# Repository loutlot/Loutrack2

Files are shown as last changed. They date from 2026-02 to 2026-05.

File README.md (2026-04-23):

# Loutrack2

Loutrack2 is an open-source optical motion tracking stack built around Raspberry Pi camera nodes, host-side calibration tools, and a GUI workflow that is already practical for multi-camera bring-up and tracking experiments.

日本語はこちら: [README_ja.md](README_ja.md)

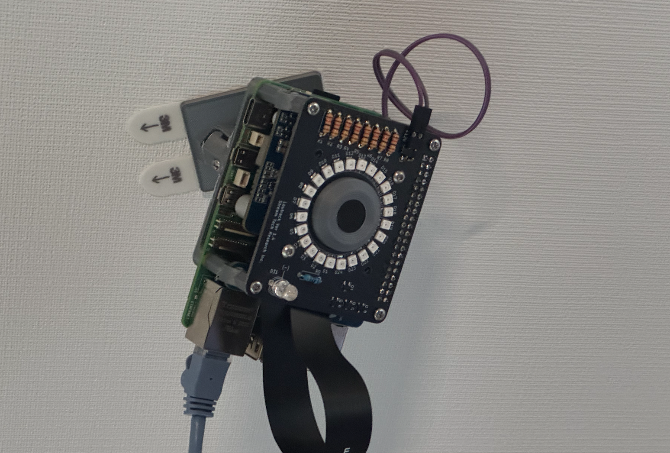
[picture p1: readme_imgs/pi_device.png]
Loutrack Pi device


## What It Is

Loutrack2 combines:

- Raspberry Pi camera capture nodes for reflective marker observation
- host-side control, calibration, and inspection tools
- multi-camera 3D reconstruction and tracking
- a GUI-first workflow for setup, tuning, capture, and review

This repository is aimed at people who want to build, understand, and extend a DIY camera-based tracking system in the open. The current project is strongest in camera bring-up, calibration, and live tracking inspection.

## What Works Today

- Pi capture nodes detect reflective blobs and stream observations to the host
- the host GUI covers blob tuning, mask building, pose capture, floor or metric capture, and extrinsics generation
- intrinsics and extrinsics outputs are generated as JSON artifacts
- synchronized camera observations are reconstructed into 3D marker positions
- the 3D Tracking page shows scene state, camera health, stream diagnostics, and live rigid-body status
- custom rigid bodies can be registered or removed directly from triangulated blobs in the tracking viewer

## System Overview

```mermaid
flowchart LR
  subgraph PiCameras["Raspberry Pi Camera Nodes"]
    A["pi-cam-01<br/>capture_runtime.py"]
    B["pi-cam-02+<br/>capture_runtime.py"]
    C["Blob detection<br/>Mask / Preview / UDP streaming"]
  end

  subgraph Host["Host Workstation"]
    D["loutrack_gui.py<br/>Web GUI"]
    E["UDPReceiver"]
    F["Calibration session"]
    G["Intrinsics / Extrinsics tools"]
    H["Tracking runtime"]
    I["3D reconstruction"]
  end

  subgraph Outputs["Outputs"]
    J["Intrinsics JSON"]
    K["Extrinsics JSON"]
    L["3D marker positions"]
    M["Tracking scene snapshot"]
  end

  A -->|UDP frames| E
  B -->|UDP frames| E
  D -->|TCP control| A
  D -->|TCP control| B
  E --> F
  F --> G
  G --> J
  G --> K
  E --> H
  H --> I
  I --> L
  H --> M
```

## Workflow

The current Loutrack2 experience is centered on a single GUI flow from camera startup to live tracking review.

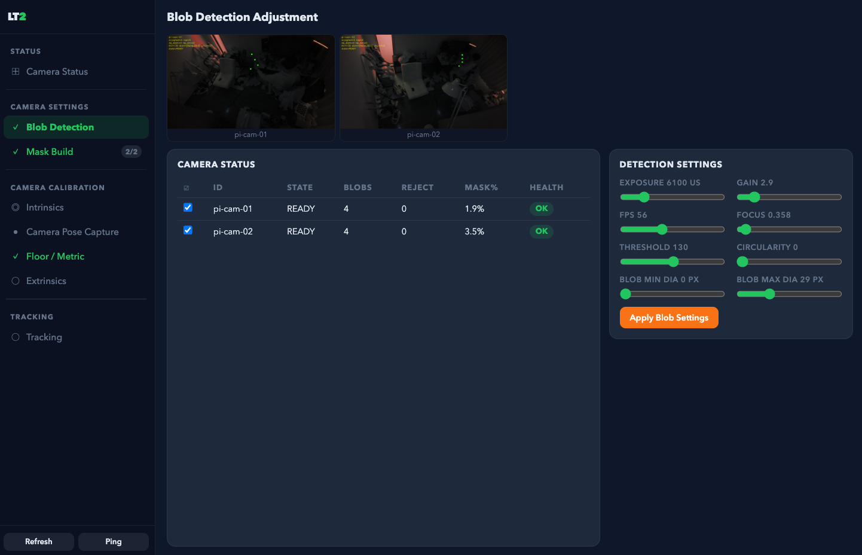
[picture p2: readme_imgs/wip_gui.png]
Loutrack GUI


Typical flow:

1. Start the Pi capture nodes
2. Open the host GUI
3. Tune blob detection
4. Build masks
5. Capture pose data
6. Capture floor or metric data
7. Generate extrinsics
8. Start tracking and inspect the reconstructed scene

The startup and shutdown procedure for Pi nodes and the GUI lives at [`docs/30_procedure/pi_gui_start_stop.md`](docs/30_procedure/pi_gui_start_stop.md).

## Tracking View

The 3D Tracking page is one of the clearest expressions of the project's current direction: operational feedback is visible, rigid bodies can be inspected live, and the scene is meant to be understandable while the system is running.

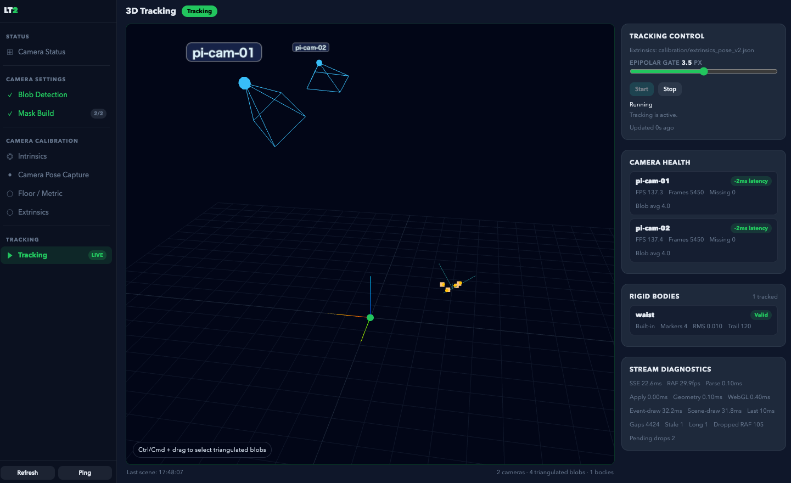
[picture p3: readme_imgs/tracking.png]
Loutrack Tracking


Current highlights:

- live tracking start and stop feedback is surfaced in the GUI
- camera health, latency, and stream diagnostics stay visible beside the scene
- the epipolar gate is adjustable from Tracking Control
- host tracking pairs frames with a fixed `4237us` half-frame window at `118fps`
- the old host-side sync-quality dashboard is gone, keeping tracking focused on scene and camera health
- custom rigid-body registration works directly from triangulated blobs

## Hardware Direction

Loutrack2 also includes an open hardware direction centered around reproducible DIY tracking camera nodes and tracked targets.

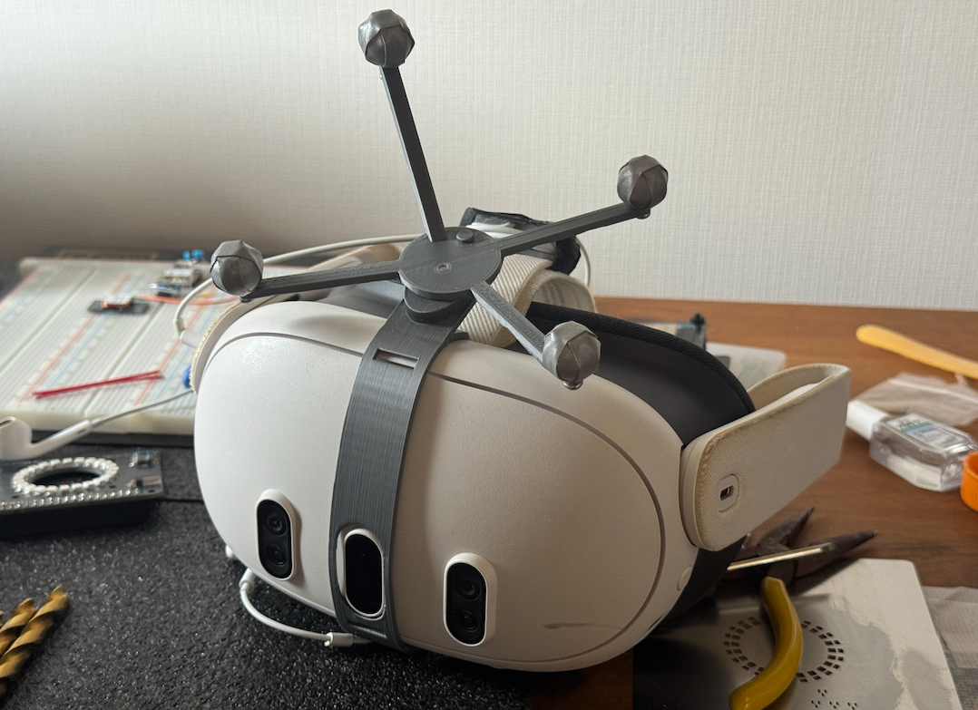
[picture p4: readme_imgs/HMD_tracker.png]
Tracked HMD prototype


Current hardware direction:

- Raspberry Pi-based camera nodes built from commonly available parts
- Raspberry Pi Camera Module 3 Wide NoIR as the current camera baseline
- PoE HAT-based power and networking over a single LAN cable
- a custom board mounted above the Pi that combines camera holding and IR LED illumination
- open hardware files in the repository, including PCB design data and 3D-printable parts
- reflective tracked markers built from 3D-printed spheres and retroreflective tape

Relevant repository areas:

- [`hardware`](hardware) for printable parts and board-related assets
- [`hardware/LED board`](hardware/LED%20board) for the custom LED board design files
- [`hardware/pi mount`](hardware/pi%20mount) for Pi mount printable parts

## Project Direction

Loutrack2 is already useful as a multi-camera optical tracking foundation, but it is still a builder-oriented platform rather than a finished end-user full-body tracker.

The next direction includes:

- more stable rigid-body clustering and identity tracking
- body-part level tracking for head, chest, waist, and feet
- more reliable rigid-body association through the full pipeline
- IK-friendly pose output
- SteamVR tracker output
- continued improvements to deployment, setup, and hardware documentation

## Open Source

Loutrack2 is being developed in the open.

- pull requests are welcome
- forks and experiments are welcome
- documentation, setup improvements, hardware refinements, and calibration workflow improvements are especially useful

## License

This project is intended to be released under `GPL-3.0-or-later`.

## Repository Map

- [`src/pi`](src/pi) for Raspberry Pi capture services
- [`src/deploy`](src/deploy) for Raspberry Pi code deployment, service installation, and rollback helpers
- [`src/host`](src/host) for the host GUI, receiver, runtime, and tracking pipeline
- [`src/camera-calibration`](src/camera-calibration) for intrinsics and extrinsics tooling
- [`src/calibration`](src/calibration) for calibration domain types and targets
- [`calibration`](calibration) for generated calibration artifacts
- [`docs/30_procedure`](docs/30_procedure) for Pi / GUI startup, verification, and shutdown procedures
- [`schema`](schema) for message and control contracts
- [`tests`](tests) for regression coverage

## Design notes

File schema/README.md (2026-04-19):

# schema - JSON Schema定義

Pi↔Host 間メッセージと較正成果物の参照用 JSON Schema。
現状はランタイムでこのディレクトリを直接読みませんが、現行 wire format / 出力形式に合わせて保守します。

## ファイル一覧

### messages.json - Pi→Host フレームメッセージ

PiからHostへ送信されるフレームデータのフォーマット。

```json
{
  "camera_id": "pi-cam-01",
  "timestamp": 1708594800000000,
  "timestamp_source": "sensor_metadata",
  "sensor_timestamp_ns": 123456789,
  "capture_to_process_ms": 3.2,
  "capture_to_send_ms": 4.1,
  "capture_mode": "pose_capture",
  "blob_count": 2,
  "quality": 0.91,
  "blobs": [
    {"x": 100.5, "y": 200.3, "area": 50.0},
    {"x": 300.0, "y": 400.0, "area": 45.0}
  ]
}
```

| フィールド | 型 | 必須 | 説明 |
|---|-----|---|---|
| `camera_id` | string | ✅ | カメラ/Pi識別子 |
| `timestamp` | integer | ✅ | Unix時間 (マイクロ秒, int64) |
| `timestamp_source` | string | | `sensor_metadata` または `capture_dequeue` |
| `sensor_timestamp_ns` | integer | | カメラメタデータのセンサーtimestamp（取得できた場合のみ） |
| `host_received_at_us` | integer | | Host受信時刻。Host receiverがログ用に付与 |
| `capture_to_process_ms` | number | | Pi側 capture handoff からblob処理完了まで |
| `capture_to_send_ms` | number | | Pi側 capture handoff からUDP送信まで |
| `frame_index` | integer | | 互換用フレーム連番。`pose_capture` では送信しない |
| `capture_mode` | string | | `capture` / `pose_capture` / `wand_metric_capture` |
| `blob_count` | integer | | `pose_capture` 時のみ付与される accepted blob 数 |
| `quality` | number | | `pose_capture` 時のみ付与される単点観測 quality |
| `blobs` | array | ✅ | 検出されたマーカーblob配列 |
| `blobs[].x` | number | ✅ | X座標 (ピクセル) |
| `blobs[].y` | number | ✅ | Y座標 (ピクセル) |
| `blobs[].area` | number | ✅ | blob面積 (ピクセル²) |

**ペアリングキー**:
- 主キー: `timestamp` (PTP同期時)
- 互換フォールバック: `frame_index` (`pose_capture` / tracking runtime では使わない)

---

### control.json - Host→Pi 制御メッセージ

HostからPiへ送信する制御コマンド。TCP/JSON (JSON-RPC風)。

**リクエスト形式**:
```json
{
  "request_id": "req-001",
  "camera_id": "pi-cam-01",
  "cmd": "set_exposure",
  "params": {"value": 10000}
}
```

**レスポンス形式**:
```json
{
  "request_id": "req-001",
  "camera_id": "pi-cam-01",
  "ack": true
}
```

| フィールド | 型 | 必須 | 説明 |
|---|-----|---|---|
| `request_id` | string | ✅ | リクエストID (要求/応答マッチング用) |
| `camera_id` | string | ✅ | 対象カメラID (または "broadcast") |
| `cmd` | string | ✅ | コマンド名 |
| `params` | object | | コマンド固有パラメータ |
| `ack` | boolean | ✅ | 受理フラグ (レスポンス時) |
| `error_code` | integer | | エラーコード (ack=false時) |
| `error_message` | string | | エラーメッセージ |

**schema 上のコマンド集合**:
| コマンド | パラメータ | 説明 |
|---|---|---|
| `start` | `mode` | キャプチャ開始 |
| `stop` | - | キャプチャ停止 |
| `set_exposure` | `value` (μs) | 露出時間設定 |
| `set_gain` | `value` | アナログゲイン設定 |
| `set_fps` | `value` | FPS設定 |
| `set_focus` | `value` | フォーカス設定（LensPosition） |
| `set_threshold` | `value` | blob 二値化しきい値（0-255） |
| `set_blob_diameter` | `min_px`, `max_px` | blob 直径pxフィルタ |
| `set_circularity_min` | `value` | blob circularity 下限（0-1） |
| `mask_start` | `threshold`, `seconds`, `hit_ratio?`, `min_area?`, `dilate?` | static mask 構築開始 |
| `mask_stop` | - | static mask 構築停止 |
| `set_preview` | `render_enabled`, `overlays`, `charuco` | MJPEG preview / overlay 制御 |
| `ping` | - | 生存確認 |

補足:
- `control.json` の enum は schema 上の集合で、実際に受理するコマンドは [capture_runtime.py](/src/pi/service/capture_runtime.py) の `SCHEMA_COMMANDS` / `MVP_SUPPORTED_COMMANDS` に従います。
- `led_on` / `led_off` / `set_resolution` は schema enum に残っていますが、現行 MVP では未サポートです。

---

### calibration_intrinsics_v1.json - カメラ内部較正

Charucoボードを使用した内部較正の成果物。

```json
{
  "schema_version": "1.0",
  "camera_id": "pi-cam-01",
  "camera_model": "pinhole",
  "resolution": {"width": 1280, "height": 960},
  "camera_matrix": {
    "fx": 500.0,
    "fy": 500.0,
    "cx": 640.0,
    "cy": 480.0,
    "matrix": [[500, 0, 640], [0, 500, 480], [0, 0, 1]]
  },
  "distortion_coefficients": {
    "k1": -0.01,
    "k2": 0.02,
    "p1": 0.0,
    "p2": 0.0,
    "k3": 0.0,
    "array": [-0.01, 0.02, 0.0, 0.0, 0.0]
  },
  "rms_error": 0.35,
  "captured_at": "2026-02-22T12:00:00",
  "quality": {
    "num_valid_frames": 30,
    "total_points": 1200,
    "pixel_aspect_ratio": 1.0
  }
}
```

| フィールド | 型 | 必須 | 説明 |
|---|-----|---|---|
| `schema_version` | string | ✅ | スキーマバージョン ("1.0") |
| `camera_id` | string | | カメラ識別子 |
| `camera_model` | string | ✅ | 投影モデル ("pinhole" / "fisheye") |
| `resolution` | object | ✅ | 画像解像度 |
| `camera_matrix` | object | ✅ | 内部パラメータ行列 |
| `distortion_coefficients` | object | ✅ | 歪み係数 |
| `rms_error` | number | ✅ | 再投影誤差RMS (目標: <1.0px) |
| `captured_at` | string | ✅ | 較正実施日時 (ISO 8601) |
| `quality` | object | | 品質メトリクス |
| `board` | object | | Charucoボード設定 |

**品質基準**:
| 指標 | 良好 | 許容 |
|---|---|---|
| RMS再投影誤差 | < 0.5 px | < 1.0 px |
| 有効フレーム数 | 40-50 | 25+ |
| Pixel Aspect比 | 0.99-1.01 | 0.95-1.05 |

---

### calibration_extrinsics_v2.json - カメラ外部較正

現行の本流出力は `reference_pose_capture` ベースの `v2` です。
`pose` / `metric` / `world` を top-level で分離して持ちます。

```json
{
  "schema_version": "2.0",
  "method": "reference_pose_capture",
  "created_at": "2026-03-14T20:25:10.710719+00:00",
  "pose_capture_log_path": "logs/extrinsics_pose_capture.jsonl",
  "camera_order": ["pi-cam-01", "pi-cam-02"],
  "pose": {
    "frame": "similarity_camera",
    "camera_poses": [
      {
        "camera_id": "pi-cam-01",
        "R": [[1, 0, 0], [0, 1, 0], [0, 0, 1]],
        "t": [0, 0, 0],
        "focal_scale": 0.88,
        "median_reproj_error_px": 2.57
      }
    ],
    "solve_summary": {
      "usable_rows": 1277,
      "median_reproj_error_px": 2.52
    }
  },
  "metric": {
    "status": "resolved",
    "frame": "metric_camera",
    "scale_m_per_unit": 6.58,
    "source": "wand_floor_metric"
  },
  "world": {
    "status": "resolved",
    "frame": "world",
    "to_world_matrix": [[1, 0, 0, 0], [0, 1, 0, 0], [0, 0, 1, 0], [0, 0, 0, 1]],
    "floor_plane": {"normal": [0, 0, 1], "offset": 0, "axis": "Z"},
    "source": "wand_floor_metric"
  }
}
```

| フィールド | 型 | 必須 | 説明 |
|---|-----|---|---|
| `schema_version` | string | ✅ | スキーマバージョン (`"2.0"`) |
| `method` | string | ✅ | 現在は `reference_pose_capture` |
| `created_at` | string | ✅ | 推定実施日時 (ISO 8601) |
| `pose_capture_log_path` | string | ✅ | 単点 pose capture ログ |
| `camera_order` | array | ✅ | 出力 camera 順序 |
| `pose` | object | ✅ | similarity camera frame の解 |
| `metric` | object | ✅ | scale 解決後の metric frame 情報 |
| `world` | object | ✅ | floor / world 軸アライン後の情報 |
| `wand_metric_log_path` | string | | floor / metric で使った wand log |

### calibration_extrinsics_v1.json - 旧 schema

`v1` は旧 wand 直解き系の参照用として残していますが、現行の `Generate Extrinsics` 出力は `v2` を使います。

---

## バリデーション

```python
import json
from jsonschema import validate

# スキーマ読み込み
with open("schema/messages.json") as f:
    schema = json.load(f)

# メッセージ検証
message = {"camera_id": "pi-01", "timestamp": 123, "blobs": []}
validate(instance=message, schema=schema)
```

## バージョニング

- スキーマ変更時は `$id` と `schema_version` を更新
- 後方互換性を維持 (フィールド追加のみ、削除は不可)
- 破壊的変更時は新規ファイル作成 (e.g., `messages_v2.json`)

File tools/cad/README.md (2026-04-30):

# CAD Tools

Generate first-pass printable marker fixtures from rigid-body marker coordinates.

The main entry point is `tools/cad/rigid_body_fixture.py`. It uses CadQuery to
turn marker-center coordinates into STL files for FDM print trials.

The bundled presets are exploratory coordinates from
`docs/10_in_progress/rigid_body_design.md`; they are useful for validating the
CAD pipeline but are not final manufacturing geometry.

## Setup

```sh
.venv/bin/python -m pip install -r tools/cad/requirements.txt
```

## Default Geometry

The default geometry is:

- 30 mm diameter, 4 mm high central cylinder at the origin.
- 1 mm chamfer on the top edge of the central cylinder.
- A paired hexagonal through-hole 4 mm from center and 5.2 mm round through-hole 10 mm in the opposite direction.
- The hole pair is automatically rotated toward the clearest direction away from stems.
- 14 mm diameter marker spheres at each coordinate.
- Marker centers are lifted 7 mm in Z during generation so marker spheres do not pass below the base bottom.
- 5 mm diameter stems from the closest point on a 25 mm diameter hub circle to each marker center, extended 1 mm into the hub side.
- 5 mm diameter balls on the extended hub-side stem endpoints.
- 1 mm blob-side stem fillets for smoother marker joints.

## Coordinate Handling

Input marker coordinates are interpreted as millimeters.

`--marker-z-lift` is applied only during CAD generation. It does not change the
tracking coordinates stored in docs or calibration data.

The current default `--marker-z-lift 7.0` exists because the marker spheres are
14 mm diameter. Lifting their centers by 7 mm prevents the lower half of a
sphere from going below the base-bottom plane when the source coordinate has a
low Z value.

## Hole Placement

The base has two through-holes:

- Hex hole: center offset 4 mm from origin, circumscribed around a 2.7 mm circle.
- Round hole: center offset 10 mm from origin in the opposite direction, diameter 5.2 mm.

The script chooses the shared hole axis automatically. It samples 0-360 degrees
and scores each candidate by clearance from:

- the base outer radius,
- every stem's XY-projected centerline,
- each stem radius,
- the round-hole radius,
- the hex-hole outer radius.

This is intended to keep the larger round hole from overlapping stems in bodies
such as `left_foot`.

## Generate a Sample STL

```sh
.venv/bin/python -m tools.cad.rigid_body_fixture --preset waist --out output/cad/waist_fixture.stl
```

To also export a CAD-editable STEP file:

```sh
.venv/bin/python -m tools.cad.rigid_body_fixture --preset waist --out output/cad/waist_fixture.stl --step output/cad/waist_fixture.step
```

## Generate All Seed Rigid Bodies

```sh
.venv/bin/python -m tools.cad.rigid_body_fixture --all-presets --out output/cad
```

This writes:

- `output/cad/head_fixture.stl`
- `output/cad/waist_fixture.stl`
- `output/cad/chest_fixture.stl`
- `output/cad/left_foot_fixture.stl`
- `output/cad/right_foot_fixture.stl`

## Custom Input JSON

You can generate from a JSON array:

```json
[
  [18.0, -50.0, 37.5],
  [0.6, 61.8, 20.2],
  [-6.6, -13.0, 63.3]
]
```

Run:

```sh
.venv/bin/python -m tools.cad.rigid_body_fixture --input path/to/body.json --out output/cad/custom_fixture.stl
```

For JSON with multiple bodies, pass `--body`:

```json
{
  "waist": {
    "marker_positions": [
      [18.0, -50.0, 37.5],
      [0.6, 61.8, 20.2],
      [-6.6, -13.0, 63.3]
    ]
  }
}
```

```sh
.venv/bin/python -m tools.cad.rigid_body_fixture --input path/to/bodies.json --body waist --out output/cad/waist_fixture.stl
```

## Useful Options

- `--marker-diameter`: marker sphere diameter in mm. Default: `14.0`.
- `--marker-z-lift`: temporary CAD-only Z lift for marker centers. Default: `7.0`.
- `--stem-diameter`: support stem diameter in mm. Default: `5.0`.
- `--hub-diameter`: circle diameter used for stem start points. Default: `25.0`.
- `--stem-base-extension`: how far each stem extends past the hub-side start point. Default: `1.0`.
- `--base-diameter`: central disk diameter in mm. Default: `30.0`.
- `--base-thickness`: central disk height in mm. Default: `4.0`.
- `--base-top-chamfer`: top-edge C chamfer on the disk. Default: `1.0`.
- `--hex-hole-inscribed-diameter`: circle diameter used to size the hex hole. Default: `2.7`.
- `--round-hole-diameter`: round through-hole diameter. Default: `5.2`.
- `--fillet-radius`: blob-side stem fillet radius. Default: `1.0`.

## Notes

- STL is the normal output for print trials.
- STEP output is optional via `--step`; it is useful for CAD inspection but is
  not generated by the all-presets command unless added later.
- The script is a prototype fixture generator. Confirm clearances, print
  orientation, strength, and marker mounting method before using a generated
  model as final hardware.

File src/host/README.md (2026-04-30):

# src/host - Host側モジュール

loutrack2のHost側Pythonモジュール。UDP受信から剛体推定までの全処理を担当。

## モジュール一覧

### logger.py - フレームログ記録

UDPで受信したフレームをJSONL形式で記録。

```python
from host import FrameLogger

logger = FrameLogger(log_dir="./logs")
logger.start_recording(session_name="test")
logger.log_frame({"camera_id": "pi-01", "timestamp": 12345, ...})
logger.stop_recording()
```

**主要クラス**:
| クラス | 説明 |
|---|---|
| `FrameLogger` | スレッドセーフなフレームロガー |

**主要関数**:
| 関数 | 説明 |
|---|---|
| `list_log_files()` | ログファイル一覧取得 |

---

### replay.py - ログリプレイ

記録したログを再生。

```python
from host import FrameReplay

replay = FrameReplay("logs/test.jsonl")
for frame in replay.replay(realtime=True, speed=2.0):
    process(frame)
```

**主要クラス**:
| クラス | 説明 |
|---|---|
| `FrameReplay` | ログファイルリプレイヤー |
| `FrameEntry` | フレームデータ |
| `EventEntry` | イベントデータ |

**主要関数**:
| 関数 | 説明 |
|---|---|
| `validate_log_integrity()` | ログ整合性検証 |

---

### metrics.py - パフォーマンス監視

FPS、遅延、再投影誤差を収集・エクスポート。

```python
from host import MetricsCollector

metrics = MetricsCollector()
metrics.record_frame("pi-01", timestamp, blob_count=4, received_at=host_received_at)
metrics.record_triangulation(12, [0.5, 0.3, 0.8])
print(metrics.get_summary())
print(metrics.export_prometheus())
```

**主要クラス**:
| クラス | 説明 |
|---|---|
| `MetricsCollector` | メトリクス収集器 |
| `MetricsExporter` | ファイルエクスポート |

---

### receiver.py - UDP受信 + ペアリング

複数PiからのUDPメッセージを受信し、timestampでペアリング。`frame_index` は古いcapture flow向けの互換fallbackで、trackingでは使いません。

```python
from host import FrameProcessor

processor = FrameProcessor(udp_port=5000)
processor.set_paired_callback(on_paired_frames)
processor.start()
```

**主要クラス**:
| クラス | 説明 |
|---|---|
| `Frame` | 受信フレームデータ |
| `PairedFrames` | ペアリング済みフレームセット |
| `FrameBuffer` | カメラごとのフレームバッファ |
| `FramePairer` | timestampベースのペアリング |
| `UDPReceiver` | UDPサーバー |
| `FrameProcessor` | 統合プロセッサ |

**ペアリングロジック**:
- 主キー: `timestamp` (±5ms許容)
- 互換fallback: `frame_index` (tracking runtimeでは無効)
- 診断: raw host receive timeは `host_received_at_us` としてログに残し、Pi timestampとの遅延評価に使います

---

### geo.py - 幾何復元

DLT三角測量と再投影誤差計算。

Tracking runtime の epipolar gate は既定値 `3.5px` で、GUI の Tracking Control から `1.0` から `6.0px` まで `0.5px` 刻みで開始時に指定できます。

```python
from host import Triangulator, create_dummy_calibration

params = create_dummy_calibration(["pi-01", "pi-02"])
triangulator = Triangulator(params)

points_3d = triangulator.triangulate_point(
    image_points=[(100, 200), (150, 180)],
    camera_ids=["pi-01", "pi-02"]
)
error = triangulator.compute_reprojection_error(image_points, points_3d, camera_ids)
```

**主要クラス**:
| クラス | 説明 |
|---|---|
| `CameraParams` | カメラパラメータ (内外因) |
| `CalibrationLoader` | 較正ファイル読み込み |
| `Triangulator` | DLT三角測量 |
| `GeometryPipeline` | 幾何処理パイプライン |

**主要関数**:
| 関数 | 説明 |
|---|---|
| `create_dummy_calibration()` | テスト用ダミー較正生成 |
| `undistort_points()` | 歪み補正 |

---

### rigid.py - 剛体推定

DBSCANクラスタリング + Kabschアルゴリズムによる剛体姿勢推定。
`max_rms_error_m=0.055` を超える rigid-fit は tracking の valid pose として採用しません。

```python
from host import RigidBodyEstimator, WAIST_PATTERN

estimator = RigidBodyEstimator(patterns=[WAIST_PATTERN])
poses = estimator.process_points(points_3d, timestamp)
print(poses["waist"].position)
print(poses["waist"].quaternion)
```

**主要クラス**:
| クラス | 説明 |
|---|---|
| `MarkerPattern` | 剛体マーカー配置定義 |
| `RigidBodyPose` | 推定された剛体姿勢 |
| `PointClusterer` | DBSCANクラスタリング |
| `KabschEstimator` | SVDベース剛体姿勢推定 |
| `RigidBodyTracker` | 時間追跡・予測 |
| `RigidBodyEstimator` | 統合パイプライン |

**定義済みパターン**:
| パターン | マーカー数 | 説明 |
|---|---|---|
| `WAIST_PATTERN` | 4 | ウエスト（既存デザイン） |
| `HEAD_PATTERN` | 4 | ヘッド |
| `CHEST_PATTERN` | 4 | 胸 |
| `LEFT_FOOT_PATTERN` | 4 | 左足先 |
| `RIGHT_FOOT_PATTERN` | 4 | 右足先 |

---

### pipeline.py - 統合パイプライン

全モジュールを統合したエンドツーエンドパイプライン。

```python
from host import TrackingPipeline

pipeline = TrackingPipeline(
    udp_port=5000,
    calibration_path="./calibration/",
    enable_logging=True
)

def on_pose(poses):
    for name, pose in poses.items():
        if pose.valid:
            print(f"{name}: {pose.position}")

pipeline.set_pose_callback(on_pose)
pipeline.start()
# ... 実行中 ...
pipeline.stop()
```

**主要クラス**:
| クラス | 説明 |
|---|---|
| `TrackingPipeline` | UDP→三角測量→剛体推定パイプライン |
| `TrackingSession` | セッション管理・ポーズ履歴 |

---

### tracking_runtime.py - GUI向け tracking runtime

`TrackingPipeline` を GUI 利用向けにラップし、start/stop/status/scene snapshot を提供。
camera frustum近接面のコーナー計算、rigid markerのworld変換、簡易trail保持を担当。

**主要クラス/関数**:
| 名前 | 説明 |
|---|---|
| `TrackingRuntime` | GUI向けランタイムラッパー |
| `compute_frustum_near_corners_world()` | frustum近接面4点をworldで計算 |
| `compute_markers_world()` | rigid markerをlocal->world変換 |

### wand_session.py - calibration収録オーケストレーション

Host主導で `ping -> set_exposure/set_gain -> mask_start -> start(mode=pose_capture|wand_metric_capture, start_at_us=<PTP epoch us>) -> stop` を実行。
`start_at_us` 付きの `start` は約 1 秒先にスケジュールされ、対象 Pi へ並列送信されるため、PTP lock 済みの複数 Pi が同じ目標時刻で UDP stream を開始できる。
`hosts.ini` と `UDPReceiver.get_camera_addresses()` をマージして対象カメラを確定。

```python
from src.host.wand_session import CalibrationSession, CalibrationSessionConfig

session = CalibrationSession()
result = session.run_session(
    CalibrationSessionConfig(exposure_us=8000, gain=8.0, duration_s=60.0)
)
print(result["session_id"])
```

**主要クラス/定数**:
| 名前 | 説明 |
|---|---|
| `CalibrationSession` | 収録制御の実行クラス（新正規名） |
| `CalibrationSessionConfig` | 収録パラメータ（新正規名） |
| `WAND_POINTS_MM` | wand 4点の固定3D座標（mm） |

---

### loutrack_gui.py - 映像なし Web GUI（新正規入口）

同期スライダー（exposure/gain）と `ping` / `mask_start` / `pose_capture` / `wand_metric_capture` / `Generate Extrinsics` をブラウザから操作する最小 GUI。fps は 118 固定で、pair window は half-frame bound の `4237us` に固定されます。tracking 側の host sync-quality dashboard は廃止され、tracking と extrinsics capture の stream start は PTP/epoch `start_at_us` による countdown start を使います。
`UDPReceiver` を起動して受動発見し、`CalibrationSession` の inventory merge をそのまま利用する。

```bash
python3 src/host/loutrack_gui.py --host <HOST_IP> --port 8765
```

ブラウザで `http://<HOST_IP>:8765/` を開く。

床置き wand の短時間収録だけを CLI で行う場合:

```bash
.venv/bin/python src/host/auxiliary/capture_wand_floor.py \
  --output logs/extrinsics_wand_metric.jsonl \
  --duration-s 3.0
```

---

### visualize.py - 可視化

コンソール出力とファイルエクスポート。

```python
from host import TrackingVisualizer, SimpleGraph

visualizer = TrackingVisualizer(output_dir="./output")
visualizer.start_session("test")
visualizer.visualize_poses(poses, timestamp, metrics)
visualizer.end_session()

# グラフ
graph = SimpleGraph(width=60, height=10)
for error in errors:
    graph.add_value(error)
print(graph.render("RMS Error"))
```

**主要クラス**:
| クラス | 説明 |
|---|---|
| `TrackingVisualizer` | ポーズ可視化 |
| `SimpleGraph` | ASCII時系列グラフ |

---

## データフロー

```
UDP受信 (receiver.py)
    ↓ Frame
ペアリング (receiver.py: FramePairer)
    ↓ PairedFrames
三角測量 (geo.py: Triangulator)
    ↓ points_3d
クラスタリング (rigid.py: PointClusterer)
    ↓ clusters
剛体推定 (rigid.py: KabschEstimator)
    ↓ RigidBodyPose
出力 (visualize.py, logger.py)
```

## スレッド安全性

以下のクラスはスレッドセーフ:
- `FrameLogger`
- `FrameBuffer`
- `MetricsCollector`
- `RigidBodyTracker`
- `TrackingSession`

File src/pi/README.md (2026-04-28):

# Pi キャプチャサービス

`src/pi/service/capture_runtime.py` が Raspberry Pi 側キャプチャサービスの正規入口です。

- TCP 制御 (NDJSON): `0.0.0.0:8554`
- UDP フレーム (1 データグラムにつき 1 つの JSON): デフォルト `255.255.255.255:5000`
- デフォルトバックエンド: Raspberry Pi では `picamera2`、それ以外では `dummy`
- 前提カメラ: `Raspberry Pi Camera Module 3 Wide NoIR`
- 固定キャプチャモード: `1536x864 @ 118fps`
- 起動時のログはリスンアドレス、バックエンド、プレビュー状態、キャプチャ開始/停止ステータスを出力します
- UDP ペイロードは `timestamp_source` と capture-to-process/send 診断値を含みます。`pose_capture` では同期キーとして信用しない `frame_index` を送信しません
- runtime diagnostics の `camera_controls` には、要求した `FrameDurationLimits`、最後に Picamera2 が受理した `FrameDurationLimits`、control 適用の成功/失敗回数が含まれます

正規モジュール:

- `pi.service.capture_runtime`

## 初回インストール

Fresh Raspberry Pi OS から Loutrack camera node を作る手順は [`INSTALL.md`](INSTALL.md) にあります。

最初は Raspberry Pi Imager で username を `pi`、hostname / camera id を `pi-cam-01`, `pi-cam-02` のように揃えるのがおすすめです。

## ローカルで実行（ダミーバックエンド）

macOS / Linux での開発用です。合成されたドットフレームを生成します。

```bash
.venv/bin/python src/pi/service/capture_runtime.py \
  --backend dummy \
  --camera-id pi-cam-01 \
  --udp-dest localhost:5000
```

## Raspberry Pi 上で実行（デフォルトで picamera2 バックエンド）

Raspberry Pi OS では `picamera2` がデフォルトのバックエンドです。`--backend picamera2` は省略可能です。

```bash
.venv/bin/python src/pi/service/capture_runtime.py \
  --camera-id pi-cam-01 \
  --udp-dest 255.255.255.255:5000
```

`--mjpeg-port` は既定で `8555` です。`http://<PI_IP>:8555/mjpeg` で headless のまま確認できます。
無効化したい場合だけ `--mjpeg-port 0` を指定します。

Pi 本体でローカルに OpenCV デバッグプレビューを表示したい場合は、マスク設定中やワンドキャプチャ中、アイドル時に `--debug-preview` を付けます。

```bash
.venv/bin/python src/pi/service/capture_runtime.py \
  --camera-id pi-cam-01 \
  --udp-dest 255.255.255.255:5000 \
  --debug-preview
```

SSH 経由でキャプチャを開始する場合は、事前にデスクトップ X ディスプレイをエクスポートしてください。

```bash
export DISPLAY=:0
export XAUTHORITY=/home/pi/.Xauthority
```

プレビューはデバッグ用のみです。サービスは single camera pipeline で動き、idle / mask build / capture のすべてが同じ backend から処理されます。OpenCV HighGUI は専用 preview thread だけが触り、preview は同じウィンドウを継続利用します。高負荷時は preview frame を drop して capture を優先します。`DISPLAY` が設定されていない場合、サービスはウィンドウを表示しないようにプレビューを無効化し、OpenCV HighGUI に触れずに実行を続行します。

MJPEG サーバー起動と描画負荷は分離されています。起動直後は MJPEG render が OFF で、`set_preview` API で ON/OFF を切り替えます。

```bash
PYTHONPATH=src .venv/bin/python -m host.control \
  --ip <PI_IP> \
  --camera-id pi-cam-01 \
  set_preview \
  --render-enabled true
```

描画 ON 時は OpenCV preview と同じ blob/mask/text overlay を MJPEG へ反映し、必要なら Charuco overlay も重畳できます。

`start` は `capture` / `pose_capture` / `wand_metric_capture` の全 mode で static mask を必須にします。つまり `Build Mask` 実行後に `READY` へ入っていることが開始条件です。mask は `mask_start` 中の生成処理を除き常時適用されます。任意の `start_at_us` パラメータを渡すと、Pi は PTP 同期済みの epoch microsecond clock でその時刻まで待ってから stream を開始します。

`pose_capture` は full detection を維持し、UDP payload でも full blobs をそのまま送ります。`blob_count` と `quality` は additive metadata として付与し、single-blob row の採否は host 側が `blob_count` と `len(blobs)` を見て判断します。

`picamera2` が利用できない環境でも、サービスは動作し続けます（例: `ping` は引き続き機能）。`start` は `ack:false` と `error_code=6` を返します。

## 1 コマンドでできる PTP 設定

Loutrack の固定トポロジー向けに、`src/pi/setup_ptp.sh` は `linuxptp` をインストールし、`systemd-timesyncd` を無効化し、ロール別の systemd ユニットを作成して即座に起動します。master では boot 時に一度だけ NTP で wall clock を寄せてから PTP を開始する bootstrap service も入ります。supported path は `software` timestamping です。

### Master (pi-cam-01) 設定

```bash
sudo ./src/pi/setup_ptp.sh master
```

### Slave（他の Pi カメラ）設定

```bash
sudo ./src/pi/setup_ptp.sh slave
```

第二引数を指定するとインターフェース名を上書きできます。第三引数で `software|hardware` を選べます。

```bash
sudo ./src/pi/setup_ptp.sh slave eth0 software
sudo ./src/pi/setup_ptp.sh slave eth0 hardware
```

`software` モードでは `loutrack-ptp4l.service` だけを起動します。`loutrack-phc2sys.service` は作成しません。
`hardware` は実験用オプションとして残していますが、現行の標準運用には含めません。

スクリプトが作成するファイル:

- `/etc/linuxptp/loutrack-ptp.conf`
- `/etc/systemd/system/loutrack-ptp4l.service`
- `/etc/systemd/system/loutrack-phc2sys.service`

標準の software 運用でのステータス確認例:

```bash
systemctl status loutrack-ptp4l.service
/usr/sbin/pmc -u -b 0 -s /var/run/ptp4lro -i /tmp/pmc.readme "GET TIME_STATUS_NP"
```

## PTP 設定の巻き戻し

Loutrack が作成した PTP 設定を全部戻すには、`src/pi/revert_ptp.sh` を実行します。

```bash
sudo ./src/pi/revert_ptp.sh
```

このスクリプトは:

- `loutrack-ptp4l.service` / `loutrack-phc2sys.service` を停止して disable
- `/etc/systemd/system/` の Loutrack unit を削除
- `/etc/linuxptp/loutrack-*` を削除
- `systemd-timesyncd` を再度 enable/start
- `timedatectl set-ntp true` で NTP を戻す

`linuxptp` パッケージ自体は削除しません。再セットアップや手動検証で再利用できるように残します。

## Master 用の手動 NTP 復旧

`setup_ptp.sh master` は boot 時に一度だけ NTP bootstrap を挟むため、通常の起動では手動介入なしで `pi-cam-01` の wall clock を寄せてから PTP が始まります。それでも絶対時刻が怪しい場合は、capture 前に `src/pi/manual_ntp_sync.sh` を手動で実行します。

```bash
sudo ./src/pi/manual_ntp_sync.sh
```

このスクリプトは:

- `loutrack-ptp4l.service` と `loutrack-phc2sys.service` を停止
- `systemd-timesyncd` を一時的に有効化して NTP 同期
- `NTPSynchronized=yes` を待機
- `systemd-timesyncd` を再度停止
- Loutrack の PTP service を存在するものだけ再起動

常用ではなく、長期停止後や wall clock が怪しいときの手動復旧専用です。

## タイムスタンプと PTP

`timestamp` は露光に合わせた最良の Unix エポック（マイクロ秒）として出力されます。

- `timestamp_source="sensor_metadata"`: `picamera2` のメタデータがセンサータイムスタンプを提供し、`capture_runtime.py` がエポック時間に変換します
- `timestamp_source="capture_dequeue"`: メタデータが無いまたは無効な場合、フレームキューからデキューした直後のクロック読み取りをフォールバックとして使用します
- `capture_to_process_ms` / `capture_to_send_ms`: Pi 内部で古いフレームが詰まっていないかをHost側で診断するための経過時間です

PTP は Raspberry Pi 実行時の OS レベルの前提条件です。

- `pi-cam-01` が固定 Grandmaster です
- それ以外の Pi カメラは PTP クライアントです
- `capture_runtime.py` は PTP サービスの起動/再起動を行いません
- `ping` は `pmc` を read-only UDS socket 経由で用いてベストエフォートで PTP 健全性を取得し、結果を 60 秒間キャッシュします

### 必要な Pi パッケージ（ハイレベル）

- `picamera2`（Python）
- `libcamera` スタック（システム）
- `linuxptp`（システム、`ptp4l` / `phc2sys` / `pmc` を提供）
- `numpy`, `opencv-python`（Python、リポジトリの requirements に合わせ）

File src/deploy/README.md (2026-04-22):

# deploy - Raspberry Pi デプロイスクリプト

SSH/rsyncベースのRaspberry Pi配布・管理ツール。

## 概要

このディレクトリには、複数台のRaspberry Piへのアプリケーション配布、更新、ロールバックを行うスクリプトが含まれています。

## ファイル構成

```
src/deploy/
├── hosts.ini       # Piインベントリ (IP/camera_id)
├── deploy.sh       # デプロイスクリプト
├── rollback.sh     # ロールバックスクリプト
└── README.md       # このファイル
```

## 前提条件

### 1. SSH鍵の準備

```bash
# デプロイ用SSH鍵を生成
ssh-keygen -t ed25519 -f ~/.ssh/loutrack_deploy_key -N ""

# 各Piに公開鍵を登録
ssh-copy-id -i ~/.ssh/loutrack_deploy_key.pub pi@<PI_IP_01>
ssh-copy-id -i ~/.ssh/loutrack_deploy_key.pub pi@<PI_IP_02>
```

### 2. Pi側の準備

各Raspberry Piで以下を設定:

```bash
# runtime / PTP prerequisites
sudo apt-get update
sudo apt-get install -y linuxptp python3-opencv python3-numpy

# ディレクトリ作成
sudo mkdir -p /opt/loutrack/releases
sudo chown pi:pi /opt/loutrack
```

`deploy.sh` は `/opt/loutrack/releases/<version>/src/pi/` と `/opt/loutrack/releases/<version>/src/camera-calibration/` へローカルと同じ `src` 構造で配布し、`hosts.ini` の `camera_id` を使って `/etc/systemd/system/loutrack.service` を作成/更新してから起動します。

PTP はアプリとは別に OS/service レイヤで常時追従させます。

- `pi-cam-01` を fixed Grandmaster とする
- 他 Pi は PTP client として同期する
- `capture.py` は `pmc` で状態参照するだけで、`ptp4l` / `phc2sys` の起動・再起動は行わない

### 3. sudo権限の設定

```bash
# piユーザーがパスワードなしでサービスを再起動できるように
sudo echo "pi ALL=(ALL) NOPASSWD: /usr/bin/systemctl restart loutrack.service" >> /etc/sudoers.d/loutrack
```

## hosts.ini の書き方

```ini
# hostname    ip_address         camera_id
pi-cam-01     <PI_IP_01>       pi-cam-01
pi-cam-02     <PI_IP_02>       pi-cam-02
pi-cam-03     <PI_IP_03>       pi-cam-03
```

- `#` で始まる行はコメントとして無視
- 各フィールドはスペース/タブ区切り
- `hostname`: 識別用名前 (任意)
- `ip_address`: PiのIPアドレス
- `camera_id`: カメラ識別子の文字列。メッセージ/制御で使用します。

## デプロイ手順

### 基本的なデプロイ

```bash
# リポジトリルートから実行
./src/deploy/deploy.sh
```

`src/deploy` からも実行できます。

### オプション

```bash
# ドライラン (実際には変更しない)
./src/deploy/deploy.sh --dry-run

# 順次実行 (デバッグ用)
./src/deploy/deploy.sh --no-parallel

# バージョンタグ指定
./src/deploy/deploy.sh --version v1.2.3
```

### デプロイの動作

1. `hosts.ini` を読み込み
2. 各Piに `/opt/loutrack/releases/<timestamp>/` を作成
3. `rsync --delete` で `src/pi/` と `src/camera-calibration/` を release 内の `src/` 配下へミラーリング（`__pycache__` と `.pyc` は除外し、service でも bytecode 生成を止めます）
4. `current` シンボリックリンクを新リリースに切り替え (atomic)
5. `loutrack.service` を再起動
6. 古いリリースを削除 (直近3世代のみ保持)

## ロールバック手順

```bash
# 前のバージョンに戻す
./src/deploy/rollback.sh
```

### ロールバックの動作

1. 各Piで現在の `current` リンク先を確認
2. 2番目に新しいリリースを特定
3. `current` リンクを切り替え
4. `loutrack.service` を再起動

## ディレクトリ構造 (Pi側)

```
/opt/loutrack/
├── current -> releases/20260222_120000/  # シンボリックリンク
└── releases/
    ├── 20260222_120000/  # 最新
    │   └── src/
    │       ├── pi/
    │       └── camera-calibration/
    ├── 20260222_100000/  # 1つ前
    └── 20260221_180000/  # 2つ前
```

## トラブルシューティング

### SSH接続エラー

```bash
# 接続テスト
ssh -i ~/.ssh/loutrack_deploy_key pi@<PI_IP_01>

# known_hostsに追加
ssh-keyscan <PI_IP_01> >> ~/.ssh/known_hosts
```

### 権限エラー

```bash
# Pi側で所有権を確認
ls -la /opt/loutrack/

# 必要に応じて修正
sudo chown -R pi:pi /opt/loutrack/
```

### サービスが起動しない

```bash
# ログを確認
sudo journalctl -u loutrack.service -f

# ステータス確認
sudo systemctl status loutrack.service
```

### ロールバックできない

```bash
# リリース一覧を確認
ls -la /opt/loutrack/releases/

# 手動で切り替え
ln -sfn /opt/loutrack/releases/20260221_180000 /opt/loutrack/current
sudo systemctl restart loutrack.service
```

## Ansible移行の判断基準

現在のSCP/SSHベースで問題が発生した場合、Ansible移行を検討:

| 条件 | 推奨 |
|---|---|
| Pi台数 > 4台 | Ansible推奨 |
| 更新頻度 > 週2回 | Ansible推奨 |
| 設定変更が多い | Ansible推奨 |
| 台数 2-4台、更新は週1以下 | SCP/SSH継続 |

### Ansible移行時

```yaml
# playbook.yml (例)
- hosts: pi_cameras
  tasks:
    - name: Sync loutrack code
      synchronize:
        src: ../pi/
        dest: /opt/loutrack/current/
        delete: yes
    - name: Restart service
      systemd:
        name: loutrack.service
        state: restarted
```

## ログ

- `src/deploy/deploy.log` - デプロイログ
- `src/deploy/rollback.log` - ロールバックログ

```bash
# ログをリアルタイムで確認
tail -f src/deploy/deploy.log
```

## Piサービス統合の整合
このセクションは、新しいPiサービス環境にデプロイ構成と制御プロトコルを統合するためのポイントをまとめたものです。

- エントリポイント: Pi 側のキャプチャ処理は `/opt/loutrack/current/src/pi/service/capture_runtime.py` を使用します。
- TCP 制御 NDJSON ポート: 8554 をデフォルトとして、制御コマンドは PYTHONPATH=src .venv/bin/python -m host.control ... 形式で実行します。
- UDP フレーム: Pi から Host へ送信される各データグラムは JSON 形式。デフォルトのブロードキャスト先は 255.255.255.255:5000 です。
- UDP フレーム: `timestamp_source` と capture-to-process/send 診断値を含みます。`timestamp` は露光寄りの epoch(us) を優先し、`pose_capture` では `frame_index` を送信しません。
- systemd の例: capture_runtime.py を引数付きで実行するか、EnvironmentFile を用いて環境変数を読み込む形で起動します。
- src/deploy/hosts.ini の camera_id: 文字列で pi-cam-01 等を使用します。
- 未実装/検討中: mask/LED の制御欄は現時点では未実装、または今後の計画として記載します。
- 参照: docs/00_pre_implementation/pi_control_transport.md に制御プロトコルの詳細を記載しています。

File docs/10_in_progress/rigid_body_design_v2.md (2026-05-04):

# Rigid Body Design V2 Plan

## Purpose

This plan defines an end-to-end route for finding manufacturable 5-marker rigid-body designs that improve identity stability and live performance in the current multi-rigid tracking pipeline.

The current direction from `docs/10_in_progress/rigid_body_design.md` remains valid:

- Use 5 markers per rigid body.
- Do not accept arbitrary `3-of-5` or `4-of-5` subsets.
- Store `strong_4_subsets` and `strong_3_subsets` as part of the rigid definition.
- Treat `3-of-5` as prediction confirmation, not as an independent BOOT or REACQUIRE pose source.

V2 does not replace that policy. It extends the design process so that candidate coordinates are scored against the real 4-camera projection, current object-gating behavior, body-mounted occlusion failures, and 118fps performance budget.

## Current Evidence

The design and sim logs point to the same failure mode:

- Full 5-marker observations are much stronger than the built-in 4-marker patterns.
- Arbitrary partial subsets are still unsafe.
- The hard body-mounted scenario still exposes marker identity ambiguity under high noise.
- Recent object-gating improvements reduce but do not eliminate the need for better marker geometry.
- Performance is now close to budget, so design changes should reduce ambiguity-triggered work rather than add more guard logic.

Relevant references:

- Design policy and first 5-marker subset search: `docs/10_in_progress/rigid_body_design.md`
- Body-mounted sim and object-gating PDCA: `docs/10_in_progress/sim_performance_upgrade_log_v2.md`
- Simulator usage: `docs/40_tools/multi_rigid_simulator.md`

## 2026-05-03 PDCA Status

Baseline measurement:

- `tests/test_pattern_evaluator.py` passed before edits.
- Current `design_5marker_seed` failed Gate 2: worst full cross `16.30mm`, no body reached a strong `4-of-5` subset under the V2 target set, and several bodies missed the `35mm` spacing floor.

Cycle log:

| cycle | hypothesis | change | result | decision | next action |
|---:|---|---|---|---|---|
| 1 | Subset-aware geometry JSON will make Gate 2 measurable before sim. | Extended `src/host/pattern_evaluator.py` with Gate 2 metrics, strong subset metadata, nearest-neighbor details, and weak-subset reasons. | Unit tests passed; current seed reported no Gate 2 pass. | Keep evaluator changes. | Add repeatable candidate search. |
| 2 | A simple mutation search can produce stored candidate JSON for later sim references. | Added `tools/rigid_body_design_search.py`. | Initial smoke found candidates but script import path failed when run directly. | Fix command portability. | Make script executable from repo root. |
| 3 | Direct script path setup will unblock search runs. | Added repo-root and `src` path setup inside the tool. | 100-iteration search wrote JSON, but scoring kept low-spacing baseline too high. | Search tool works; scoring needs physical-constraint weighting. | Penalize spacing failures and add random restarts. |
| 4 | Gate-target scoring plus random restarts will surface manufacturable layouts. | Reweighted score around full cross, subset floor, and marker spacing; rejected mutations below `35mm`. | 2000-iteration run improved spacing and full cross, but still failed Gate 2. | Continue; evaluator was over-rejecting high-margin edge-similar subsets. | Treat repeated-edge symmetry as a hard weak reason only when margin is thin. |
| 5 | Edge-similarity should not reject a subset whose ambiguity margin is already strong. | Relaxed repeated-edge / near-isosceles rejection to low-margin cases and lowered the 4-point volume floor. | 500-iteration run produced strong subsets for `waist` and `right_foot`; best candidate still failed due `head`, `chest`, `left_foot`, and full-cross margins. | Gate 2 is not achieved yet; implementation progress is usable, final design is not frozen. | Run a longer body-specific search that mutates the current worst body first, then add Gate 3 projection scoring. |

Current artifacts:

- Candidate search summaries: `logs/design/rigid_body_v2/candidates_pdca_cycle2/`, `logs/design/rigid_body_v2/candidates_pdca_cycle3/`, `logs/design/rigid_body_v2/candidates_pdca_cycle4/`, `logs/design/rigid_body_v2/candidates_pdca_cycle5/`
- Best Cycle 5 result: Gate 2 failed, worst full cross `15.36mm`, worst best-subset score `7.81mm`, min marker spacing `35.97mm`.

## 2026-05-04 PDCA Status

Strategy shift:

- Stop full-population random mutation once a partial win appears.
- Continue from the best stored JSON candidate.
- Mutate the weakest / failing bodies first, while preserving bodies that already pass.
- Treat projection screening as a separate gate before spending full sim runs.

Cycle log:

| cycle | hypothesis | change | result | decision | next action |
|---:|---|---|---|---|---|
| 6 | Body-specific mutation will preserve good bodies and lift the weak body floor. | Added `--seed-candidate` and `--focus-worst-rate` to `tools/rigid_body_design_search.py`. | Best candidate improved worst full cross to `19.41mm` and worst best-subset score to `10.44mm`, but still failed Gate 2. | Keep focused search; remaining failures are narrow. | Relax repeated-edge hard rejection when margin itself is above target. |
| 7 | Edge repetition should be diagnostic, not a hard fail, when subset margin already passes. | Adjusted evaluator rejection reasons and reran focused search. | `candidate_00389` passed Gate 2: worst full cross `20.06mm`, worst best-subset score `10.36mm`, min spacing `35.99mm`. | Gate 2 is achieved. | Add projection screen before sim. |
| 8 | A lightweight projection screen can catch 2D regressions before sim. | Added `tools/rigid_body_projection_screen.py`; compared Gate 2 best against current seed for 120 frames. | p05 separation improved by `3.64px`, subset area improved, but one worst pair was `0.003px` below baseline. | Need close-pair diagnostics and longer frame window. | Add worst-pair reporting and run 240-frame projection. |
| 9 | The strict projection fail may be a single close-pair artifact. | Added worst-pair metadata and reran 240 frames. | Worst pair improved, but `waist` strong-3 projected area collapsed below baseline in late frames. | Do not promote rank 0. | Sweep the Gate 2 top candidates through projection. |
| 10 | Another Gate 2 pass candidate may project better without more search. | Swept top 10 Cycle 7 candidates through 120 and 240-frame projection screens. | `candidate_00252` passed Gate 2 and 240-frame projection: p05 `+2.26px`, worst pair `+0.08px`, worst strong subset area `+0.25px²`. | Promote `candidate_00252` to Gate 4 entry candidate. | Export it as sim-readable custom rigids and run green smoke. |
| 11 | Sim can validate `candidate_00252` once custom body rigids override the built-in design seed. | Let `tools/sim` override body rigids from `custom_rigids` and exported `logs/design/rigid_body_v2/candidate_00252_tracking_rigids.json`. | Relaxed seed45/noise0.05 smoke had wrong/confusion `0/0`, but `left_foot` valid was `0.0`; default baseline on the same current tree also had poor `left_foot` validity. | Gate 4 is blocked by current sim/runtime baseline instability, not yet by candidate rejection. | First restore/diagnose baseline relaxed green validity, then rerun candidate sim matrix. |

Current promoted candidate:

- Candidate JSON: `logs/design/rigid_body_v2/candidates_pdca_cycle7/rank_02_candidate_00252.json`
- Sim custom rigids: `logs/design/rigid_body_v2/candidate_00252_tracking_rigids.json`
- Projection report: `logs/design/rigid_body_v2/projection_pdca_cycle10_sweep_240/rank_02/summary.json`

Gate 2 metrics for `candidate_00252`:

| metric | value |
|---|---:|
| worst full cross | `20.26mm` |
| worst best-subset score | `9.70mm` |
| min marker spacing | `35.99mm` |

Gate 3 lightweight metrics for `candidate_00252` over 240 frames:

| metric vs current seed | delta |
|---|---:|
| marker pair p05 | `+2.26px` |
| worst marker pair | `+0.08px` |
| worst strong subset area | `+0.25px²` |

## 2026-05-04 Continued PDCA Status

Strategy shift:

- Treat Gate 2/3 as necessary but not sufficient.
- Add a sim BOOT smoke before promoting a candidate to the full matrix.
- Fix runtime hold behavior when ownership safety rejects a candidate after a short valid run.
- Prefer candidate-specific runtime overrides over global guard changes when current seed shows side effects.

Cycle log:

| cycle | hypothesis | change | result | decision | next action |
|---:|---|---|---|---|---|
| 12 | The relaxed baseline failure is either missing observations or a runtime ownership/acquire issue. | Checked generated ownership and tracking summaries. | True `left_foot` blobs existed in all frames; failures were `frame_local_blob_ownership_conflict` or no valid BOOT candidate. | Runtime/acquire path is the blocker, not blob generation. | Handle ownership conflicts without committing wrong blobs. |
| 13 | If a tracked body loses a frame-local ownership contest, holding prediction is safer than invalidating it. | Added prediction hold for `frame_local_blob_ownership_conflict` when the tracker already has a valid prediction. | `left_foot` improved from near-zero valid to `0.22`, wrong/confusion stayed `0/0`. | Direction is useful but incomplete. | Let explicit prediction-hold candidates bypass reacquire measurement rejection. |
| 14 | `tracked_rigid_*_hold_prediction` should not be treated as a failed reacquire measurement. | Updated prediction-hold candidate application to commit as hold, not strict reacquire. | At correct `118fps`, relaxed baseline seed45/noise0.05 reached all-body valid `1.0`, wrong/confusion `0/0`, trimmed p95 `4.88/1.43ms`. | Baseline green restored; earlier `60fps` CLI readings were not comparable. | Re-test promoted candidates at `118fps`. |
| 15 | `candidate_00252` should now pass relaxed sim if Gate 2/3 were sufficient. | Ran relaxed seed45/noise0.05 with custom rigids. | `left_foot` valid stayed `0.0`; BOOT explained only 3 markers and failed guard. | Gate 2/3 pass is not enough. | Sweep Gate 2 candidates through sim BOOT smoke. |
| 16 | Another Gate 2 candidate may be more BOOT-compatible. | Swept Cycle 7 top 10 candidates through relaxed seed45/noise0.05 at `118fps`. | `candidate_00534` reached all-body valid `1.0`, wrong/confusion `0/0`, trimmed p95 `4.89/1.45ms`. | Promote `candidate_00534`. | Run relaxed green seeds. |
| 17 | `candidate_00534` should hold relaxed green across seeds. | Ran relaxed seeds `45/46/47`, 240 frames, noise `0.05px`. | All seeds all-body valid `1.0`, wrong/confusion `0/0`, trimmed p95 about `4.9/1.43ms`. | Relaxed green passes. | Run hard green. |
| 18 | Hard green will expose whether whitelist coverage is enough. | Ran hard seeds `45/46/47`, noise `0.05px`. | wrong/confusion `0/0`, but `waist` valid dropped to `0.90-0.92`. | Candidate geometry is viable but waist whitelist is too narrow for hard occlusion. | Inspect hard missing subsets. |
| 19 | Adding waist `[0,2,3,4]` may cover hard occlusion. | Added waist strong4 `[0,2,3,4]`. | No meaningful change. | Wrong missing subset. | Inspect frame-level invalid reasons. |
| 20 | Adding waist `[0,1,2,3]` covers the actual hard visible subset. | Added waist strong4 `[0,1,2,3]` despite geometry-only score being below Gate 2 target. | Hard noise `0.05px`, seeds `45/46/47`: all-body valid `1.0`, wrong/confusion `0/0`. | Runtime whitelist must include sim-observed safe subsets, not only top geometry subset. | Measure hard high-noise boundary. |
| 21 | Candidate high-noise hard boundary should improve or preserve current seed. | Ran hard noise `0.10/0.15px`, seeds `45/46/47`. | Noise `0.10px`: all clean. Noise `0.15px`: valid `>=0.996`, wrong `0`, marker confusion `0/1/2`. Current seed had no confusion but seed47 valid fell to `0.875` with much worse timing. | Candidate improves robustness but not stretch confusion target. | Try marker-assignment margin override. |
| 22 | Raising marker assignment margin to `0.35px` will remove high-noise swaps. | Ran candidate with `object_gating_ambiguous_marker_assignment_min_margin_px=0.35`. | Confusion remained at noise `0.15px`. | Not enough. | Try `0.50px`. |
| 23 | A stronger `0.50px` assignment margin will reject the remaining swaps. | Ran candidate hard noise `0.15px`, seeds `45/46/47`, margin `0.50px`. | wrong/confusion `0/0`, min valid `>=0.996`, trimmed p95 about `4.9/1.5ms`. | Candidate + margin override reaches hard boundary target. | Check green side effects. |
| 24 | Candidate + margin `0.50px` should preserve relaxed and hard green. | Ran relaxed noise `0.05px` and hard noise `0.05/0.10px`, seeds `45/46/47`. | All runs valid `1.0`, wrong/confusion `0/0`; trimmed p95 stayed near budget. | Candidate runtime package is practical. | Check whether margin can be global default. |
| 25 | Margin `0.50px` may be safe as a global default. | Ran current seed with margin `0.50px` across relaxed/hard matrix. | Current seed still had seed46 confusion at hard noise `0.15px` and seed47 valid/perf collapse. | Do not change global default from this evidence. Use margin `0.50px` as candidate-specific runtime override. | Next: CAD fixture check and longer sustained run for `candidate_00534`. |
| 26 | `candidate_00534` + waist expansion + margin `0.50px` can sustain high-noise 480-frame operation. | Ran hard seed45/noise `0.15px`, 480 frames. | wrong/confusion `0/0`, valid `>=0.966`, but chest had rotation delta max `57.5deg` and position delta max `28.8mm`; scenario failed. | Sustained high-noise failure is not identity ownership, but chest pose continuity during occlusion. | Add frame-level delta event logging. |
| 27 | The sustained failure may be current-seed behavior, not candidate-specific. | Ran current seed with the same 480-frame hard/noise `0.15px` and margin `0.50px`. | Current seed had marker confusion `1`, worse timing, and head/waist rotation jumps; candidate still wins on identity and timing. | Keep `candidate_00534` as the practical package, but keep sustained gate open. | Diagnose candidate chest jump. |
| 28 | Max-only summary is too coarse to drive the next PDCA step. | Added `position_delta_top_events` and `rotation_delta_top_events` to sim summaries. | Candidate chest jumps clustered at frames `395/429/458`; wrong/confusion stayed `0/0`. | Failure is a pose-continuity problem after full/near-full occlusion. | Try narrowing chest policy. |
| 29 | Requiring chest 4 markers in continue should remove risky 3-marker recovery. | Tried a chest policy with `continue_min_markers=4` and no strong 3-subsets. | chest valid fell to `0.958`, jumps remained. | 3-marker continue is not the root cause. | Check whether chest whitelist is too narrow. |
| 30 | Adding chest strong4 `[1,2,3,4]` should reduce prediction holds. | Added only that next-best 4-point subset. | Sustained result was effectively unchanged. | Whitelist coverage is not the active cause for this seed. | Inspect unseen prediction behavior. |
| 31 | Fully unseen holds should freeze instead of integrating stale angular velocity. | Tested a local freeze variant for fully unseen prediction holds. | chest position max improved to `12.6mm`, rotation max improved to `11.4deg`, but still missed the strict `5deg` sustained gate and timing p95 worsened. | Freeze reduces catastrophic jumps but is not production-ready. | Try bounded coast, then reject if identity side effects appear. |
| 32 | Bounded one-frame coast can reduce freeze snap without over-rotation. | Tested a local bounded coast variant. | noise `0.15px` still failed rotation max (`13.7deg`), though trimmed rigid p95 returned to `1.49ms`. | Bounded coast is not enough. | Check side effects at noise `0.10px`. |
| 33 | Bounded coast should preserve the previously green noise `0.10px` sustained/short behavior. | Ran noise `0.10px` with the bounded coast variant. | chest marker confusion appeared (`11` events). | Reject bounded coast and revert it. | Keep original prediction behavior; retain delta-event logging for the next root fix. |
| 34 | Reverting coast should preserve the established 240-frame green boundary. | Ran 240-frame hard seed45/noise `0.10px`, margin `0.50px`. | all-body valid `1.0`, wrong/confusion `0/0`, trimmed p95 `4.94/1.49ms`. | Practical short-run package remains good; sustained high-noise chest continuity is the next blocker. | Next: design a pose-continuity fix that smooths re-entry without moving marker assignment projections. |
| 35 | The next 10-cycle run should start by re-reading the current sustained failure on the latest tree. | Re-read Cycle 28/34 summaries and inspected current rigid/pipeline insertion points. | Latest tree includes passive-stabilization counters and a `prediction_hold_2d_constrained` path; Cycle 28's old baseline is no longer the active current-tree baseline. | Measure the current tree before adding new logic. | Try output-only smoothing, then compare to no-smoothing current baseline. |
| 36 | Output-only re-entry smoothing can reduce chest jump without changing assignment. | Added a local return-pose limiter after prediction hold (`12mm`, `4.5deg`) and ran 480-frame seed45/noise `0.15px`. | Same identity failure as the current tree: wrong/confusion `1/4`; chest valid `0.954`; chest rotation max `50.6deg`; p95 pair/rigid `6.72/2.12ms`. | Reject the smoothing experiment; it does not address the active current-tree failure. | Disable smoothing and establish current-tree baseline. |
| 37 | The current tree without output smoothing may already have the same identity failure. | Disabled the local smoothing and reran the same 480-frame condition. | wrong/confusion `1/4`, chest valid `0.954`, chest rotation max `50.6deg`, p95 pair/rigid `6.44/1.78ms`. | The active blocker is now identity/body-conflict rank resolution, not output smoothing. | Test whether stronger marker margin helps. |
| 38 | Raising candidate marker assignment margin to `0.75px` will reject the remaining close marker swaps. | Reran 480-frame seed45/noise `0.15px` with margin `0.75px`. | No material change: wrong/confusion `1/4`, same failure frames. | Marker-vs-marker margin is not the controlling guard. | Test close-blob diameter overlap guard. |
| 39 | Raising close-blob overlap guard to `0.50` will reject pi-cam-04 near-blob ownership mistakes. | Reran with `object_gating_ambiguous_blob_diameter_overlap_ratio=0.50`. | No material change: wrong/confusion `1/4`. | The failure is not controlled by the existing close-blob ambiguity gate. | Try active-anchor physical-ID assist. |
| 40 | Active anchor markers can anchor body identity and reduce rank conflicts. | Reran with `active_anchor_markers=true`. | wrong/confusion stayed `1/4`, but chest valid improved to `0.969` and chest rotation max improved to `37.1deg`. | Active anchors help pose continuity, not the ownership-ledger identity event. | Test physical noise assumptions. |
| 41 | Diameter-scaled centroid noise is a more realistic high-noise boundary and may reduce small-blob swaps. | Reran with `centroid_noise_model=diameter_scaled`. | Worse: wrong/confusion `1/15`, chest rotation max `81.0deg`, p95 pair/rigid `7.46/2.50ms`. | Reject diameter-scaled noise for this sustained acceptance run. | Check whether lower constant noise restores 480-frame identity. |
| 42 | Lowering constant noise to `0.10px` should restore 480-frame identity if noise amplitude is the main cause. | Reran current baseline at noise `0.10px`. | Worse than noise `0.15px`: wrong/confusion `1/14`, chest rotation max `60.6deg`. | The failure is geometry/projection conflict, not simply centroid noise amplitude. | Test smaller marker diameter as a physical design lever. |
| 43 | Smaller markers reduce projected overlap and should reduce pi-cam-04 conflicts. | Reran with `marker_diameter_scale=0.70`. | Improved but not green: wrong/confusion `1/8`, chest valid `0.969`; persistent pi-cam-04 waist/left_foot wrong owner remains. | Marker diameter helps marker swaps but not the body-pair projection conflict. | Try an even smaller marker diameter to see if the effect saturates. |
| 44 | `0.50` marker diameter scale should further reduce projected overlap if diameter is the remaining lever. | Reran with `marker_diameter_scale=0.50`. | No further gain over `0.70`: wrong/confusion `1/8`; p95 timing worsened. | Diameter effect saturates; do not solve this by shrinking markers alone. | Next: modify design geometry or body-conflict rank logic for waist/left_foot pi-cam-04 separation. |

Current practical candidate package:

- Candidate source: `logs/design/rigid_body_v2/candidates_pdca_cycle7/rank_04_candidate_00534.json`
- Sim rigids with expanded waist whitelist: `logs/design/rigid_body_v2/sim_pdca_cycle20_candidate00534_policy_expand2/candidate_00534_waist_expand2_tracking_rigids.json`
- Required runtime override for this candidate: `object_gating_ambiguous_marker_assignment_min_margin_px = 0.50`

Current validation status:

| gate | status |
|---|---|
| Gate 2 geometry | pass with `candidate_00534`; waist whitelist expanded from sim evidence |
| Gate 3 lightweight projection | not the top projection candidate, but sim BOOT smoke passes |
| Relaxed sim green | pass, seeds `45/46/47`, noise `0.05px` |
| Hard sim green | pass, seeds `45/46/47`, noise `0.05px` |
| Hard boundary | pass in the earlier 240-frame matrix with margin override `0.50px`; must be revalidated on the current passive-stabilization tree |
| Sustained 480-frame run | blocked on the current tree: seed45/noise `0.15px` has persistent pi-cam-04 waist/left_foot wrong owner plus chest re-entry jumps |
| CAD manufacturability | pending |

## Design Objective

Find five rigid-body marker coordinate sets for:

- `head`
- `waist`
- `chest`
- `left_foot`
- `right_foot`

Each body should fit within the physical fixture constraints while maximizing:

- 3D identity separation between bodies.
- Safe whitelisted `4-of-5` BOOT / REACQUIRE subsets.
- Safe whitelisted `3-of-5` CONTINUE confirmation subsets.
- 2D marker separation after projection into the current 4-camera rig.
- Assignment margin between competing markers and blobs.
- Low object-gating ambiguity count in body-mounted sim.
- Stable 118fps live-route timing.

## Non-Goals

- Do not optimize for arbitrary `3-of-5` or `4-of-5` acceptance.
- Do not freeze a coordinate set from geometry-only metrics.
- Do not make a design that requires weaker runtime ownership or reprojection guards.
- Do not chase one clean seed if nearby seeds or noise levels still fail.
- Do not treat performance wins as valid if they increase wrong ownership or marker confusion.

## Constraints

Physical constraints:

| item | requirement |
|---|---:|
| marker count | `5` per rigid body |
| body count | `5` |
| coordinate region | hemisphere |
| max radius | `65mm` |
| z floor | `z >= 0` |
| target marker spacing | minimum `35mm`, stretch `40mm+` |
| manufacturable status | final candidate must be checked by CAD fixture generation |

Runtime constraints:

| mode | accepted evidence |
|---|---|
| BOOT | whitelisted `4-of-5` only |
| REACQUIRE | whitelisted `4-of-5` only, plus prediction agreement for recent loss |
| CONTINUE | whitelisted `4-of-5`, or whitelisted `3-of-5` only as prediction confirmation |
| weak subset | hold prediction, decay confidence, do not commit independent pose |

Performance constraints:

| metric | minimum target | stretch target |
|---|---:|---:|
| pipeline pair p95 | `<= 6.0ms` | `<= 5.2ms` |
| rigid p95 | `<= 1.5ms` | `<= 1.3ms` |
| sustained pair budget overrun | `0` sustained runs | `0` total |
| wrong ownership | `0` | `0` |
| marker source confusion | `0` on green matrix | `0` on hard matrix |
| min valid frame ratio | `>= 0.95` | `>= 0.995` |

## End-To-End Pipeline

The V2 pipeline has four gates. A candidate must pass each gate before moving to the next one.

```text
candidate generation
  -> geometry screening
  -> projection screening
  -> sim validation
  -> CAD / runtime freeze
```

### Gate 1 - Candidate Generation

Generate candidates with a constrained evolutionary search:

1. Start from the current 5-marker exploratory seed.
2. Generate mutations by moving one or more markers within the hemisphere.
3. Reject candidates that violate physical constraints.
4. Keep a diverse population rather than only the current best score.
5. Preserve body-to-body diversity so two bodies do not converge to similar shapes.

Generation strategies to include:

- Local mutation around the current seed.
- Wider-spacing biased mutation.
- Asymmetry biased mutation.
- Projection-margin biased mutation after Gate 2 exists.
- Body-specific mutation when one body is repeatedly the worst case.

Candidate records should be stored as JSON so every later sim result can point back to exact coordinates and whitelist metadata.

Suggested output location:

```text
logs/design/rigid_body_v2/candidates/
```

### Gate 2 - Geometry Screening

Run fast coordinate-only evaluation before touching the simulator.

Required geometry metrics:

| metric | minimum target | stretch target |
|---|---:|---:|
| full `5-vs-5` cross margin | `20mm` | `25mm+` |
| whitelisted `4-of-5` cross margin | `14mm` | `18mm+` |
| whitelisted `3-of-5` profile margin | `8mm` | `10mm+` |
| minimum marker spacing | `35mm` | `40mm+` |
| weak subset accepted in BOOT / REACQUIRE | `0` | `0` |

Required explanations for rejected or weak subsets:

- nearest cross-body neighbor.
- low 4-point volume.
- low 3-point triangle area.
- repeated edge lengths.
- near-isosceles or near-symmetric profile.
- low margin against another body or subset.

Implementation target:

- Extend `src/host/pattern_evaluator.py`.
- Add JSON output with per-body `strong_4_subsets`, `strong_3_subsets`, and rejection reasons.
- Add a design-search command or script under `tools/` that can run this evaluator repeatedly.

Gate 2 pass condition:

- At least one strong `4-of-5` subset per body reaches target.
- At least one strong `3-of-5` subset per body reaches target.
- No non-whitelisted weak subset is required for BOOT or REACQUIRE coverage.
- Candidate beats the current exploratory seed on the worst whitelisted `4-of-5` or `3-of-5` score.

### Gate 3 - Projection Screening

Geometry metrics are necessary but not sufficient. Gate 3 projects each candidate into the current 4-camera rig and measures whether markers become ambiguous in image space.

Required projection metrics:

| metric | target |
|---|---:|
| per-camera marker-pair 2D separation p05 | higher than current seed |
| worst projected marker-pair separation | no new close-pair below current seed unless sim proves safe |
| whitelisted subset projected area | higher than current seed on worst camera |
| marker-vs-marker assignment margin | above current `0.29px` guard boundary where possible |
| close-blob diameter overlap risk | lower than current seed on hard frames |
| cross-body projected profile similarity | lower than current seed |

Projection screening should use:

- `cube_top_2_4m_aim_center` camera rig.
- Same coordinate space assumptions as `tools/sim`.
- Occlusion masks for all one-marker and two-marker missing cases.
- Body poses sampled from `five_rigid_body_occlusion_v1`.

Important current sim-derived failure references:

- `head` marker `3/4` can become a close-marker swap under seed `45` / noise `0.10px`.
- `chest` marker `0/4` can become low marker-assignment margin under seed `46` / noise `0.15px`.
- Close-blob ambiguity is now guarded by fixed `0.60px` plus diameter overlap ratio `0.30`.
- Marker assignment ambiguity is now guarded by margin `0.29px`.

Gate 3 pass condition:

- Candidate reduces the worst known projected ambiguity compared with the current seed.
- Candidate does not create a new body whose projected subset is weaker than the current worst body.
- Candidate has at least one strong `4-of-5` and one strong `3-of-5` subset that remain strong under projection.

### Gate 4 - Sim Validation

Only a small number of candidates should reach full sim validation.

Validation matrix:

| scenario | frames | seeds | noise |
|---|---:|---|---|
| `five_rigid_body_occlusion_relaxed_v1` | `240` | `45,46,47` | `0.05px` |
| `five_rigid_body_occlusion_v1` green | `240` | `45,46,47` | `0.05px` |
| `five_rigid_body_occlusion_v1` hard | `240` | `45,46,47` | `0.10px, 0.15px` |
| best final candidate sustained | `480` | best and worst seed | selected boundary noise |

Core sim metrics:

- `wrong_ownership_count`
- `marker_source_confusion_count`
- `valid_frame_ratio`
- `ownership_confusion_summary`
- `ambiguous_assignment_count`
- `marker_margin_assignment_count`
- object-gating `assigned_marker_views`
- pose jump count
- max position innovation
- max rotation innovation
- pipeline pair p95
- rigid p95
- geometry p95
- sustained over-budget count

Gate 4 pass condition:

- Green matrix has `wrong_ownership_count = 0`.
- Green matrix has `marker_source_confusion_count = 0`.
- Hard matrix improves or preserves current best failure count.
- No seed has min valid frame ratio below `0.95`.
- Pair p95 stays within `6.0ms`.
- Rigid p95 does not regress meaningfully from the current object-gating optimized path.

## PDCA Rules

The design search may generate many candidates internally, but adoption must still follow sequential PDCA.

For each adoption cycle:

1. Measure the current baseline candidate first.
2. State the hypothesis for the next candidate or scoring change.
3. Make exactly one design-search, scoring, or runtime-evaluation change.
4. Measure the result.
5. Read the failure or improvement.
6. Decide whether to keep, adjust, or reject.
7. Choose the next action from that result.

Do not predeclare a large AB batch as PDCA. A batch can be used inside candidate generation, but the logged PDCA decision must be sequential.

Suggested PDCA log location:

```text
logs/design/rigid_body_v2/pdca_YYYYMMDD_*/
```

Suggested design log section:

```text
docs/10_in_progress/rigid_body_design_v2.md
```

## Scoring Model

Use a ranked score for search, but use hard gates for adoption.

Suggested search score:

```text
score =
  + full_5_cross_margin
  + whitelisted_4_cross_margin * 1.4
  + whitelisted_3_profile_margin * 1.2
  + projected_marker_margin * 1.5
  + projected_subset_area * 0.5
  + min_marker_spacing * 0.4
  - close_blob_risk * 2.0
  - marker_assignment_ambiguity_risk * 2.0
  - weak_subset_required_penalty
  - manufacturability_penalty
```

This score is only for ranking candidates. Final adoption uses Gate 4 pass conditions.

## Candidate Metadata Contract

Each candidate should carry enough metadata to be replayed and frozen later.

```json
{
  "candidate_id": "rigid_v2_YYYYMMDD_NNN",
  "source": "mutation_of_design_5marker_seed",
  "constraints": {
    "max_radius_mm": 65,
    "z_min_mm": 0,
    "marker_count": 5
  },
  "rigids": [
    {
      "name": "head",
      "marker_positions_mm": [[0, 0, 0]],
      "marker_diameter_m": 0.014,
      "tracking_policy": {
        "boot_min_markers": 4,
        "reacquire_min_markers": 4,
        "continue_min_markers": 3,
        "strong_4_subsets": [[0, 1, 2, 4]],
        "strong_3_subsets": [[1, 2, 4]]
      }
    }
  ],
  "geometry_report": {},
  "projection_report": {},
  "sim_report": {}
}
```

## Implementation Plan

### Phase 1 - Evaluator Report

Deliverables:

- Extend `src/host/pattern_evaluator.py`.
- Emit geometry JSON reports.
- Include subset whitelist recommendations and weak-subset explanations.
- Add tests for subset metrics and whitelist stability.

Done when:

- Current exploratory seed reproduces the known weak all-subset and improved whitelist numbers.
- Reports identify nearest weak subset pairs.

### Phase 2 - Candidate Search

Deliverables:

- Add constrained candidate generation under `tools/`.
- Store candidates and reports under `logs/design/rigid_body_v2/`.
- Generate an initial population from the current seed.

Done when:

- At least `1000` candidates can be screened by geometry without running full sim.
- Top candidates are reproducible by seed.
- Candidate reports include exact coordinate sets and policy metadata.

### Phase 3 - Projection Report

Deliverables:

- Add projection scoring using the current sim camera rig.
- Report per-camera marker-pair separation and assignment-margin risk.
- Report worst body, camera, frame, and marker pair.

Done when:

- Current known `head 3/4` and `chest 0/4` risk can be explained by projection metrics.
- Projection score can reject candidates that geometry-only metrics would falsely accept.

### Phase 4 - Sim Candidate Injection

Deliverables:

- Add a way for `tools/sim` to run a candidate JSON rigid definition.
- Preserve `tracking_policy` metadata through sim setup.
- Save summaries by `candidate_id`.

Done when:

- Current exploratory seed and one generated candidate can run the same 240-frame matrix.
- Sim summary includes candidate ID and design metrics references.

### Phase 5 - Sequential Design PDCA

Deliverables:

- Run 10 sequential PDCA cycles.
- Each cycle changes one scoring or generation decision.
- Log hypothesis, result, decision, and next action.

Initial 10-cycle focus:

| cycle target | purpose |
|---|---|
| baseline current seed | establish current design result under the new report |
| geometry-weight change | see whether stronger whitelist score predicts sim improvement |
| projection-weight change | see whether 2D margin predicts marker confusion reduction |
| body-specific mutation | fix the worst body from the previous result |
| spacing-biased mutation | test if wider spacing lowers close-blob risk |
| asymmetry-biased mutation | test if less symmetric profiles improve cross-body margin |
| whitelist coverage change | test one vs two strong subsets per body |
| hard-noise check | verify high-noise boundary |
| sustained run | check 480-frame behavior |
| freeze candidate candidate | decide whether a manufacturable candidate exists |

### Phase 6 - CAD Freeze Check

Deliverables:

- Generate fixture CAD for the top candidate.
- Check stem clearance, base holes, marker accessibility, and print feasibility.
- Feed any CAD-driven coordinate constraints back into Gate 1.

Done when:

- CAD constraints do not reduce design metrics below Gate 2 / Gate 3 targets.
- Candidate can be exported with final marker coordinates and whitelist metadata.

## Final Adoption Criteria

A rigid-body design can be frozen only when all of the following are true:

- Geometry report passes Gate 2.
- Projection report passes Gate 3.
- Sim green matrix is clean.
- Hard matrix is better than or equal to current design on marker confusion and wrong ownership.
- 480-frame sustained run does not show new identity drift.
- Pair p95 remains `<= 6.0ms`.
- Rigid p95 remains near or below current optimized path.
- CAD fixture is manufacturable without moving markers outside accepted margins.
- Runtime metadata includes `strong_4_subsets` and `strong_3_subsets`.
- The candidate can be replayed from stored JSON and logs.

## First Next Step

Start with Phase 1, not with a long coordinate search.

The highest-leverage first task is to make the evaluator report the exact subset and projection weaknesses that the sim already exposed. Once the current seed's known `head 3/4` and `chest 0/4` risks are visible in the report, candidate search becomes much less random and full sim runs can be reserved for serious finalists.

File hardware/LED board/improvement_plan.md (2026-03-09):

# LED基板改良計画

## 概要
本ドキュメントは、GPIO駆動PWM制御を主軸としたLED基板の改良計画を示します。電流管理と安全性に重点を置いています。

---

## 1. 基本構成

### 推奨回路構成

```
Raspberry Pi GPIO (PWM)
          │
        100Ω
          │
        Gate
        MOSFET (IRLML6344)
          │
          ├─ 10kΩ → GND (pull-down)
          │
        Source → GND
          │
        Drain
          │
        LED列
          │
        電流制限抵抗
          │
        12V
```

### 主要部品と役割

| 部品 | 役割 |
|---|---|
| 100Ω | GPIO保護 / スイッチング安定 |
| 10kΩ | 起動時OFF保証 |
| 抵抗 | LED電流制限（必須） |

---

## 2. PWM設定

### Raspberry Pi 5設定

| パラメータ | 値 |
|---|----|
| 周波数 | 500 Hz |
| デューティ | 10% |

### タイミング例

- **ON時間**: 2 ms
- **OFF時間**: 18 ms

---

## 3. LED電流設計

### LED仕様 (OSI5LAS1C1A)

| パラメータ | 値 |
|---|----|
| IF (DC) | 100 mA |
| IF (パルス) | 1 A |
| 最大デューティ | ≤ 10% |

### 安全設計パラメータ

- パルス電流: 300–500 mA
- デューティ: 10%

---

## 4. 抵抗値推奨値

### LED構成: 6個直列

- **順電圧 (Vf)**: 1.6V × 6 = 9.6V
- **電源電圧**: 12V
- **余剰電圧**: 12V − 9.6V = 2.4V

### 電流計算

| 抵抗値 | 電流 |
|---|---|
| 24Ω | 100 mA (現状) |
| 6Ω | ≈400 mA |
| 4Ω | ≈600 mA |

### 推奨値

- **5–6Ω**: パルス電流と安全性の最適バランス

---

## 5. 電力消費解析

### 現状構成

- パルス: 400 mA (デューティ 10%)
- 平均電流: 40 mA
- 4列: 160 mA (平均)
- **電力**: 12V × 0.16A ≈ 2W

### 比較

- **現状**: ≈4W
- **改良後**: ≈2W
- **削減**: 50%

---

## 6. 重要な安全注意事項

### 抵抗の必須性

LEDは指数特性を示す。抵抗なしでは:
- 少し電圧上昇 → 電流暴走 → LED破壊

**結論**: 電流制限抵抗は、パルス駆動でも絶対に必要。

---

## 7. Python PWM例

```python
import RPi.GPIO as GPIO

PIN = 18

GPIO.setmode(GPIO.BCM)
GPIO.setup(PIN, GPIO.OUT)

pwm = GPIO.PWM(PIN, 500)
pwm.start(10)
```

---

## 8. 高度な構成（推奨）

### カメラ同期

- **LED ON**: カメラ露光
- **LED OFF**: 露光間

### 利点

- IR背景カット
- ノイズ低減
- 電力削減

---

## 9. 既存基板の改良案

### ハードウェア変更

- 変更: 12Ω + 12Ω → 3Ω + 3Ω
- 追加: 100Ω → Gate
- 追加: 10kΩ pull-down → Gate

### ソフト設定

- PWM周波数: 500 Hz
- デューティ: 10%

### 期待される改善

- 光量: 3–4倍増加
- 電力: 50%削減

---

## 結論

本改良計画は、GPIO駆動LED PWM制御の安全かつ効率的な構成を提供します。主な特長:
- 必須の電流制限抵抗
- ゲート保護とプルダウン抵抗
- 最適PWM設定で50%電力削減、光量3–4倍増加

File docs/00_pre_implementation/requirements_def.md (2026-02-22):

# requirements_def

## 1. 目的

Raspberry Pi 5 + Raspberry Pi Camera 3 Noir Wide 複数台で、
頭・胸・腰・右足先・左足先の5剛体を 60fps 目標で追跡し、SteamVR にトラッカーとして入力する。

## 2. スコープ

### In Scope

- RasPi 側: Blob 検出と UDP JSON 送信
- Host 側: 受信、ペアリング、3D復元、剛体推定、SteamVR出力
- Host→RasPi: start/stop、カメラ設定、マスク、LED制御
- 較正(内部/外部)、同期、運用更新基盤

### Out of Scope (初期)

- 外部ハードトリガ前提の同期
- 大規模クラスタ(9台以上)の本番運用

## 3. 機能要件

### FR-1 RasPi観測

- 各 RasPi はフレーム毎に `camera_id`, `timestamp`, `frame_index`, `blobs[]` を送信する
- `timestamp` は `int64` の Unix epoch(us) を採用する
- `frame_index` は `uint32` の単調増加(カメラごと)を採用する
- `blobs` 要素は `{x, y, area}` を持つ

### FR-2 Host受信/ペアリング

- Host は UDP 受信し、camera_id 毎に時系列を管理
- `timestamp` を主、`frame_index` を副として multi-camera フレームをペアリング

### FR-3 幾何復元

- Host は較正値を用いて対応付け・三角測量を行い 3D 点群を生成
- 再投影誤差を計算し品質指標を出す

### FR-4 剛体推定

- 点群をクラスタリングして剛体候補を分離
- 各剛体について姿勢(quaternion)を推定

### FR-5 SteamVR出力

- 5トラッカー(head/chest/waist/left_foot/right_foot)を更新出力

### FR-6 Host→RasPi制御

- start/stop
- カメラ設定(露光、ゲイン、fps 等)
- マスク作成指示
- GPIO LED 制御

## 4. 非機能要件

### NFR-1 性能

- 目標更新レート: 60fps
- 同期目標: 2-5ms

### NFR-2 頑健性

- 一部カメラ欠損時でも推定継続(グレースフルデグレード)
- UDP パケット欠落時でも復帰可能

### NFR-3 保守性

- 2-8台の RasPi を更新/運用できること
- 較正データと設定をバージョン管理できること

## 5. インタフェース要件

### IR-1 RasPi→Host (UDP/JSON)

- 受信口: `0.0.0.0:5000` (想定)
- 文字コード: UTF-8

### IR-2 Host→RasPi (TCP/JSON)

- 制御系は到達保証を重視
- message schema は `request_id`, `camera_id`, `cmd`, `params`, `ack`, `error_code` を必須とする

### IR-3 Host→SteamVR

- OpenVR Driver を第一候補
- tracker role は `head`, `chest`, `waist`, `left_foot`, `right_foot` を固定する
- serial 命名規則は `loutrack-{role}-{index}` を採用する

## 6. 受け入れ基準(初版)

1. 2台以上のカメラ観測から 3D 点群が再現される
2. 5トラッカーの pose が連続出力される
3. 同期誤差評価で目標帯域(2-5ms)に近づくことを確認できる
4. start/stop と露光制御が Host から反映される

## 7. 推奨決定(暫定採用)

- `frame_index` は送る(障害時フォールバック用)
- `timestamp` は `int64` Unix epoch(us)、フレーム確定時刻を採用
- Host→Pi は TCP JSON-RPC 風 schema を採用
- SteamVR は OpenVR Driver、role/serial を固定
- 同期失敗時は「補間継続 → 連続失敗で予測のみ → 自動再同期」の2段階 degrade
- Charuco 較正成果物は `calibration_intrinsics_v1.json` を採用
- 外部較正は wand 運用手順(>=20ポーズ、誤差基準あり)を標準化
- DBSCAN 初期値は `eps=marker_diameter*0.8`, `min_samples=3`
- 姿勢推定は Kabsch 主体、PnP/3点PnP/Kalman を段階フォールバック
- 配布は SCP/SSH で開始し、台数>4 または更新頻度>週2で Ansible へ移行

## 8. なお未確定の要件

- 再投影誤差やフォールバック発火の閾値(実測で確定)
- 環境別(DBSCAN/同期窓)のチューニングテーブル
- OpenVR driver 実装時の予測/補間責務の最終配分

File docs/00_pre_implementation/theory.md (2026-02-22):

# theory

## 1. システム理論の全体像

本プロジェクトは outside-in 型の光学モーションキャプチャです。

- 各 RasPi が画像から反射マーカの 2D 観測値を抽出
- Host が multi-view 幾何で 3D 点群を推定
- 時系列フィルタと剛体推定で pose(位置+姿勢)を算出
- SteamVR 向けに tracker pose を出力

要点は「同期」「対応付け」「較正」「剛体同定」の4本柱です。

## 2. 観測モデル

各カメラで観測される点は画像座標系で表され、以下を送信します。

- `camera_id`
- `timestamp`
- `frame_index`
- `blobs`: `{x, y, area}` の配列

推奨仕様:
- `timestamp`: `int64` Unix epoch(us)
- `frame_index`: `uint32` 単調増加(カメラごと)

画像そのものは送らず、Host 側で幾何計算します。

## 3. 幾何パイプライン

### 3.1 対応付け

候補点の対応付けはエピポーラ幾何と再投影誤差を併用します。

1. 仮の対応を作る
2. 三角測量で 3D 仮説を得る
3. 各視点へ再投影して誤差を評価
4. 誤差最小の組み合わせを採用

### 3.2 三角測量

- DLT を基礎とし、必要に応じて非線形最適化で補正
- 較正済み内部/外部パラメータを使用

### 3.3 Rectification

Rectification は Host 側で実施し、RasPi は生画像座標を送ります。

## 4. 時間同期理論

同期は以下の3層で吸収します。

1. クロック同期(PTP等)
2. Host 側の timestamp ペアリング
3. フィルタによるジッタ/欠損吸収

目標は実運用で 2-5 ms の撮影タイミング差です。

推奨 degrade 戦略:
- 許容窓外フレームは短時間補間で継続
- 連続失敗時は予測のみへ遷移
- 同期復帰後は自動再同期

## 5. 状態推定と剛体推定

### 5.1 点トラック

- 観測点に対してトラック管理を行い、欠損時は予測で補完
- Kalman フィルタは姿勢推定前の安定化に使用

### 5.2 クラスタリング

- 第一候補は DBSCAN
- 反射ノイズや外れ値に強く、点数変動に比較的頑健

### 5.3 姿勢推定

- 主方式: Kabsch (3D-3D)
- フォールバック: PnP / 3点PnP / 予測継続

## 6. SteamVR 連携理論

Host 内部座標を SteamVR 座標に変換し、5トラッカーへ割り当てます。

- head
- chest
- waist
- left_foot
- right_foot

出力方式は OpenVR Driver を第一候補とします。

## 7. 未解決の理論課題

- ペアリング許容窓(環境別)の定量化
- 姿勢推定フォールバック閾値の同定
- 5剛体の同定評価関数(重み設計)の最適化
- DBSCAN パラメータの環境適応則

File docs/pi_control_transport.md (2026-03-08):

# Pi Control Transport Spec (MVP)

このドキュメントは、Host(PC) -> Raspberry Pi の制御(TCP) と、Pi -> Host のフレーム送信(UDP) の通信規約を単一の仕様ソースとして固定する。

実装は後続タスクで行う。ここでは「wire format / ports / error codes / MVP cmd の扱い」を明文化する。

## 1. 用語

- Host: 受信・三角測量・可視化を行うPC側
- Pi: Raspberry Pi + Camera 側
- Control: Host -> Pi の制御コマンド
- Frame: Pi -> Host のフレーム(検出blob)メッセージ

## 2. TCP Control (NDJSON)

### 2.1 接続

- Pi は TCP server として待ち受ける
- bind: `0.0.0.0`
- port: `8554`

### 2.2 フレーミング

- フォーマット: `NDJSON`
- 1行 = 1 JSON object
- 行終端: `\n`
- max line: 65536 bytes
- read timeout: 2s/line timeout

注: 既存の JSON Lines パターンは `src/host/logger.py` / `src/host/replay.py` の「1行=1JSON」(jsonl) と同じ思想。

### 2.3 メッセージスキーマ

- `schema/control.json` 準拠
- request と response は同じ TCP stream 上で NDJSON として流れる

Request (Host -> Pi):

```json
{"request_id":"req-001","camera_id":"pi-cam-01","cmd":"set_exposure","params":{"value":10000}}
```

Response (Pi -> Host):

```json
{"request_id":"req-001","camera_id":"pi-cam-01","ack":true}
```

`ack:false` の場合は `error_code` と `error_message` を返す:

```json
{"request_id":"req-002","camera_id":"pi-cam-01","ack":false,"error_code":3,"error_message":"unknown_cmd: mask_start"}
```

## 3. UDP Frame Transport

### 3.1 送信単位

- 1 datagram = 1 JSON object
- `schema/messages.json` 準拠

### 3.2 送信先

- default dest: `255.255.255.255:5000`

備考:
- Host 側の既定受信は `src/host/receiver.py` の UDP port `5000`。

## 4. Error Codes

Control response の `error_code` は以下を固定する (1..7):

- 1: `invalid_json`
- 2: `invalid_request`
- 3: `unknown_cmd`
- 4: `not_running`
- 5: `already_running`
- 6: `backend_unavailable`
- 7: `internal_error`

`ack:true` のときは `error_code` は省略または 0 を許容する。

## 5. Command Support Policy (MVP)

### 5.1 MVP supported commands

この MVP フェーズで「機能としてサポートする」コマンドを以下に固定する:

- `ping`
- `start`
- `stop`
- `set_exposure`
- `set_gain`
- `set_fps`
- `set_focus`
- `set_threshold`
- `set_blob_diameter`
- `set_circularity_min`

### 5.2 Schema-valid but not supported (MVP)

`schema/control.json` 的に valid でも、MVP で未サポートのコマンドは以下の挙動を必須とする:

- response: `ack:false`
- `error_code=3` (unknown_cmd)

例: `mask_start` は schema 上 enum に含まれるが、MVP では未サポートのため以下を返す。

```json
{"request_id":"req-003","camera_id":"pi-cam-01","ack":false,"error_code":3,"error_message":"unknown_cmd: mask_start"}
```

注記: Phase 2 の wand 外部較正実装では `mask_start` / `mask_stop` を実装対象とする。
`mask_start` は `frames` に加えて `seconds` 指定も許容し、その時点の FPS 設定から初期化フレーム数を計算する。
詳細は `docs/wand_extrinsics_plan.md` を参照。

## 6. 実装メモ (非規範)

- Host は各 Pi に TCP 接続し、Control request を NDJSON で送る。応答も同一接続で受け取る。
- Frame (UDP) はブロードキャストが基本だが、運用によりユニキャストに切り替えても schema/messages.json 互換である限り wire format は同じ。

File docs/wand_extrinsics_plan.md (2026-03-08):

# wand_extrinsics_plan

## 1. 目的

外部較正を Charuco ペア方式ではなく、B5 サイズ L 字 wand（3端点、14mm blob）を使った運用に統一する。
Host 主導で Pi 群を同期制御し、時刻整合された観測ログから extrinsics を推定する。

## 1.1 進捗状況（2026-03-08）

- 完了:
  - Pi 側 `mask_start` / `mask_stop` 実装
  - Pi 側 `start(mode=wand_capture)` 実装
  - Host 側 `mask_start` / `mask_stop` API・CLI 実装
  - Host 側 `src/host/wand_session.py` 最小オーケストレーション実装
  - `wand_session` の session metadata 永続化（`logs/wand_sessions/<session_id>.json`）
  - 映像なし Web GUI（`src/host/wand_gui.py`）
  - `src/camera-calibration/calibrate_extrinsics.py` の wand 対応最小実装
  - `schema/calibration_extrinsics_v1.json` 追加
  - `src/host/geo.py` への extrinsics ロード統合
  - `WAND_POINTS_MM` 固定: `[(0,0,0), (168,0,0), (0,243,0)]`
  - E2E/ユニットテスト追加（`tests/test_pi_control_e2e.py`, `tests/test_wand_session.py`, `tests/test_wand_extrinsics.py`, `tests/test_wand_gui.py`）
- 未完了:
  - GUI の本格運用機能（再送ボタン、履歴フィルタ、セッション一覧）
  - 3台以上同時最適化（現状は参照カメラ基準のペア推定を順次実行）
  - quality gate の運用閾値確定（docs 反映）
- 進捗率（目安）: Phase 2 wand/extrinsics 作業の約 85-90%

## 2. 方針（結論）

- **Host を絡める**: 複数 Pi の開始時刻・設定配布・収録管理を一元化できるため。
- **Pi は lightweight**: 受信した制御に従い、観測送信と最小前処理のみ担当。
- **外部較正の正本は wand**: `docs/requirements_def.md` の推奨決定と整合。
- **収録モードを分離**: 通常トラッキングと wand 較正収録を mode で分ける。
- **Pi 発見は passive-first**: `UDPReceiver` の受動発見 + `hosts.ini` 補完を標準とし、active scan は任意機能とする。

## 3. 前提パラメータ（固定値）

- wand 名称: `wand_l_b5_v1`
- マーカー数: 3
- マーカー直径: 14mm
- 3D 座標定義（mm）: `WAND_POINTS_MM = [(0,0,0), (168,0,0), (0,243,0)]`
- 収録最小ポーズ数: 20
- 推奨収録時間: 60 秒
- mask 初期化フレーム数: 30
- ペアリング許容窓（初期）: 5000us

注: `WAND_POINTS_MM` は center-to-center 実測基準（0.1mm 以下精度）で固定済み。

## 4. 想定ワークフロー

1. Host が全 Pi に `set_exposure` / `set_gain` / `set_fps` を配布
2. Host が `mask_start` を送信し、Pi が 30 フレームで背景明点マスクを自動生成
3. Host が `start`（`mode=wand_capture`）を送信し wand 収録を開始
4. wand を空間全体で 20+ ポーズ（推奨 60 秒）動かして観測取得
5. Host が `stop` を送信して収録終了
6. Host で extrinsics solver を実行し `calibration_extrinsics_v1.json` を出力
7. Host 幾何パイプラインに intrinsics + extrinsics を読み込み検証

## 5. 実装タスク

### 5.1 Pi 側（`src/pi/capture.py`）

- `mask_start` 実装
  - 開始直後 30 フレームを取得
  - 各画素で閾値超過回数を集計し、静的マスクを生成
  - 本撮影ではマスク領域を除外して blob 検出
- `mask_stop` 実装（マスク解除/再初期化）
- `start` 時の mode 拡張（`capture`, `wand_capture`）
- 応答 `result` に mode / mask 状態を返せるようにする

### 5.2 Host 側制御

- 既存 `src/host/control.py` を使い、複数 Pi へ一括制御するオーケストレータを追加
- 映像なし GUI（スライダー中心）を追加し、複数 Pi の設定を同期操作できるようにする
- 収録セッション ID、開始/終了時刻、適用パラメータを記録
- コマンド順序を固定
  - `ping` -> `set_exposure`/`set_gain`/`set_fps` -> `mask_start` -> `start(mode=wand_capture)` -> `stop`

GUI の最小要件:

- スライダー: `exposure_us`, `gain`, `fps`, `focus`（全 Pi 同期適用、focus 既定 `5.215`）
- ボタン: `ping`, `mask_start`, `start`, `stop`
- 一覧: `camera_id`, `ip`, `last_ack`, `last_error`, `is_running`
- 同期モード: 1 本のスライダー操作を対象 Pi 全台へ配信
- 実装方式: Host ローカルの映像なし Web UI（単一ページ）

実装状況（2026-03-08）:

- ✅ `src/host/wand_session.py`: control 順序固定、mask retry、start失敗時 stop、session metadata 永続化
- ✅ `src/host/wand_gui.py`: 同期スライダー + `ping/mask_start/start/stop` + カメラ状態表示
- ✅ 受動発見 (`UDPReceiver`) と `hosts.ini` マージ

### 5.3 収録データ形式

- Pi 送信データは既存 `schema/messages.json` のまま利用
- Host 側で session 単位の保存を追加（JSONL 推奨）
  - 最低限: `session_id`, `camera_id`, `timestamp`, `frame_index`, `blobs`
  - 推奨追加: `mask_ratio`, `exposure`, `gain`, `fps`, `host_received_at`

### 5.4 外部較正ソルバ

- `src/camera-calibration/calibrate_extrinsics.py` を新規実装
- 入力
  - `calibration_intrinsics_v1_*.json`
  - wand 収録ログ（複数カメラ観測）
  - wand 3点の既知 3D 配置（mm）
- 出力
  - `calibration/calibration_extrinsics_v1.json`

実装状況（2026-03-08）:

- ✅ 実装済み（2台以上対応、参照カメラ固定、Essential + recoverPose + wand 辺長スケール復元）
- ✅ JSONL ログ（`FrameLogger` 形式）と素の frame NDJSON の両入力を受理

### 5.5 Host 幾何統合

- `src/host/geo.py` に extrinsics ロード機能を追加
- `load_calibration` で intrinsics + extrinsics を同時適用可能にする

実装状況（2026-03-08）:

- ✅ calibration ディレクトリ内の `calibration_extrinsics_v1*.json` 自動検出・適用

### 5.6 既存コード接続点（現状）

- 制御送信クライアント: `src/host/control.py`
  - 既存: `ping`, `start`, `stop`, `set_exposure`, `set_gain`, `set_fps`
- 受動発見: `src/host/receiver.py`
  - `UDPReceiver.get_camera_addresses()` で `camera_id -> (ip, port)` を保持
- Pi 制御サーバ/送信本体: `src/pi/capture.py`
  - 既存: `set_exposure`/`set_gain`/`set_fps` の適用
  - 未実装: `mask_start`/`mask_stop`/`wand_capture` mode

## 6. コードロジック詳細（実装仕様）

### 6.1 Pi 側状態遷移

- 状態
  - `IDLE`: 待機
  - `MASK_INIT`: `mask_start` 実行中
  - `READY`: mask 準備完了、未収録
  - `RUNNING`: 収録中
- 遷移
  - `IDLE --mask_start--> MASK_INIT --done--> READY`
  - `IDLE/READY --start--> RUNNING --stop--> READY`
  - `READY --mask_stop--> IDLE`

### 6.2 `mask_start` アルゴリズム

1. 30 フレーム取得
2. 各フレームを grayscale 化
3. `gray > threshold` を二値化
4. `hit_count[y, x] += 1` を累積
5. `hit_count >= ceil(hit_ratio * N)` を mask 候補化（例: `hit_ratio=0.7`）
6. 小領域除去（`min_area_px`）
7. 膨張（`dilate_px`）して安全マージン確保
8. `self._static_mask` として保持

実装メモ:

- データ型は `uint16` 累積で十分（30 フレーム想定）
- mask 生成結果は `result` に `mask_pixels` / `mask_ratio` を返す
- mask 比率が異常（例: 40%以上）なら warning を返す

### 6.3 blob 検出への mask 適用

- `detect_blobs` 前に `gray[mask==1] = 0` を適用
- 既存しきい値処理は維持
- 既存 area フィルタを維持

### 6.4 Host オーケストレータ（新規）

推奨ファイル: `src/host/wand_session.py`

主処理:

1. inventory から対象カメラ一覧読み込み
2. 全カメラ `ping` 成功を確認
3. 設定配布（露光/ゲイン/FPS）
4. 全カメラ `mask_start` 実行
5. 収録セッション作成（`session_id` 発行）
6. 全カメラ `start(mode=wand_capture)` を短時間に送信
7. 指定時間収録
8. 全カメラ `stop`
9. session メタデータ保存

探索ロジック:

1. `hosts.ini` の静的 inventory を読み込み
2. `UDPReceiver.get_camera_addresses()` の受動発見結果をマージ
3. camera_id 優先で重複解決（受動発見IPを優先）
4. 各候補へ `ping` して最終対象を確定

失敗時ポリシー:

- 1台でも `start` 失敗なら全台 `stop` を送ってセッション中止
- `mask_start` 失敗台は再試行1回、失敗継続なら除外して中止判断

### 6.5 Host GUI 同期スライダー（新規）

推奨ファイル: `src/host/wand_gui.py`

内部ロジック:

1. GUI state に `selected_cameras` と `sync_enabled` を保持
2. スライダー操作時にデバウンス（例: 200ms）
3. デバウンス後に対象全台へ並列送信
4. `ack` 集約結果を UI に反映

同期適用擬似コード:

```python
def apply_slider_sync(param: str, value: float | int) -> None:
    targets = get_selected_cameras()
    fn = {
        "exposure_us": control.set_exposure,
        "gain": control.set_gain,
        "fps": control.set_fps,
    }[param]
    results = parallel_map(lambda cam: fn(cam.ip, cam.port, cam.camera_id, value), targets)
    update_ack_table(results)
```

注意点:

- 連続送信を避けるため、デバウンス + 最終値優先で送信
- 失敗台を UI で明示し、再送ボタンを提供

### 6.6 時刻整合とペアリング

- 既存方針どおり `timestamp` 主、`frame_index` 副
- wand solver では `pair_window_us` 内の観測だけ採用
- 2台のみなら 1:1 近傍、3台以上なら中心 timestamp でクラスタ化

### 6.7 wand 対応付け（初版）

- 前提: 各フレームで wand 由来の 3 blob が主要成分
- 各カメラフレームで最大 3 blob を候補化（area 上位 + 位置安定）
- フレーム間で nearest-neighbor 追跡し ID 継続
- ID 不確定フレームは破棄（初版は recall より precision 優先）

### 6.8 extrinsics 推定（初版）

1. 参照カメラを 1 台固定（`R=I, t=0`）
2. 参照カメラとの 2D 対応点集合を構築
3. `findEssentialMat` + `recoverPose` で `R, t_unit` を推定
4. 三角測量で wand 3点を復元し、既知辺長との誤差最小でスケール `s` を推定
5. `t = s * t_unit` を確定
6. 全フレームで再投影誤差を算出
7. 必要なら非線形最適化（BA）で `R,t` を微調整

### 6.9 品質ゲート

- `inlier_ratio`（Essential 推定）
- `median_reproj_error_px`
- `baseline_m`（現実的範囲）
- フレーム採用率（有効フレーム数 / 総フレーム数）

### 6.10 発見ロジックの運用ルール

- 標準: passive 発見（UDP受信） + `hosts.ini` の併用
- active scan は初期リリースでは実装しない
- active scan を追加する条件（任意）:
  - Pi が UDP を送る前に GUI で即制御したい
  - DHCP 変動が激しく inventory 保守負荷が高い
  - 受動発見率が運用上不足

## 7. スキーマ計画

- 新規: `schema/calibration_extrinsics_v1.json`
- 主要フィールド案
  - `schema_version`
  - `reference_camera`
  - `camera_pairs[]`
  - `rotation_matrix`, `translation_vector`, `essential_matrix`, `fundamental_matrix`
  - `rms_error`, `baseline_m`, `captured_at`
  - `session_meta`（session_id、収録条件、wand 定義ID）

実装状況（2026-03-08）:

- ✅ `schema/calibration_extrinsics_v1.json` を追加済み
- ✅ `schema/README.md` に出力例と各フィールド説明を追記済み

## 8. 受け入れ条件（Phase 2 完了判定に追加）

- `mask_start` が 30 フレーム初期化を実行し、マスク状態が収録に反映される
- 2 台以上で wand 収録を実行し、extrinsics JSON を生成できる
- Host で intrinsics + extrinsics を読み込み、三角測量が継続動作する
- 再投影誤差・基線長が運用上不自然でない

## 9. リスクと対策

- **同期ズレ**: Host 主導 start/stop と timestamp 監視で補正
- **wand 対応付け誤り**: 3点幾何制約（辺長/角度）で外れ値除去
- **背景ノイズ残り**: `mask_start` のしきい値と 30 フレーム窓を調整可能にする
- **過剰マスク**: mask 適用率メトリクスを出し、異常時に `mask_stop` で解除
- **スケール不定**: 既知 wand 辺長を拘束に使い `t` スケールを決定
- **発見漏れ**: `hosts.ini` 併用と `ping` ヘルスチェックで補完

## 10. 段階導入

1. `mask_start` / `mask_stop` 実装
2. Host から複数 Pi へ制御一括実行（passive discovery + inventory）
3. 映像なし GUI（同期スライダー）実装
4. wand 収録ログ保存
5. extrinsics solver 最小実装（2 台）
6. `geo.py` で extrinsics ロード統合
7. 3 台以上へ拡張

## 11. 未確定事項（実装前に決める）

- `WAND_POINTS_MM` の現場再測（定期点検時のみ）
- `mask_start` パラメータ既定値
  - `threshold`, `hit_ratio`, `min_area_px`, `dilate_px`
- wand 収録時の最小 blob area / 最大 blob area
- quality gate の閾値

## 12. Host Wand Control GUI & Orchestration

### 12.1 `wand_session.py`: orchestration with control client + passive discovery

- `wand_session.py` becomes the Host-side coordinator that owns a `ControlClient`, an `UDPReceiver`, and the optional static inventory (`hosts.ini`).
- Discovery flow:
  1. `UDPReceiver.get_camera_addresses()` streams passive notices from Pis; merge these with `hosts.ini` entries by `camera_id` so that the most recent IP/port wins.
  2. `wand_session.WandSession.prepare_targets()` filters to healthy cameras by pinging each candidate once before the session starts.
- Control flow:
  1. Apply `set_exposure`, `set_gain`, `set_fps` with a shared payload before any capture commands.
  2. Issue `mask_start` and wait for each Pi to ack mask readiness; re-run once on failures, then abort if any camera still fails.
  3. Start the streaming window in `mode="wand_capture"`, track `session_id`, and keep a cancel token to stop the session if an error appears mid-run.
  4. After the desired duration or manual stop, send `stop` to all cameras and record the returned metadata.
- Pseudo code (simplified):

```python
class WandSession:
    def __init__(self, control_client, receiver, inventory):
        self.control = control_client
        self.receiver = receiver
        self.inventory = inventory

    async def run_session(self, config):
        targets = await self.prepare_targets(config.selection)
        await self.control.broadcast('set_exposure', targets, value=config.exposure_us)
        await self.control.broadcast('set_gain', targets, value=config.gain)
        await self.control.broadcast('set_fps', targets, value=config.fps)
        await self.control.broadcast('mask_start', targets, mask_params=config.mask)
        session = SessionMeta.create(config, targets)
        await self.control.broadcast('start', targets, mode='wand_capture', session_id=session.id)
        await wait(config.duration)
        await self.control.broadcast('stop', targets)
        session.finalize()
        await session.save()
```

### 12.2 Web UI architecture / slider sync & ack reporting

- 実装は `ThreadingHTTPServer` + `BaseHTTPRequestHandler` ベース（依存追加なし）。
- `src/host/wand_gui.py` が単一 HTML/JS ページを配信し、`/api/state`, `/api/config`, `/api/command` を提供。
- State: `selected_cameras`, `sync_enabled`, `last_ack_map`, `errors`, `is_running` per camera.
- Slider sync logic (debounced, final value only):

```python
async def apply_slider_sync(param: str, value: float | int):
    targets = ui_state.get_selected_cameras()
    fn = {
        'exposure_us': control_client.set_exposure,
        'gain': control_client.set_gain,
        'fps': control_client.set_fps,
    }[param]

    futures = [asyncio.create_task(fn(cam.address, cam.camera_id, value)) for cam in targets]
    results = await asyncio.gather(*futures, return_exceptions=True)

    ack_payload = []
    for cam, result in zip(targets, results):
        if isinstance(result, Exception):
            ack_payload.append({
                'camera_id': cam.camera_id,
                'ack': False,
                'error': str(result)
            })
        else:
            ack_payload.append({
                'camera_id': cam.camera_id,
                'ack': result.ack,
                'error': result.error_message,
            })

    await ui_state.websocket.broadcast({
        'type': 'slider_ack',
        'param': param,
        'value': value,
        'results': ack_payload,
    })
```

- JS front-end は `camera_id -> ack/error` の map を保持し、失敗台をテーブル表示する。
- operation log / replay button は未実装（今後の拡張項目）。

### 12.3 Operation coordination (mask_start / start / stop)

- Sequence:
  1. `mask_start`: orchestration module flushes previous mask states, instructs each Pi to capture 30 frames, and waits for boolean completion. Each result stores `mask_ratio` and `mask_pixels` for later diagnostics.
  2. `start`: `mode=wand_capture` and `session_id` are sent together to mark the beginning of wand sensing. All targets must ack; a failure triggers a `stop` call to the already-running cameras and aborts the session.
  3. `stop`: invoked either after the planned duration or early stop command. Responses include `frames_received`, `blobs_detected`, `mask_state`, `session_id` to ensure the session metadata aligns.
- Ack collection/reporting: every control request returns a `ControlResponse` (`ack`, `error_code`, `error_message`). `wand_session` aggregates these into `session.ack_history` for the UI and logs.

### 12.4 Dependencies

- Host control stack: existing `src/host/control.py` + `UDPReceiver` from `src/host/receiver.py`.
- Web stack: Python stdlib (`http.server`) + vanilla JS（追加依存なし）。
- Async support: 不要（現状は同期処理で順次反映）。

### 12.5 Implementation steps

1. ✅ `src/host/wand_session.py` を実装し、discovery merge / ping health check / metadata 永続化 / command dispatch を実装。
2. ✅ `src/host/control.py` の `mask_start` / `mask_stop` API を利用し、wand 制御フローを接続。
3. ✅ passive-first discovery merge（`UDPReceiver` + `hosts.ini`）を `wand_session` に実装。
4. ✅ `src/host/wand_gui.py` を実装（映像なし single-page + API）。
5. ✅ slider 同期時の ack/error 集約を GUI 状態へ反映。
6. ✅ `mask_start` / `start` / `stop` を GUI 操作から実行できるよう接続。
7. ✅ README 更新と smoke test 追加（`tests/test_wand_gui.py`, `tests/test_wand_extrinsics.py`）。

## 13. 次の改善ポイント（実装後）

1. 3台以上の同時最適化（global BA）を `calibrate_extrinsics.py` に追加する。
2. GUI にセッション履歴表示と `metadata_path` 参照 UI を追加する。
3. quality gate の運用閾値を `docs/requirements_def.md` と本書へ固定値で反映する。

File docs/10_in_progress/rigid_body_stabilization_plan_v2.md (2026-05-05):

# Rigid Body Stabilization V2 Plan

## Purpose

This plan defines the next PDCA entry point for improving 5-rigid tracking within the current hardware roadmap.

Current roadmap constraints:

- `4` cameras.
- `5` blobs / markers per rigid body.
- Passive or unlabeled blob observations.
- No LED-driven active marker ID.
- No 6+ marker rigid bodies.
- No 5+ camera expansion.

The research in `references/gpt_research/deep-research-report (2).md` still changes the direction, but only the parts that fit these constraints should drive the next PDCA cycle.

The useful lessons are:

- Treat BOOT, CONTINUE, and REACQUIRE as different modes with different evidence thresholds.
- Move away from marker-local threshold fixes toward body-level model-based assignment.
- Treat 2D blob quality as a first-class measurement confidence input.
- Keep subset uniqueness and strict partial-subset policy as design constraints.
- Use controlled ablations instead of repeatedly tuning pixel thresholds against the same hard frames.

Active IDs, 6-7 markers, and 6-8 cameras remain important prior-art signals, but they are not part of this implementation plan.

## Current State

The current simulator and design work has reached a useful but suspicious state:

- `candidate_00534` improves identity safety and timing over the current seed.
- Candidate-specific `object_gating_ambiguous_marker_assignment_min_margin_px = 0.50` cleans the known 240-frame hard boundary.
- The 480-frame hard high-noise run still fails on chest pose continuity after near-full occlusion.
- Several accepted fixes are narrow thresholds around close projected blobs and marker assignment margins.

This is a warning sign. The next step should not be another local threshold search. It should test whether the same constraints can be handled with cleaner mode separation, body-level assignment, and explicit blob confidence.

## Current Scenario Review

### What Is Appropriate

`five_rigid_body_occlusion_v1` is still the right hard fixture.

- It uses the 4-camera `cube_top_2_4m_aim_center` rig instead of a flat parallel layout.
- It covers the known body-mounted blockers: torso occlusion, seated waist, foot crossing, and camera-specific blob sizes.
- It has exposed realistic failure classes: marker swaps, cross-rigid wrong owner, low-marker hold, and sustained pose jumps.
- It keeps random false blobs out of the body-mounted route, which avoids optimizing for synthetic clutter instead of ownership.

`five_rigid_body_occlusion_relaxed_v1` remains useful as the green-regression entry.

- It catches obvious regressions without forcing every PDCA step through the hardest occlusion fixture.
- It should be the first smoke after any behavior change.

### What Needs Review

The current hard scenario risks overfitting because the same fixed frames keep driving threshold choices. For V2:

- Keep hard frames as diagnostic fixtures.
- Require seed repeats before adoption.
- Require at least one longer sustained run for any candidate that claims to improve continuity.
- Add diagnostics that explain why a body failed, not only whether it failed.

The sim also needs richer measurement diagnostics before more tracker tuning:

- per-camera blob area / equivalent diameter by marker and rigid.
- close-blob and merge-risk summaries.
- marker visibility by mode: BOOT, CONTINUE, REACQUIRE, and hold.
- candidate rejection reasons grouped by body and mode.
- body-level conflict events when two rigid hypotheses want the same blob.

## Environment Setup

Run from the repo root with the existing virtual environment.

Baseline commands:

```bash
PYTHONPATH=src .venv/bin/python -m tools.sim \
  --scenario five_rigid_body_occlusion_relaxed_v1 \
  --frames 240 \
  --fps 118 \
  --rigid-stabilization-profile gui_live \
  --noise-px 0.05 \
  --seed 45 \
  --false-blobs-per-camera 0 \
  --out logs/sim/passive_stabilization_v2/baseline_relaxed_seed45_noise005
```

```bash
PYTHONPATH=src .venv/bin/python -m tools.sim \
  --scenario five_rigid_body_occlusion_v1 \
  --frames 240 \
  --fps 118 \
  --rigid-stabilization-profile gui_live \
  --noise-px 0.10 \
  --seed 45 \
  --false-blobs-per-camera 0 \
  --out logs/sim/passive_stabilization_v2/baseline_hard_seed45_noise010
```

Use the current practical candidate package as the main baseline when testing structural changes:

- Candidate source: `logs/design/rigid_body_v2/candidates_pdca_cycle7/rank_04_candidate_00534.json`
- Sim rigids: `logs/design/rigid_body_v2/sim_pdca_cycle20_candidate00534_policy_expand2/candidate_00534_waist_expand2_tracking_rigids.json`
- Candidate-specific override: `object_gating_ambiguous_marker_assignment_min_margin_px = 0.50`

Also keep the current seed as a control. If a change only helps `candidate_00534`, it may still be useful, but it should not be called a general runtime fix.

## V2 Experiment Contract

Each experiment must report:

- `wrong_ownership_count`
- `marker_source_confusion_count`
- `valid_frame_ratio`
- `position_delta_top_events`
- `rotation_delta_top_events`
- `pipeline_pair_ms`
- `rigid_ms`
- `geometry_ms`
- `mode_counts_by_rigid`
- `boot_candidate_count_by_rigid`
- `continue_candidate_count_by_rigid`
- `reacquire_candidate_count_by_rigid`
- `hold_prediction_count_by_rigid`
- `candidate_rejection_reasons_by_mode`
- `body_conflict_count`
- `body_conflict_resolution_reasons`
- `blob_quality_summary_by_camera`
- `blob_quality_summary_by_rigid`
- local guard settings that were disabled, relaxed, or retained

Do not adopt any change that only improves a summary score while hiding the exact failure frames.

## Primary Strategy

### Strategy A - Mode Separation

The commercial-system lesson that fits the current roadmap is strict mode separation.

Desired mode policy:

| mode | evidence policy |
|---|---|
| BOOT | strictest; require whitelisted `4-of-5`, low 2D reprojection error, and clear body-level margin |
| CONTINUE | allow whitelisted `3-of-5` only as prediction confirmation, not independent identity evidence |
| SHORT-LOSS REACQUIRE | require prediction agreement and low innovation; do not scan generic blob clouds broadly |
| LONG-LOSS REACQUIRE | behave closer to BOOT; require whitelisted `4-of-5` and clear body-level margin |
| FULLY UNSEEN HOLD | hold only with bounded confidence decay; do not integrate stale angular evidence into a committed pose |

This should reduce the need for local close-blob rescue rules.

### Strategy B - Body-Level Assignment

The closest passive prior-art pattern is body-level model matching:

1. Use the predicted rigid pose to create per-marker 2D windows.
2. Build candidate marker-to-blob assignments per rigid body.
3. Score each body candidate with:
   - 2D reprojection residual.
   - 3D or projected distance signature consistency.
   - whitelisted subset strength.
   - temporal innovation.
   - blob quality weights.
   - margin over the second-best body candidate.
4. Resolve cross-body blob conflicts at the body-candidate level.
5. Commit the winning pose only if the body-level margin is strong enough for the current mode.

The goal is to replace scattered marker-local rejection thresholds with one explainable body-candidate score.

### Strategy C - Blob Quality Confidence

The current close-blob rules are proxy quality measures. V2 should make measurement confidence explicit.

Initial blob quality inputs:

- area
- equivalent diameter
- nearest-neighbor blob distance
- diameter-relative overlap risk
- temporal area change
- temporal centroid jump
- camera id
- expected marker projection distance

Future real-Pi inputs, if available:

- circularity
- bounding box width / height
- saturation or bloom proxy
- contour merge / intrusion flag

Policy:

- Bad blob quality should lower candidate confidence.
- Severe quality failure should produce a missing marker, not a wrong marker.
- Blob quality should be logged before it is used for hard rejection.

## Out Of Scope For This Plan

The following are useful research conclusions but not current roadmap items:

- LED-driven active markers.
- Active anchor IDs.
- 6+ marker rigid bodies.
- 5+ camera or 6-8 camera expansion.

Keep them as future branches. Do not let them drive V2 acceptance criteria.

## Initial PDCA Entry

PDCA must remain sequential.

### Baseline 0 - Current Candidate Package

Measure `candidate_00534` with the current runtime package.

Matrix:

| scenario | frames | seeds | noise |
|---|---:|---|---|
| `five_rigid_body_occlusion_relaxed_v1` | `240` | `45,46,47` | `0.05px` |
| `five_rigid_body_occlusion_v1` | `240` | `45,46,47` | `0.05px` |
| `five_rigid_body_occlusion_v1` | `240` | `45,46,47` | `0.10px` |
| `five_rigid_body_occlusion_v1` | `480` | `45` | `0.15px` |

Read:

- Identity status: wrong/confusion.
- Validity floor by rigid.
- Chest sustained jump frames.
- Timing p95 and over-budget runs.
- Mode transitions around the top delta events.
- Candidate rejection reasons around the top delta events.

Decision:

- If this no longer reproduces the known state, stop and restore baseline before changing behavior.

### Cycle 1 - Add Passive Diagnostics Only

Hypothesis:

- Current summaries are too coarse; richer diagnostics can identify whether failures are mode-policy, assignment, or blob-quality problems.

Change:

- Add mode counts, rejection reasons, body conflict counts, and blob quality summaries.
- Do not change tracking behavior.

Measure:

- Run Baseline 0 seed `45` relaxed and hard.

Decision:

- Keep only if behavior is exactly unchanged and diagnostics explain the known chest / waist / foot failures.

### Cycle 2 - Long-Loss REACQUIRE As BOOT

Hypothesis:

- The dangerous ownership decisions happen after longer loss windows, so long-loss reacquire should use BOOT-like evidence.

Change:

- After a configurable loss age, starting at `8` frames, require whitelisted `4-of-5`, 2D score, and body-level margin.
- Short-loss continuation remains unchanged.

Measure:

- Hard seed `45`, noise `0.10px`.
- If green, repeat seed `46`.

Decision:

- Keep if wrong/confusion do not increase, valid ratio stays at least equal to baseline, and top delta events do not worsen.

### Cycle 3 - Body-Level Candidate Margin Diagnostics

Hypothesis:

- Existing local guard failures can be explained by weak body-level candidate margin.

Change:

- Compute body-level candidate score and second-best margin in diagnostics.
- Do not enforce yet.

Measure:

- Hard seed `45`, noise `0.10px`.
- Hard seed `45`, `480` frames, noise `0.15px`.

Decision:

- Keep if diagnostics show whether known jumps are caused by low margin, low visibility, or bad measurement quality.

### Cycle 4 - Enforce Body-Level Margin In REACQUIRE Only

Hypothesis:

- Reacquire is the safest place to replace local thresholds with body-level candidate margin.

Change:

- Enforce body-level margin for REACQUIRE candidates only.
- Do not change CONTINUE.
- Do not change blob-quality rejection yet.

Measure:

- Relaxed seeds `45,46,47`, noise `0.05px`.
- Hard seeds `45,46,47`, noise `0.10px`.

Decision:

- Keep if wrong/confusion stay `0/0`, valid does not drop below baseline, and timing stays near baseline.

### Cycle 5 - Relax Candidate-Specific Marker Margin

Hypothesis:

- Body-level reacquire scoring can replace the candidate-specific `0.50px` marker assignment margin.

Change:

- Return marker margin to the current global default for this candidate.
- Keep body-level REACQUIRE margin from Cycle 4.

Measure:

- Hard seeds `45,46,47`, noise `0.10px`.

Decision:

- Keep if wrong/confusion remain `0/0`, valid remains at baseline, and timing improves or stays equal.

### Cycle 6 - Blob Quality Weighting Diagnostics

Hypothesis:

- Some remaining marker confusion and pose jumps are measurement-quality failures, not identity failures.

Change:

- Add blob-quality weights to candidate scoring in diagnostics only.
- Compare weighted and unweighted candidate ranks.

Measure:

- Hard seed `45`, noise `0.10px`.
- Hard seed `45`, `480` frames, noise `0.15px`.

Decision:

- Keep if blob quality explains known failure frames without changing behavior.

### Cycle 7 - Blob Quality Missing-Marker Policy

Hypothesis:

- Severe blob-quality failures should become missing observations instead of weak wrong observations.

Change:

- Enforce quality-based missing marker only in REACQUIRE or low-confidence CONTINUE.
- Do not apply it to all valid continuation frames.

Measure:

- Relaxed seeds `45,46,47`, noise `0.05px`.
- Hard seeds `45,46,47`, noise `0.10px`.
- If green, hard seed `45`, `480` frames, noise `0.15px`.

Decision:

- Keep if identity stays clean, valid ratio does not drop below baseline, and sustained chest jumps improve.

## Goal Conditions
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

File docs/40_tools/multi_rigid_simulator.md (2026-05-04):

# Multi-Rigid Simulator

`tools/sim/` は Loutrack runtime とは独立した開発用シミュレーター。
実機や GUI を起動せずに、合成 2D blob を `TrackingPipeline` へ流し、multi-rigid tracking の精度、所有権、復帰、処理時間を検証するために使う。

## 目的

- `waist` + `wand` の遮蔽、復帰、吸い込みを deterministic に再現する。
- GT pose と estimator pose を比較する。
- `(timestamp, camera_id, emitted_blob_index)` の sidecar ledger で blob ownership を検証する。
- `Frame.blobs` には GT metadata を混ぜず、実 payload と同じ shape を保つ。
- 118fps の production budget を summary の go/no-go として確認する。
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

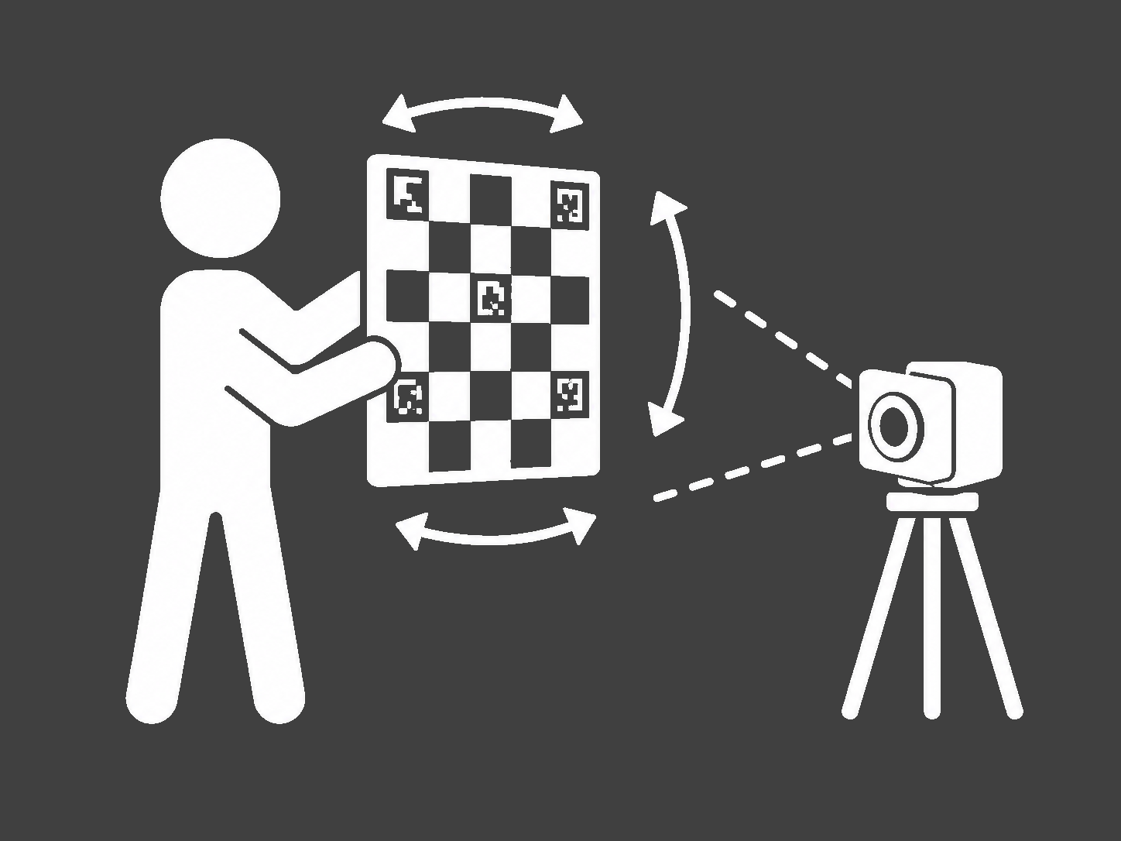
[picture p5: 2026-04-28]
static/intrinsics.png

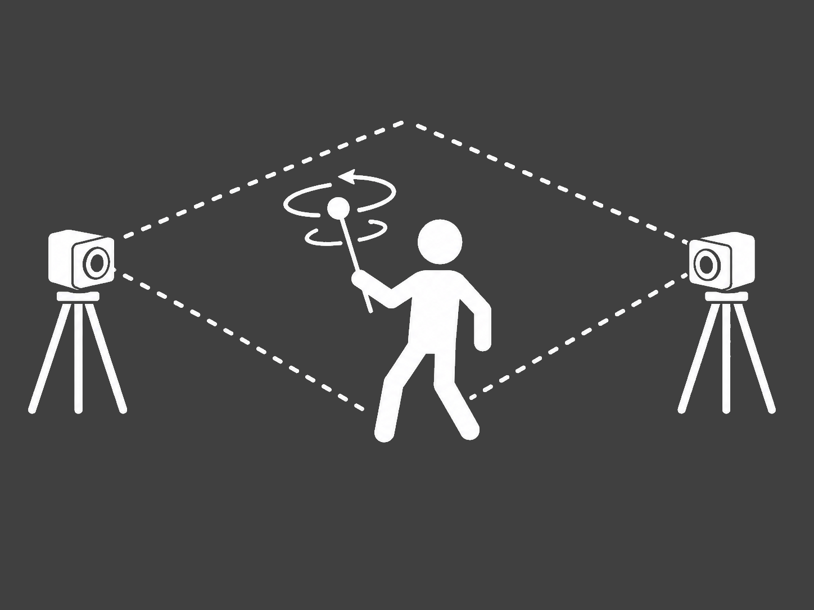
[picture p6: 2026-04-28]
static/extrinsics.png

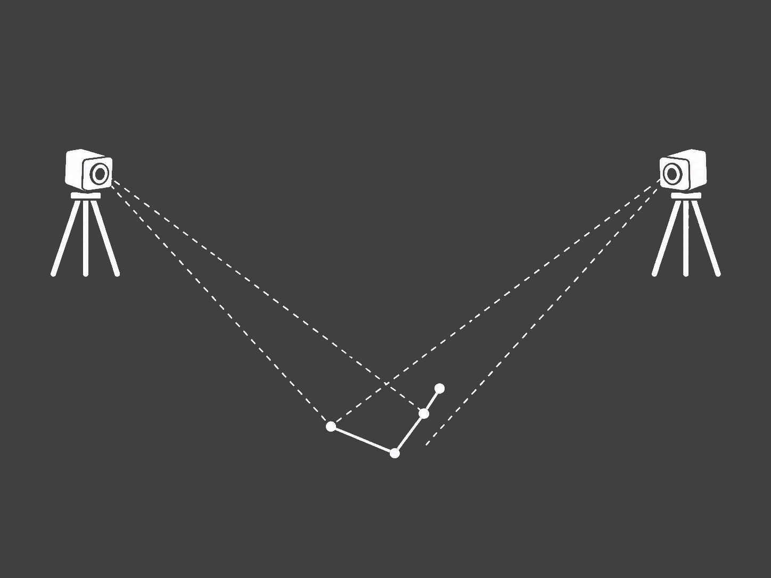
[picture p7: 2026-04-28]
static/wand.png

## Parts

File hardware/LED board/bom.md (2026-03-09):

# LED board BOM

KiCad 回路図 `hardware/LED board/kicad/LEDHat1.4_low_heat/LEDHat.kicad_sch` と添付画像を基準に、実装点数ベースで整理。

## 実装部品

| 回路図 | 部品 | 値 / 型番 | 実装数 | 現行購入候補 | URL | 購入単位 | 推奨購入数 | メモ |
|---|---|---|---:|---|---|---|---:|---|
| J1 | ピンソケット (メス) | 2x20 (40P) | 1 | 100085 | https://akizukidenshi.com/catalog/g/g100085/ | 1個 | 1 | Raspberry Pi GPIO 用 |
| D1-D24 | 赤外線LED | 940nm OSI5LAS1C1A | 24 | 106427 | https://akizukidenshi.com/catalog/g/g106427/ | 10個/パック | 3パック | 24個使用 |
| Q1 | Nch MOSFET | IRLML6344 | 1 | 106049 | https://akizukidenshi.com/catalog/g/g106049/ | 10個/パック | 1パック | メイン LED 群スイッチ |
| Q_R, Q_G, Q_B | Nch MOSFET | 2N7002E | 3 | 117477 | https://akizukidenshi.com/catalog/g/g117477/ | 5個/パック | 1パック | RGB LED 各色スイッチ |
| D31 | RGBフルカラーLED | 5mm 4本足 | 1 | 111852 | https://akizukidenshi.com/catalog/g/g111852/ | 1個 | 1 | 状態表示用 |
| R1-R8 | カーボン抵抗 | 1/4W 12Ω | 8 | 114271 | https://akizukidenshi.com/catalog/g/g114271/ | 100本/袋 | 1袋 | IR LED 4列分の直列抵抗 |
| R0 | カーボン抵抗 | 1/4W 470Ω | 1 | 125471 | https://akizukidenshi.com/catalog/g/g125471/ | 100本/袋 | 1袋 | RGB LED 用の直列抵抗 |
| J2 | 電源コネクタ | 1x2 Male | 1 | 112986 | https://akizukidenshi.com/catalog/g/g112986/ | 1個 | 1 | `1x10 L型ピンヘッダ` を 2 ピン分に切って使用 |

## 回路図から読める数量メモ

- 赤外線 LED は 6個 x 4列 = 24個。
- 12Ω 抵抗は 2本 x 4列 = 8本。
- RGB LED は 1個、制御 MOSFET は 3個。
- 電源側 MOSFET `Q1` は 1個。

## 補足

- `J2` は `1x10 L型ピンヘッダ` を 2 ピン分に切って使用する前提。
- 取り付け部材、配線材、スペーサー、ヒートシンク等の機構部品は回路図からは判断できないため未記載。

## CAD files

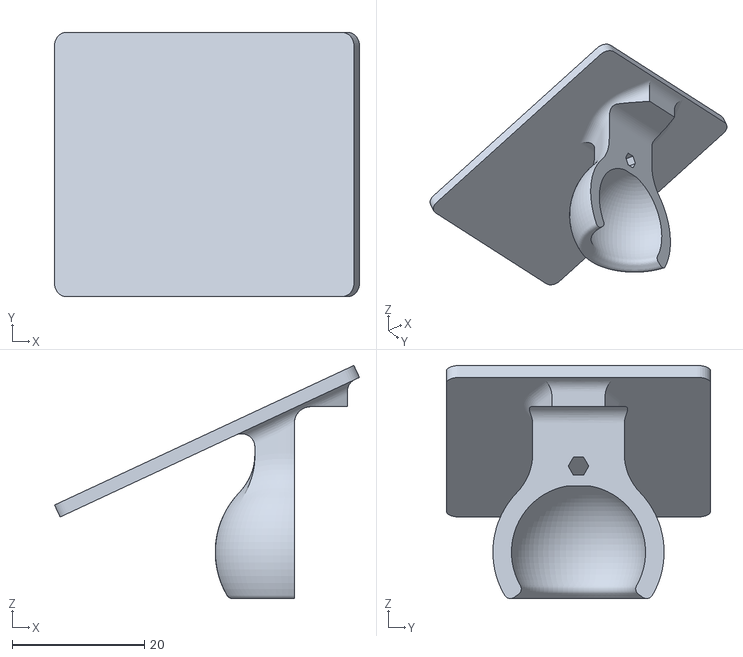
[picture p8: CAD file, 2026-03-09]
hardware/pi mount/base.stl
46.2 x 40.0 x 35.3

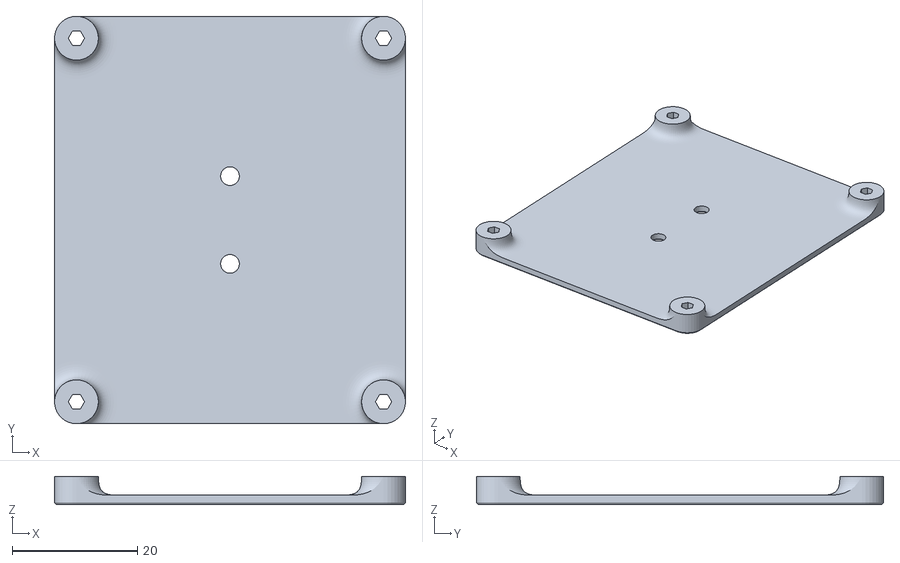
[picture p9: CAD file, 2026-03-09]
hardware/pi mount/plate.stl
56.0 x 65.0 x 4.50

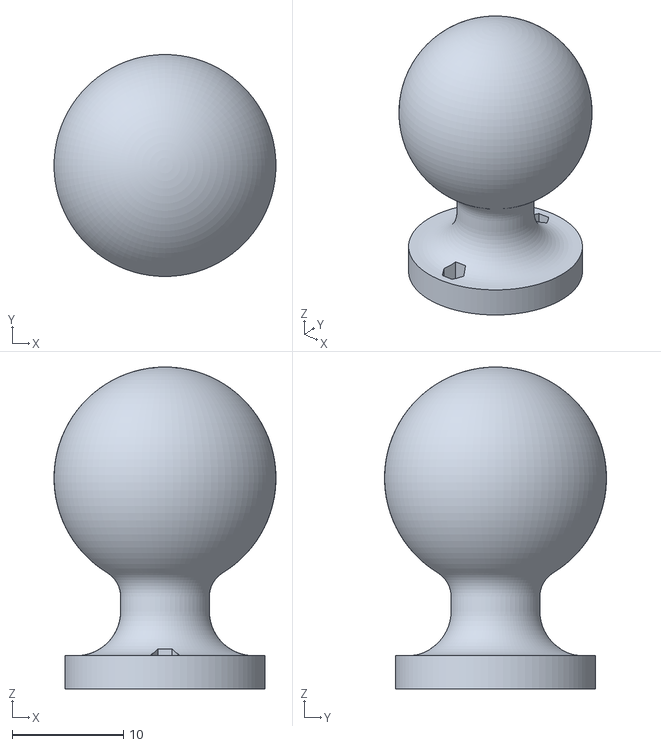
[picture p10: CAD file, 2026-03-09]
hardware/pi mount/Ball.stl
20.0 x 20.0 x 29.0

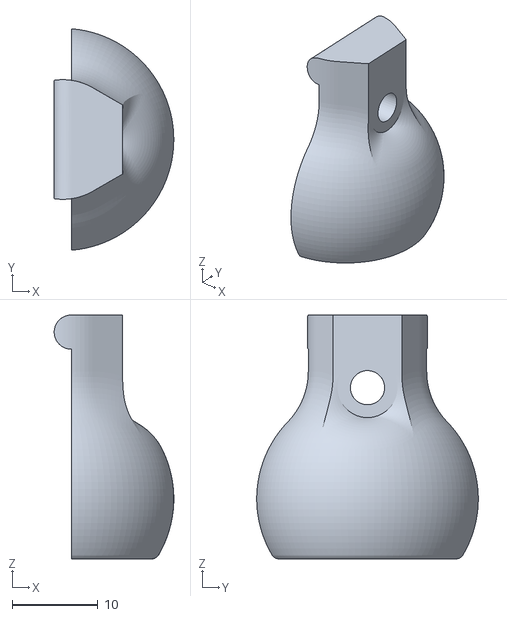
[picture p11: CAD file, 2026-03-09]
hardware/pi mount/clamp1.stl
14.0 x 25.9 x 28.5

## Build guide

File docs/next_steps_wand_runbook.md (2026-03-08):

# next_steps_wand_runbook

wand 外部較正を実行するための作業手順書（実装済みフロー準拠）。

## 1. 目的

- 複数 Pi の wand 収録を Host 主導で実行する。
- 収録ログから `calibration_extrinsics_v1.json` を生成する。
- Host 側で intrinsics + extrinsics を同時ロードして動作確認する。

## 2. 前提条件

以下を「収録前チェック」として上から順に実施する。

### 2.1 Host 環境の準備

1. 作業ディレクトリへ移動:

```bash
cd /path/to/Loutrack2
```

2. 仮想環境を作成（初回のみ）:

```bash
python3 -m venv .venv --system-site-packages
```

3. 仮想環境を有効化:

```bash
source .venv/bin/activate
```

4. pip を更新:

```bash
python -m pip install --upgrade pip
```

5. 依存パッケージを導入:

```bash
pip install -r requirements.txt
```

6. 主要スクリプトが起動可能なことを確認:

```bash
python src/host/wand_gui.py --help
python src/camera-calibration/calibrate_extrinsics.py --help
```

### 2.2 Pi 側 venv 準備と capture サービス起動

各 Pi で以下を実施する（初回セットアップ + 起動確認）。

1. 作業ディレクトリへ移動:

```bash
cd /home/<PI_USER>/Loutrack2
```

2. 仮想環境を作成（初回のみ）:

```bash
python3 -m venv .venv --system-site-packages
```

3. 仮想環境を有効化:

```bash
source .venv/bin/activate
```

4. pip を更新:

```bash
python -m pip install --upgrade pip
```

5. 依存パッケージを導入:

```bash
pip install -r requirements.txt
```

7. capture スクリプトの起動確認:

```bash
python src/pi/capture.py --help
```

8. capture サービスを起動（デフォルト `--tcp-port 8554`、`--camera-id` 未指定時は device name を使用）:

```bash
python src/pi/capture.py
```

既定の capture 解像度は `2304x1296`（`docs/next_steps_charuco.md` の live 較正前提と同じ）である。

9. 検出状況を Pi 上で確認したい場合は debug preview 付きで起動:

```bash
python src/pi/capture.py --debug-preview
```

SSH で Pi に入って起動する場合は、先に desktop display を渡す:

```bash
export DISPLAY=:0
export XAUTHORITY=/home/<PI_USER>/.Xauthority
python src/pi/capture.py --debug-preview
```

debug preview で確認できる内容:

- 採用された blob の円表示
- mask 領域のオーバーレイ
- `threshold`, `diameter`, `circularity` 設定
- `accepted/raw/rejected` の簡易診断
- GUI で blob 調整中 / `mask_start` 実行中 / wand 収録中の状態表示

補足:

- `camera_id` は inventory（`src/deploy/hosts.ini`）と一致させる
- 既定値を上書きしたい場合のみ `--camera-id "$CAMERA_ID"` を指定する
- ポート変更時のみ `--tcp-port`（Pi 側）と `--port`（Host 側）を同じ値に合わせる
- `--debug-preview` は debug 用。Pi がデスクトップモードなら OpenCV window が常時更新される
- `DISPLAY` がない SSH shell / headless 環境では preview は起動前に自動で無効化される

### 2.3 Pi 側 capture サービスの確認

各 Pi で以下を満たすこと:

- `src/pi/capture.py` が `mask_start` / `mask_stop` / `start(mode=wand_capture)` 対応版で起動している
- `camera_id` が固有で重複しない
- control port `8554` で応答できる

Host から疎通確認（各 Pi 分実施）:

```bash
python -m src.host.control --ip <PI_IP> --camera-id <CAMERA_ID> ping
```

期待値:

- 返却 JSON に `"ack": true` が含まれる

### 2.4 inventory と camera_id の整合

1. inventory を確認:

```bash
cat src/deploy/hosts.ini
```

2. 確認ポイント:

- 1行につき 1 台
- `camera_id` 重複なし
- IP が最新

例（形式）:

```ini
pi-cam-01 <PI_IP_01> pi-cam-01
pi-cam-02 <PI_IP_02> pi-cam-02
```

### 2.5 ネットワーク前提（受動発見 + 制御）

- Host と全 Pi が同一 L2/L3 セグメントで通信可能
- Pi -> Host の UDP 送信（既定: 5000/udp）が通る
- Host -> Pi の TCP 制御（8554/tcp）が通る

確認の目安:

1. GUI 起動後 `Refresh` でカメラが列挙される（受動発見 + inventory merge）
2. `Ping` 実行で `last_ack=true` が返る

### 2.6 内部較正ファイルの確認

外部較正の前に、対象カメラ分の intrinsics が揃っていることを確認:

```bash
ls -1 calibration/calibration_intrinsics_v1_*.json
```

最低条件:

- wand 収録対象の全 camera_id についてファイルが存在する
- 各 JSON に `camera_id`, `camera_matrix`, `distortion_coefficients` が含まれる

簡易チェック（1ファイル例）:

```bash
python - <<'PY'
import json
path = "calibration/calibration_intrinsics_v1_pi-cam-01.json"
data = json.load(open(path, "r", encoding="utf-8"))
required = ["camera_id", "camera_matrix", "distortion_coefficients"]
missing = [k for k in required if k not in data]
print("missing:", missing)
PY
```

### 2.7 wand 物理条件の確認

- wand 定義: `WAND_POINTS_MM = [(0,0,0), (168,0,0), (0,243,0)]`
- 3 marker の center-to-center 実寸が定義値と一致
- マーカー径 14mm

注意:

- 実寸がズレると `baseline_m` とスケール推定が崩れる
- 反射材の汚れ・剥離がある場合は交換してから収録する

## 3. 事前確認

1. inventory を確認する:

```bash
cat src/deploy/hosts.ini
```

2. 受動発見を使う場合は Pi から UDP が流れていることを確認する。

3. 最低 2 台が疎通することを確認する（例）:

```bash
python -m src.host.control --ip <PI_IP_01> --camera-id pi-cam-01 ping
python -m src.host.control --ip <PI_IP_02> --camera-id pi-cam-02 ping
```

## 4. 収録手順（GUI 運用）

1. GUI を起動:

```bash
python src/host/wand_gui.py --host <HOST_IP> --port 8765 --udp-port 5000
```

2. ブラウザで `http://<HOST_IP>:8765/` を開く。

3. GUI のセグメント順に進める。基本導線は以下:
   - `Blob Detection Adjustment`
   - `Mask Adjustment`
   - `Wand Capture`
   - `Extrinsics Generation`

4. `Refresh` → 対象カメラを選択 → `Ping` 実行。

5. `Blob Detection Adjustment` でスライダーを調整して `Apply Blob Settings`:
   - `exposure_us`
   - `gain`
   - `fps`
   - `focus`（既定値 `5.215`）
   - `threshold`
   - `circularity_min`
   - `blob min/max diameter px`
   - Pi を `--debug-preview` 付きで起動していれば、Pi デスクトップ上の preview を見ながら blob 条件を詰められる

6. `Mask Adjustment` で `Build Mask` 実行。
   - `mask threshold` と `mask seconds` は GUI 側設定を使用する
   - `mask seconds * fps` で内部の `frames` が計算される
   - 実行中は Pi preview に `MASK_INIT` が表示され、完了後は mask overlay が残る
   - `Build Mask` は既存 mask を上書き更新できる。明示的に消したい場合だけ `Clear Mask` を使う

7. `Wand Capture` で `Start Wand Capture` 実行後、wand を空間全体で 60 秒程度動かす（20 ポーズ以上）。
   - 収録中も Pi preview が継続し、wand 操作系の見え方を遠隔確認できる

8. `Stop Capture` 実行。

9. 収録後、`Extrinsics Generation` で `Generate Extrinsics` を実行:
   - `Intrinsics Dir`: 例 `calibration`
   - `Log Path`: 収録ログ JSONL のパス
   - `Output Path`: 例 `calibration/calibration_extrinsics_v1.json`

## 5. 収録手順（CLI 運用）

GUI を使わない場合は `WandSession` を直接実行する。

```python
from src.host.wand_session import SessionConfig, WandSession

session = WandSession()
result = session.run_session(
    SessionConfig(
        exposure_us=12000,
        gain=8.0,
        fps=56,
        duration_s=60.0,
    )
)
print(result["session_id"])
print(result["metadata_path"])
```

## 6. 外部較正の生成

収録ログ（JSONL）を指定して extrinsics を作成する。

```bash
python src/camera-calibration/calibrate_extrinsics.py \
  --intrinsics calibration \
  --log logs/<wand_capture_log>.jsonl \
  --output calibration/calibration_extrinsics_v1.json \
  --pair-window-us 5000 \
  --min-pairs 8
```

必要に応じて参照カメラを固定:

```bash
python src/camera-calibration/calibrate_extrinsics.py \
  --intrinsics calibration \
  --log logs/<wand_capture_log>.jsonl \
  --reference-camera pi-cam-01
```

## 7. 検証

1. 出力 JSON の生成確認:

```bash
ls -l calibration/calibration_extrinsics_v1.json
```

2. Host 幾何ロード確認（`geo.py` は intrinsics と extrinsics を同時ロード）:

```python
from src.host.geo import GeometryPipeline

geo = GeometryPipeline()
count = geo.load_calibration("calibration")
print("loaded cameras:", count)
print("camera ids:", geo.get_camera_ids())
```

3. 主要 quality 値確認:
   - `cameras[].quality.inlier_ratio`
   - `cameras[].quality.median_reproj_error_px`
   - `cameras[].quality.baseline_m`

## 8. トラブルシュート

- `mask_start` 失敗:
  - 光源反射が強すぎる場合、露光を下げる。
  - `mask_start` を再実行する。
- `Not enough paired observations`:
  - 収録時間を延長し、wand の姿勢バリエーションを増やす。
  - `--pair-window-us` を少し広げる（例: 7000）。
- `findEssentialMat failed`:
  - 対象カメラが同じ視野を十分に共有しているか確認する。
  - 2D blob の誤検出が多い場合は threshold / mask 条件を見直す。
- `baseline_m` が不自然:
  - wand の実寸（center-to-center）を再確認する。
  - `blobs` に wand 以外が混入していないかログ確認する。

## 9. 成果物

- 収録セッション metadata:
  - `logs/wand_sessions/<session_id>.json`
- 外部較正成果物:
  - `calibration/calibration_extrinsics_v1.json`
- 参照スキーマ:
  - `schema/calibration_extrinsics_v1.json`

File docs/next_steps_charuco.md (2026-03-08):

# Charuco較正: 実機ゼロベース手順

このドキュメントは、sim/self-test の結果を参照せず、実機で内部較正を最初から作り直すための手順書です。

## 前提

- 対象: Raspberry Pi Camera Module 3 Wide
- 実測値: 5マス = 150 mm
- 1マス換算: `150 / 5 = 30.0 mm`
- 本手順での指定値: `--square-length-mm 30.0`
- 実機メモ: `LensPosition=5.2` が現時点で最も安定
- Loutrack2 の現行 live capture 既定解像度: `2304x1296`

---

## Step 0: まっさらな Raspberry Pi の初期セットアップ

Raspberry Pi Connect で画面共有できている前提で、内部較正を実行可能な状態まで準備する。

### 0-1. OS 更新と基本ツール

```bash
sudo apt update && sudo apt upgrade -y
sudo apt install -y git python3-pip python3-venv
```

### 0-2. リポジトリ取得

```bash
cd ~
git clone https://github.com/<YOUR_ACCOUNT>/Loutrack2.git
cd Loutrack2
```

### 0-3. Python 仮想環境（重要）

`python3-picamera2` は apt でシステム側に入るため、仮想環境は `--system-site-packages` 付きで作成する。

```bash
python3 -m venv .venv --system-site-packages
source .venv/bin/activate
python -m pip install --upgrade pip
pip install -r requirements.txt
```

### 0-4. Pi カメラ依存（ライブ較正用）

```bash
sudo apt install -y python3-picamera2
sudo reboot
```

再起動後:

```bash
cd ~/Loutrack2
source .venv/bin/activate
```

### 0-5. カメラ動作確認

OS によって `rpicam-hello` または `libcamera-hello` を使う。

```bash
rpicam-hello -t 3000
```

`rpicam-hello` が無い場合:

```bash
libcamera-hello -t 3000
```

加えて Python 側確認:

```bash
python3 -c "from picamera2 import Picamera2; print('picamera2 ok')"
```

### 0-6. トラブルシュート（`picamera2 is required` が出る場合）

`calibrate.py` で次のエラーが出る場合:

`ERROR: picamera2 is required for live capture mode.`

多くは venv から apt の `picamera2` が見えていないことが原因。以下で venv を作り直す。

```bash
cd ~/Loutrack2
deactivate 2>/dev/null || true
rm -rf .venv
python3 -m venv .venv --system-site-packages
source .venv/bin/activate
python -m pip install --upgrade pip
pip install -r requirements.txt
python -c "from picamera2 import Picamera2; print('picamera2 ok')"
```

それでも import できない場合:

```bash
sudo apt install -y python3-picamera2
sudo reboot
```

---

## Step 1: `pi-cam-01` を実機で新規内部較正する

最初は `pi-cam-01` だけで実行し、手順と品質基準を固める。

```bash
python src/camera-calibration/calibrate.py \
  --camera pi-cam-01 \
  --square-length-mm 30.0 \
  --min-frames 25 \
  --output "./calibration/calibration_intrinsics_v1_pi-cam-01.json"
```

ライブ撮影時の操作:

- `SPACE`: 有効フレーム取り込み
- `C`: 較正実行
- `Q`: 終了

### Step 1 の具体的な進め方

結論としては「`SPACE` を連打して十分な有効フレームを集めてから `C`」でよい。
ただし、同じ構図を連打しても精度が上がりにくいので、毎回ボード位置と角度を変える。

1. 起動直後にプレビューでピントと露出を確認する。
2. ボードを中央で正面に置き、`SPACE` を 3-5 回取得する。
3. ボードを四隅（左上/右上/左下/右下）へ移動し、各位置で 3-5 回ずつ `SPACE`。
4. 距離を変える（近距離/中距離/遠距離）ごとに 3-5 回ずつ `SPACE`。
5. 角度を変える（左右に傾ける、上下に傾ける）ごとに 3-5 回ずつ `SPACE`。
6. 合計 25 枚に達したら、可能なら 30-40 枚まで追加する。
7. 取得後に `C` を押して較正を実行する。
8. 保存結果を確認し、必要なら `Q` で終了して再実行する。

### 押し方の注意

- `SPACE` は「検出が安定して見える瞬間」に押す。
- 手ブレ中に連打しない（近いフレームが重複しやすい）。
- 1秒に1回程度を目安に、構図を変えながら押す。
- `C` は最低25枚を満たしてから押す。
- `C` 実行後にエラーや品質不良なら、撮影分布を改善してやり直す。

撮影の実践ルール:

- 25枚以上、推奨30-40枚
- 中央だけでなく四隅・画面端を含める
- 近距離/遠距離、正面/斜めを混ぜる
- いろんな構図で撮る（位置・距離・角度を毎回変える）
- 構図が被らないようにする（同じ見え方の連続取得を避ける）
- フォーカスは可能なら `LensPosition=5.2` を基準値として試す
- ブレ、露出飽和、ピンぼけを避ける

---

## Step 2: `pi-cam-01` の結果を確認する

確認対象: `calibration/calibration_intrinsics_v1_pi-cam-01.json`

暫定の合格基準:

- `rms_error < 1.0`（理想 `< 0.5`）
- `quality.num_valid_frames >= 25`
- `per_view_errors` に極端な外れ値が連続しない

NG の場合は Step 1 を再実行し、以下を優先的に改善する。

- ボードの角度・距離バリエーションを増やす
- 画面周辺での取得枚数を増やす
- ピントと露出を調整する

---

## Step 3: `pi-cam-02` に同じ手順を適用する

`pi-cam-01` で手順が安定したら、同じ条件で `pi-cam-02` を実施する。

```bash
python src/camera-calibration/calibrate.py \
  --camera pi-cam-02 \
  --square-length-mm 30.0 \
  --min-frames 25 \
  --output "./calibration/calibration_intrinsics_v1_pi-cam-02.json"
```

結果確認の観点は Step 2 と同じ。

---

## Step 4: 外部較正（wand 方式）

内部較正2台分が揃った後に、B5 L字 3点 wand（14mm blob）で外部較正を実装・実行する。

Host 主導の基本シーケンス:

1. `set_exposure` / `set_gain` / `set_fps` を配布
2. `mask_start` で 30 フレーム初期化（背景明点マスク）
3. `start` で wand 収録開始
4. 20+ ポーズ収録（推奨 60 秒）
5. `stop` で収録終了
6. Host で extrinsics solver を実行

- 実装予定: `src/camera-calibration/calibrate_extrinsics.py`
- 出力予定: `calibration/calibration_extrinsics_v1.json`
- 詳細計画: `docs/wand_extrinsics_plan.md`

---

## Step 5: ワークフロー統合

最終的な流れ:

1. Charuco ボード印刷と実測
2. 各カメラで内部較正（intrinsics）
3. 複数カメラ同時撮影データ取得
4. wand 収録と外部較正（extrinsics）
5. Host 側で読み込み、三角測量検証

---

## 優先順位まとめ

| 優先度 | タスク | 依存 |
|---|---|---|
| P0 | `pi-cam-01` 実機内部較正（ゼロベース） | なし |
| P0 | `pi-cam-01` 結果レビューと再撮影判定 | P0 |
| P0 | `pi-cam-02` 実機内部較正 | `pi-cam-01` 手順確定 |
| P1 | 外部較正スクリプト実装 | P0完了 |
| P1 | 外部較正スキーマ定義 | なし |
| P2 | 較正ワークフロー統合 | P1完了 |

---

## 参考リンク

- OpenCV Camera Calibration: https://docs.opencv.org/4.x/dc/dbb/tutorial_py_calibration.html
- OpenCV Stereo Calibration: https://docs.opencv.org/4.x/d9/d0c/group__calib3d.html#ga3207604e4b1a1758aa66acb6ed5aa65d

---

## 運用ルール

- sim/self-test の出力は本書の判定基準に使わない。
- 実測で進捗が出たら `README.md` の TODO と Phase 状態を同時更新する。

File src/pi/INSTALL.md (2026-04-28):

# Loutrack Pi first install

This guide is for a user who has never set up Loutrack before. It explains how to prepare a fresh Raspberry Pi OS install, choose names, install the Loutrack camera service, and make the Pi appear in the Loutrack GUI.

## What You Need

- Raspberry Pi camera node hardware with the camera connected
- Raspberry Pi OS Lite 64-bit
- Wired Ethernet is strongly recommended for PTP sync
- A host PC on the same LAN running the Loutrack GUI
- This repository copied or cloned onto each Pi

## Naming Rules

Use the same value for the Pi hostname and Loutrack camera id whenever possible.

Recommended names:

| Role | Hostname | Camera ID | PTP role |
| --- | --- | --- | --- |
| First / clock source Pi | `pi-cam-01` | `pi-cam-01` | `master` |
| Second Pi | `pi-cam-02` | `pi-cam-02` | `slave` |
| Third Pi | `pi-cam-03` | `pi-cam-03` | `slave` |

For now, use the Linux username `pi`. The GUI Pi Admin path defaults to SSH user `pi`, so choosing this username keeps first setup simple.

## Raspberry Pi Imager Settings

In Raspberry Pi Imager, choose Raspberry Pi OS Lite 64-bit and open OS customization.

Set:

- Hostname: `pi-cam-01`, `pi-cam-02`, etc.
- Username: `pi`
- Password: choose a local admin password
- SSH: enabled
- SSH authentication: public key is preferred
- Locale/timezone: your local settings
- Network: wired Ethernet preferred; set Wi-Fi only if needed

If you use SSH keys, paste the public key for the host PC that will run the Loutrack GUI. This allows GUI Pi Admin actions to connect later.

Write the image, insert it into the Pi, connect camera and network, then boot.

## Get The Repository Onto The Pi

Log into the Pi with SSH:

```bash
ssh pi@pi-cam-01.local
```

Then clone or copy this repository onto the Pi. Enter the repository root before running the installer:

```bash
cd Loutrack2
```

If you copied a zip instead of using git, make sure the directory still contains `src/pi` and `src/camera-calibration`.

## Install The Master Pi

Run this on `pi-cam-01`:

```bash
sudo ./src/pi/install_loutrack_node.sh \
  --camera-id pi-cam-01 \
  --ptp-role master
```

The master Pi briefly uses NTP to set wall-clock time, then becomes the Loutrack PTP grandmaster.

## Install Slave Pis

Run this on every other Pi, changing the camera id:

```bash
sudo ./src/pi/install_loutrack_node.sh \
  --camera-id pi-cam-02 \
  --ptp-role slave
```

For a third Pi:

```bash
sudo ./src/pi/install_loutrack_node.sh \
  --camera-id pi-cam-03 \
  --ptp-role slave
```

## Optional Installer Flags

Common options:

```bash
sudo ./src/pi/install_loutrack_node.sh \
  --camera-id pi-cam-02 \
  --ptp-role slave \
  --interface eth0 \
  --timestamping software \
  --udp-dest 255.255.255.255:5000
```

Use `--user <name>` only if you intentionally did not create the `pi` user. If you do that, GUI Pi Admin must also be configured to use the same SSH user before management actions will work.

Use `--authorized-key-file <path>` or `--authorized-key "<public key>"` if you did not add the GUI host key in Raspberry Pi Imager.

Use `--no-start` when you want to install the service but start it manually later.

## What The Installer Does

The installer:

- Installs Pi runtime packages: `linuxptp`, `python3-picamera2`, `python3-opencv`, `python3-numpy`, `python3-scipy`, `rsync`, and related basics
- Copies `src/pi` and `src/camera-calibration` into the Loutrack release layout
- Calls `src/pi/setup_ptp.sh` with the selected `master` or `slave` role
- Creates and enables `loutrack.service`
- Adds non-interactive sudo permissions needed by GUI Pi Admin
- Starts the service unless `--no-start` was used

## Verify On The Pi

Check the capture service:

```bash
systemctl status loutrack.service
journalctl -u loutrack.service -n 80 --no-pager
```

Check PTP:

```bash
systemctl status loutrack-ptp4l.service
```

Check the camera Python stack:

```bash
python3 -c "from picamera2 import Picamera2; print('picamera2 ok')"
```

## Make The Pi Appear In The GUI

Start the Loutrack GUI on the host PC, then open Camera Status.

If the Pi service is running and UDP broadcast reaches the host, cameras should appear automatically. If not, add or update `src/deploy/hosts.ini` on the host PC:

```ini
pi-cam-01 192.168.8.223 pi-cam-01
pi-cam-02 192.168.8.100 pi-cam-02
```

Then press Refresh in the GUI.

The GUI Pi Admin buttons use SSH. They expect:

- The Pi is reachable on the LAN
- SSH is enabled
- The GUI host public key is authorized for user `pi`
- The installer has completed sudoers setup

## Troubleshooting

If the GUI shows `No Ack`, check:

```bash
systemctl status loutrack.service
journalctl -u loutrack.service -n 80 --no-pager
```

If the camera backend is unavailable, check the ribbon cable and run:

```bash
python3 -c "from picamera2 import Picamera2; p=Picamera2(); print('created')"
```

If PTP does not lock, make sure:

- `pi-cam-01` was installed as `master`
- all other Pi cameras were installed as `slave`
- all Pi cameras are on the same wired Ethernet segment
- no other time sync service is fighting Loutrack PTP

If SSH admin actions fail from the GUI, check that the host PC key is present for the `pi` user and that the installer was run successfully.

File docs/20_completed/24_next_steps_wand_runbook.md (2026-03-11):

# next_steps_wand_runbook

wand 外部較正を実行するための作業手順書（実装済みフロー準拠）。

## 1. 目的

- 複数 Pi の wand 収録を Host 主導で実行する。
- 収録ログから `calibration_extrinsics_v1.json` を生成する。
- Host 側で intrinsics + extrinsics を同時ロードして動作確認する。

## 2. 前提条件

以下を「収録前チェック」として上から順に実施する。

### 2.1 Host 環境の準備

1. 作業ディレクトリへ移動:

```bash
cd /path/to/Loutrack2
```

2. 仮想環境を作成（初回のみ）:

```bash
python3 -m venv .venv --system-site-packages
```

3. 仮想環境を有効化:

```bash
source .venv/bin/activate
```

4. pip を更新:

```bash
python -m pip install --upgrade pip
```

5. 依存パッケージを導入:

```bash
pip install -r requirements.txt
```

6. 主要スクリプトが起動可能なことを確認:

```bash
python src/host/wand_gui.py --help
python src/camera-calibration/calibrate_extrinsics.py --help
```

### 2.2 Pi 側 venv 準備と capture サービス起動

各 Pi で以下を実施する（初回セットアップ + 起動確認）。

1. 作業ディレクトリへ移動:

```bash
cd /home/<PI_USER>/Loutrack2
```

2. 仮想環境を作成（初回のみ）:

```bash
python3 -m venv .venv --system-site-packages
```

3. 仮想環境を有効化:

```bash
source .venv/bin/activate
```

4. pip を更新:

```bash
python -m pip install --upgrade pip
```

5. 依存パッケージを導入:

```bash
pip install -r requirements.txt
```

7. capture スクリプトの起動確認:

```bash
python src/pi/capture.py --help
```

8. capture サービスを起動（デフォルト `--tcp-port 8554`、`--camera-id` 未指定時は device name を使用）:

```bash
python src/pi/capture.py
```

既定の capture 解像度は `2304x1296`（`docs/10_in_progress/next_steps_charuco.md` の live 較正前提と同じ）である。

9. 検出状況を Pi 上で確認したい場合は debug preview 付きで起動:

```bash
python src/pi/capture.py --debug-preview
```

debug preview で確認できる内容:

- 採用された blob の円表示
- mask 領域のオーバーレイ
- `threshold`, `diameter`, `circularity` 設定
- `accepted/raw/rejected` の簡易診断
- GUI で blob 調整中 / `mask_start` 実行中 / wand 収録中の状態表示

補足:

- `camera_id` は inventory（`src/deploy/hosts.ini`）と一致させる
- 既定値を上書きしたい場合のみ `--camera-id "$CAMERA_ID"` を指定する
- ポート変更時のみ `--tcp-port`（Pi 側）と `--port`（Host 側）を同じ値に合わせる
- `--debug-preview` は debug 用。Pi がデスクトップモードなら OpenCV window が常時更新される
- `DISPLAY` がない SSH shell / headless 環境では preview は起動前に自動で無効化される

### 2.3 Pi 側 capture サービスの確認

各 Pi で以下を満たすこと:

- `src/pi/capture.py` が `mask_start` / `mask_stop` / `start(mode=wand_capture)` 対応版で起動している
- `camera_id` が固有で重複しない
- control port `8554` で応答できる

Host から疎通確認（各 Pi 分実施）:

```bash
python -m src.host.control --ip <PI_IP> --camera-id <CAMERA_ID> ping
```

期待値:

- 返却 JSON に `"ack": true` が含まれる

### 2.4 inventory と camera_id の整合

1. inventory を確認:

```bash
cat src/deploy/hosts.ini
```

2. 確認ポイント:

- 1行につき 1 台
- `camera_id` 重複なし
- IP が最新

例（形式）:

```ini
pi-cam-01 <PI_IP_01> pi-cam-01
pi-cam-02 <PI_IP_02> pi-cam-02
```

### 2.5 ネットワーク前提（受動発見 + 制御）

- Host と全 Pi が同一 L2/L3 セグメントで通信可能
- Pi -> Host の UDP 送信（既定: 5000/udp）が通る
- Host -> Pi の TCP 制御（8554/tcp）が通る

確認の目安:

1. GUI 起動後 `Refresh` でカメラが列挙される（受動発見 + inventory merge）
2. `Ping` 実行で `last_ack=true` が返る

### 2.6 内部較正ファイルの確認

外部較正の前に、対象カメラ分の intrinsics が揃っていることを確認:

```bash
ls -1 calibration/calibration_intrinsics_v1_*.json
```

最低条件:

- wand 収録対象の全 camera_id についてファイルが存在する
- 各 JSON に `camera_id`, `camera_matrix`, `distortion_coefficients` が含まれる

簡易チェック（1ファイル例）:

```bash
python - <<'PY'
import json
path = "calibration/calibration_intrinsics_v1_pi-cam-01.json"
data = json.load(open(path, "r", encoding="utf-8"))
required = ["camera_id", "camera_matrix", "distortion_coefficients"]
missing = [k for k in required if k not in data]
print("missing:", missing)
PY
```

### 2.7 wand 物理条件の確認

- wand 定義: `WAND_POINTS_MM = [(0,0,0), (0,182,0), (132,0,0), (257,0,0)]` (`[elbow, short, mid, long]` の中心座標)
- 3 marker の center-to-center 実寸が定義値と一致
- マーカー径 14mm

## 3. 事前確認

1. inventory を確認する:
ここにpiのIPを設定

```bash
cat src/deploy/hosts.ini
```

2. 受動発見を使う場合は Pi から UDP が流れていることを確認する。

3. 最低 2 台が疎通することを確認する（例）:

```bash
python -m src.host.control --ip <PI_IP_01> --camera-id pi-cam-01 ping
python -m src.host.control --ip <PI_IP_02> --camera-id pi-cam-02 ping
```

## 4. 収録手順（GUI 運用）

1. GUI を起動:

```bash
python src/host/wand_gui.py --host <HOST_IP> --port 8765 --udp-port 5000
```

2. ブラウザで `http://<HOST_IP>:8765/` を開く。

3. GUI のセグメント順に進める。基本導線は以下:
   - `Blob Detection Adjustment`
   - `Mask Adjustment`
   - `Wand Capture`
   - `Extrinsics Generation`

4. `Refresh` → 対象カメラを選択 → `Ping` 実行。

5. `Blob Detection Adjustment` でスライダーを調整して `Apply Blob Settings`:
   - `exposure_us`
   - `gain`
   - `fps`
   - `focus`（既定値 `5.215`・Raspberry Pi Camera Module 3 Wide Noir　準拠）
   - `threshold`
   - `circularity_min`
   - `blob min/max diameter px`
   - Pi を `--debug-preview` 付きで起動していれば、Pi デスクトップ上の preview を見ながら blob 条件を詰められる

6. `Mask Adjustment` で `Build Mask` 実行。
   - `mask threshold` と `mask seconds` は GUI 側設定を使用する
   - `mask seconds * fps` で内部の `frames` が計算される
   - 実行中は Pi preview に `MASK_INIT` が表示され、完了後は mask overlay が残る
   - `Build Mask` は既存 mask を上書き更新できる。明示的に消したい場合だけ `Clear Mask` を使う

7. `Wand Capture` で `Start Wand Capture` 実行後、wand を空間全体で 60 秒程度動かす（20 ポーズ以上）。
   - 収録中も Pi preview が継続し、wand 操作系の見え方を遠隔確認できる

8. `Stop Capture` 実行。

9. 収録後、`Extrinsics Generation` で `Generate Extrinsics` を実行:
   - `Intrinsics Dir`: 例 `calibration`
   - `Log Path`: 収録ログ JSONL のパス
   - `Output Path`: 例 `calibration/calibration_extrinsics_v1.json`

## 5. 収録手順（CLI 運用）

GUI を使わない場合は `WandSession` を直接実行する。

```python
from src.host.wand_session import SessionConfig, WandSession

session = WandSession()
result = session.run_session(
    SessionConfig(
        exposure_us=12000,
        gain=8.0,
        fps=56,
        duration_s=60.0,
    )
)
print(result["session_id"])
print(result["metadata_path"])
```

## 6. 外部較正の生成

収録ログ（JSONL）を指定して extrinsics を作成する。

```bash
python src/camera-calibration/calibrate_extrinsics.py \
  --intrinsics calibration \
  --log logs/<wand_capture_log>.jsonl \
  --output calibration/calibration_extrinsics_v1.json \
  --pair-window-us 8000 \
  --min-pairs 8
```

必要に応じて参照カメラを固定:

```bash
python src/camera-calibration/calibrate_extrinsics.py \
  --intrinsics calibration \
  --log logs/<wand_capture_log>.jsonl \
  --reference-camera pi-cam-01
```

## 7. 検証

1. 出力 JSON の生成確認:

```bash
ls -l calibration/calibration_extrinsics_v1.json
```

2. Host 幾何ロード確認（`geo.py` は intrinsics と extrinsics を同時ロード）:

```python
from src.host.geo import GeometryPipeline

geo = GeometryPipeline()
count = geo.load_calibration("calibration")
print("loaded cameras:", count)
print("camera ids:", geo.get_camera_ids())
```

3. 主要 quality 値確認:
   - `cameras[].quality.inlier_ratio`
   - `cameras[].quality.median_reproj_error_px`
   - `cameras[].quality.baseline_m`

## 7.1 wand を動かすコツ（収録品質を上げる）

- 画面中央だけで振らず、各カメラの四隅と上下端まで使って大きく動かす。
- 手前/奥への移動を必ず入れ、2D 平面内の往復だけにしない。
- 2 台で同時に見えている時間を長く保つ（片側だけで見切れる時間を減らす）。
- 速すぎる振りは避ける（モーションブラーで 3 点検出が崩れやすい）。
- wand の姿勢を変える（寝かせる/立てる/ひねる）ことで幾何拘束を増やす。
- 10〜20 秒は連続収録し、停止と再開を繰り返さない。
- 収録中は GUI の blob 状態を見て、各カメラで 3 点検出率が高い状態を維持する。

## 8. トラブルシュート

- `mask_start` 失敗:
  - 光源反射が強すぎる場合、露光を下げる。
  - `mask_start` を再実行する。
- `Not enough paired observations`:
  - 収録時間を延長し、wand の姿勢バリエーションを増やす。
  - `--pair-window-us` を少し広げる（例: 15000）。
- `findEssentialMat failed`:
  - 対象カメラが同じ視野を十分に共有しているか確認する。
  - 2D blob の誤検出が多い場合は threshold / mask 条件を見直す。
- `baseline_m` が不自然:
  - wand の実寸（center-to-center）を再確認する。
  - `blobs` に wand 以外が混入していないかログ確認する。

## 9. 成果物

- 収録セッション metadata:
  - `logs/wand_sessions/<session_id>.json`
- 外部較正成果物:
  - `calibration/calibration_extrinsics_v1.json`
- 参照スキーマ:
  - `schema/calibration_extrinsics_v1.json`

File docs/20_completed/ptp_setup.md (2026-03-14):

# Raspberry Pi 5 と PTP

実は Raspberry Pi 5 は Gigabit Ethernet コントローラを通じて PTP 機能を利用できます。実際のタイムスタンプ精度やサポートレベルは、カーネルバージョンやドライバの実装に依存する場合があります。

## 環境確認

PTP が利用できるかどうかは、`ethtool -T eth0` コマンドで確認します。Raspberry Pi OS (Bookworm 以降) では `linuxptp` ツールスイートを利用して PTP 同期を設定できます。`PTP Hardware Clock: 0` とインデックス番号が表示されれば PTP ハードウェアクロックが利用可能です。

```sh
$ ethtool -T eth0
```

```text
Time stamping parameters for eth0:
Capabilities:
  hardware-transmit
  software-transmit
  hardware-receive
  software-receive
  software-system-clock
  hardware-raw-clock
PTP Hardware Clock: 0
Hardware Transmit Timestamp Modes:
  off
  on
  onestep-sync
Hardware Receive Filter Modes:
  none
  all
```

## linuxptp の概要

`linuxptp` は PTP (Precision Time Protocol) を Linux システムで利用するためのツール群です。通常は **ptp4l** と **phc2sys** の両方を組み合わせて使用し、高精度な時刻同期を実現します。

## システム情報

```sh
$ cat /etc/os-release
```

```text
PRETTY_NAME="Debian GNU/Linux 12 (bookworm)"
NAME="Debian GNU/Linux"
VERSION_ID="12"
VERSION="12 (bookworm)"
VERSION_CODENAME=bookworm
ID=debian
HOME_URL="https://www.debian.org/"
SUPPORT_URL="https://www.debian.org/support"
BUG_REPORT_URL="https://bugs.debian.org/"
```

```sh
$ uname -r
```

```text
6.12.25+rpt-rpi-2712
```

> **注**: 本記事は 2025 年 5 月 21 日時点の情報です。使用している Debian は **12 (bookworm)**、カーネルは **6.12.25+rpt‑rpi‑2712** です。

## 主要なツールと PTP の基本的な仕組み・役割

- **ptp4l** – NIC の PHC を PTP ネットワーク上のマスタークロックに同期させたり、逆にマスタークロックとして振る舞ったりするデーモン。
- **phc2sys** – NIC のハードウェアクロック (PHC) とシステムクロック (CLOCK_REALTIME) を相互に同期させるプログラム。
- **Grandmaster Clock** – ネットワーク全体の時刻基準となる最も正確なクロック源。
- **Master Clock** – Grandmaster から時刻情報を受け取り、下位のスレーブに配信するクロック。
- **Slave Clock** – マスターから時刻情報を受け取り、自身のクロックをマスターに同期させる。

PTP はこれらのデバイス間で時刻情報を交換し、伝搬遅延を計算・補正することで高精度な同期を実現します。大規模・高精度が要求されるシステムでは専用の Grandmaster が必要ですが、Raspberry Pi 5 でも小規模〜中規模ネットワークのマスター／スレーブとして十分機能します。

## Raspberry Pi 5 での PTP 実装手順概要

### 必要パッケージのインストール

```sh
sudo apt update
sudo apt install linuxptp
sudo apt install ufw
sudo ufw allow 319
sudo ufw allow 320
```

### PTP マスター側の設定

#### 1. 設定ファイル (`/etc/linuxptp/ptp-master.conf`)

```ini
[global]
time_stamping hardware
masterOnly 1
priority1 128
```

#### 2. PHC とシステムクロックの同期 (phc2sys)

```sh
sudo phc2sys -s CLOCK_REALTIME -c eth0 -O 0 --step_threshold 0.5 -m
```

実行例（ログ抜粋）:

```text
phc2sys[10753.997]: eth0 sys offset -1058242430566 s0 freq +0 delay 55
phc2sys[10754.997]: eth0 sys offset -1058242483590 s1 freq -53017 delay 37
phc2sys[10755.997]: eth0 sys offset -1262 s2 freq -54279 delay 37
phc2sys[10756.990]: eth0 sys offset 16 s2 freq -53380 delay 37
```

#### 3. ptp4l の起動 (マスター)

```sh
sudo ptp4l -f /etc/linuxptp/ptp-master.conf -i eth0 -m
```

実行結果の重要ポイントは `assuming the grand master role` というメッセージです。

#### 4. 簡易起動スクリプト例 (`/etc/linuxptp/ptp-master.sh`)

```sh
#!/bin/bash
sudo ptp4l -f /etc/linuxptp/ptp-master.conf -i eth0 -m > /var/log/ptp4l.log 2>&1 &
sudo phc2sys -s CLOCK_REALTIME -c eth0 -O 0 --step_threshold 0.5 -m > /var/log/phc2sys.log 2>&1 &
```

ログ確認例:

```sh
sudo tail -f /var/log/ptp4l.log
```

> **注意**: サービス化する前の一時的な確認手段です。最終的には systemd サービスとして登録します。

### PTP スレーブ側の設定

#### 1. ptp4l の起動（スレーブモード）

```sh
sudo ptp4l -i eth0 -s -m --summary_interval 1
```

ログ例:

```text
ptp4l[4518.538]: selected /dev/ptp0 as PTP clock
ptp4l[4518.538]: port 1: INITIALIZING to LISTENING on INIT_COMPLETE
ptp4l[4518.538]: port 0: INITIALIZING to LISTENING on INIT_COMPLETE
ptp4l[4518.842]: port 1: new foreign master 2ccf67.fffe.290682-1
ptp4l[4522.842]: selected best master clock 2ccf67.fffe.290682
…
```

#### 2. PHC とシステムクロックの同期 (phc2sys)

```sh
sudo phc2sys -s eth0 -c CLOCK_REALTIME -O 0 --step_threshold 0.5 -m
```

### systemd によるサービス化

#### マスター側 service ファイル

- **ptp4l‑master.service**

```ini
[Unit]
Description=PTP4L Master Daemon
After=network-online.target
Wants=network-online.target
ExecStartPre=/bin/sleep 10

[Service]
Type=simple
ExecStart=/usr/sbin/ptp4l -f /etc/linuxptp/ptp-master.conf -i eth0 -m
Restart=on-failure

[Install]
WantedBy=multi-user.target
```

- **phc2sys‑master.service**

```ini
[Unit]
Description=PHC2SYS Master Daemon (System Clock to PHC)
After=ptp4l-master.service
Requires=ptp4l-master.service

[Service]
Type=simple
ExecStart=/usr/sbin/phc2sys -s CLOCK_REALTIME -c eth0 -O 0 --step_threshold 0.5 -w -m
Restart=on-failure

[Install]
WantedBy=multi-user.target
```

#### スレーブ側 service ファイル

- **ptp4l‑slave.service**

```ini
[Unit]
Description=PTP4L Slave Daemon
After=network-online.target
Wants=network-online.target
ExecStartPre=/bin/sleep 10

[Service]
Type=simple
ExecStart=/usr/sbin/ptp4l -i eth0 -s -m --summary_interval 1
Restart=on-failure

[Install]
WantedBy=multi-user.target
```

- **phc2sys‑slave.service**

```ini
[Unit]
Description=PHC2SYS Slave Daemon (PHC to System Clock)
After=ptp4l-slave.service
Requires=ptp4l-slave.service

[Service]
Type=simple
ExecStart=/usr/sbin/phc2sys -s eth0 -c CLOCK_REALTIME -O 0 --step_threshold 0.5 -w -m
Restart=on-failure

[Install]
WantedBy=multi-user.target
```

#### サービスの登録・起動・確認

```sh
sudo systemctl daemon-reload
sudo systemctl enable ptp4l-master.service
sudo systemctl enable phc2sys-master.service
sudo systemctl enable ptp4l-slave.service
sudo systemctl enable phc2sys-slave.service

sudo systemctl start ptp4l-master.service
sudo systemctl start phc2sys-master.service
sudo systemctl start ptp4l-slave.service
sudo systemctl start phc2sys-slave.service

# ステータス確認例
sudo systemctl status ptp4l-master.service
sudo systemctl status phc2sys-master.service
sudo systemctl status ptp4l-slave.service
sudo systemctl status phc2sys-slave.service
```

> **注意**: PTP を利用して高精度な時刻同期を行う際は、`systemd-timesyncd` など他の時刻同期サービスを停止してください。

```sh
sudo systemctl stop systemd-timesyncd
sudo systemctl disable systemd-timesyncd
```

## PTP 同期の確認方法

- **スレーブ側**: `ptp4l` のログで `master offset` や `delay` を確認
  ```sh
  sudo journalctl -u ptp4l-slave.service -f
  ```
- **マスター側**: `ptp4l` の `assuming the grand master role` が表示されているか確認
  ```sh
  sudo journalctl -u ptp4l-master.service -f
  ```
- **phc2sys** のログでもクロック同期状況を確認
  ```sh
  sudo journalctl -u phc2sys-master.service -f
  sudo journalctl -u phc2sys-slave.service -f
  ```

## 時間単位の換算表

- 1 秒 (s) = 1,000 ミリ秒 (ms)
- 1 ミリ秒 (ms) = 1,000 マイクロ秒 (µs)
- 1 マイクロ秒 (µs) = 1,000 ナノ秒 (ns)

以上が Raspberry Pi 5 を用いた PTP 同期の手順と確認方法です。実際に動作させる際は、ログを定期的に確認し、オフセットが数十ナノ秒レベルに収束していることを目安にしてください。

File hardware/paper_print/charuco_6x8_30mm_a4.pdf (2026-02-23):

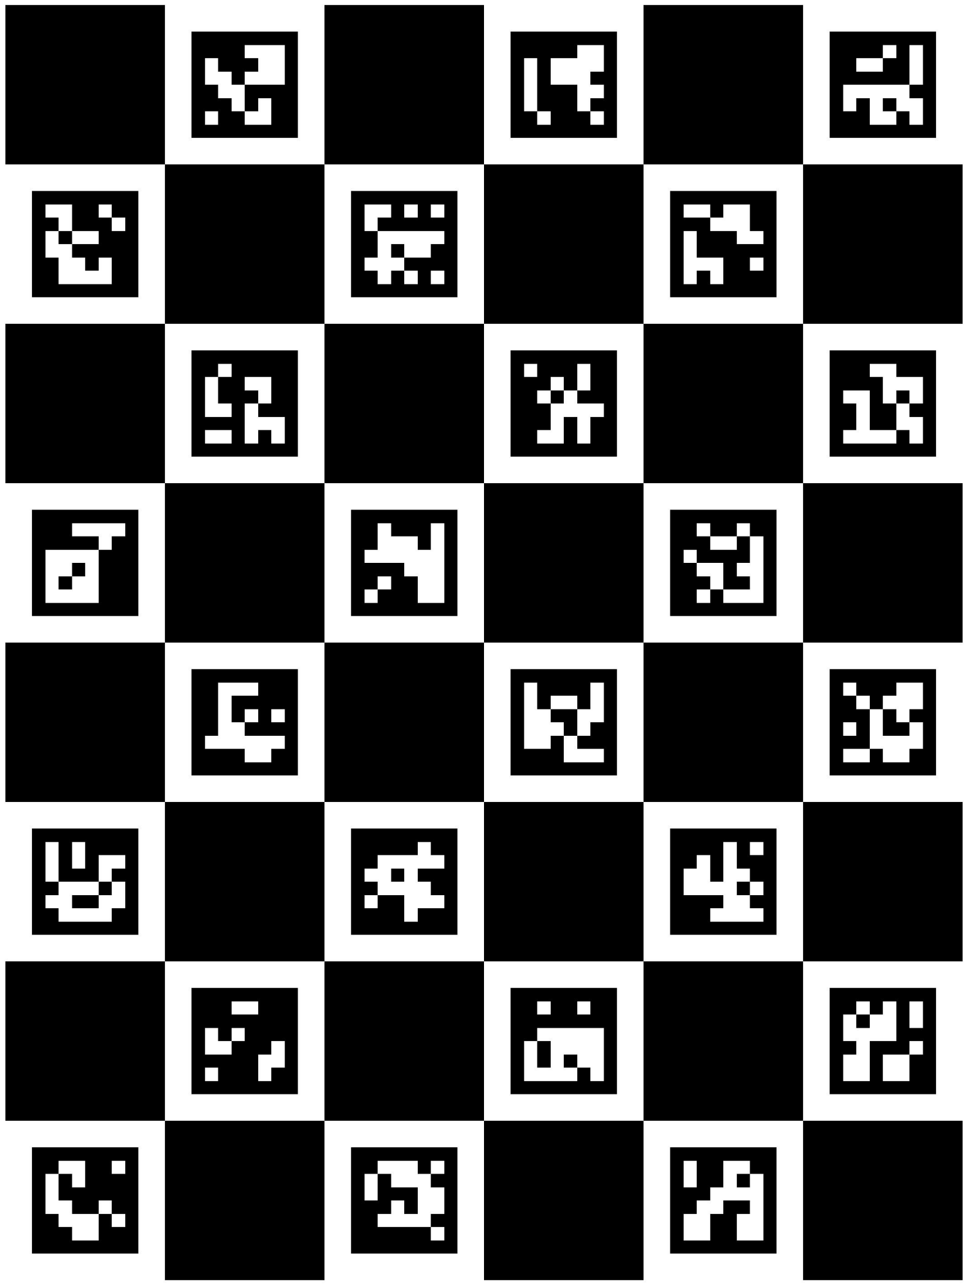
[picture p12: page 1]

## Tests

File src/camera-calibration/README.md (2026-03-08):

# camera-calibration

Loutrack2 向けの Charuco ボードベース内部較正ツールです。

## 概要

このディレクトリには次の 2 つのスクリプトがあります。

- `charuco_board.py`: 印刷用 Charuco ボード（A4 PDF）を生成
- `calibrate.py`: Charuco 観測からカメラ内部パラメータを推定

`calibrate.py` は次のモードをサポートします。

- ライブ撮影モード（Pi Camera、`picamera2` 必須）
- オフラインモード（`--input-dir` で画像群を指定）
- ハードウェア不要の自己テスト（`--self-test`）

## ファイル

- `src/camera-calibration/charuco_board.py`
- `src/camera-calibration/calibrate.py`

## 前提条件

- Python 3.9+
- ArUco 対応 OpenCV（`opencv-python`）
- NumPy
- Pillow（`charuco_board.py` の PDF 出力で使用）
- （ライブモードのみ）Raspberry Pi 上の `picamera2`

リポジトリルートで依存をインストール:

```bash
pip install -r requirements.txt
```

## 1) Charuco ボード生成

基本コマンド:

```bash
python src/camera-calibration/charuco_board.py \
  --output "./calibration/boards/charuco_6x8_30mm_a4.pdf" \
  --write-metadata
```

印刷時の重要ポイント:

- 100% スケールで印刷する
- fit-to-page を無効にする
- 印刷後に 1 マスの辺長を実測し、その値を較正に使う

主なオプション:

- `--squares-x` / `--squares-y`（既定値: `6` / `8`）
- `--square-length-mm`（既定値: `30.0`）
- `--marker-length-mm`（既定値: `20.0`）
- `--dictionary`（既定値: `DICT_6X6_250`）
- `--dpi`（既定値: `300`）
- `--write-metadata`（PDF 横にメタデータ JSON を出力）

## 2) カメラ内部較正の実行

`--square-length-mm` は全モードで必須です。

### A. ライブ撮影モード（Raspberry Pi）

```bash
python src/camera-calibration/calibrate.py \
  --camera pi-cam-01 \
  --square-length-mm <MEASURED_MM> \
  --output "./calibration/calibration_intrinsics_v1_pi-cam-01.json"
```

ライブ撮影時のキー操作:

- `SPACE`: フレームを取り込み（コーナー検出時のみ）
- `C`: 較正を実行（最小有効フレーム数を満たしたとき）
- `Q`: 終了

### B. オフラインモード（画像ディレクトリ）

```bash
python src/camera-calibration/calibrate.py \
  --camera pi-cam-01 \
  --square-length-mm <MEASURED_MM> \
  --input-dir "./calibration/images/pi-cam-01" \
  --output "./calibration/calibration_intrinsics_v1_pi-cam-01.json"
```

### C. 自己テストモード（合成データ）

```bash
python src/camera-calibration/calibrate.py \
  --camera pi-cam-01 \
  --square-length-mm 30.0 \
  --self-test \
  --self-test-views 30 \
  --seed 0
```

## 出力

較正結果はリポジトリのスキーマ形式 JSON で保存されます。

- `calibration/calibration_intrinsics_v1_<camera_id>.json`

主な出力項目:

- カメラ行列（`fx`, `fy`, `cx`, `cy`）
- 歪み係数（`k1`, `k2`, `p1`, `p2`, `k3`）
- `rms_error`
- ボード設定と品質指標（`per_view_errors`、有効フレーム数など）

## 品質目安

- RMS 誤差の目安: 理想 `< 0.5 px`、許容 `< 1.0 px`
- 有効フレームは最低 `25` 枚以上（`--min-frames`、既定 `25`）
- 位置・傾き・距離・向きを変えて多様な姿勢で撮影する
- ピントずれやブレを避ける

### 有効フレームの考え方

このツールでの「有効フレーム」は、Charuco コーナーが十分に検出できた画像です。
`calibrate.py` では、1 フレーム中に検出された Charuco コーナーが一定数未満の場合、そのフレームは較正に使われません。

撮影時の実践ポイント:

- 中央だけでなく、画面の四隅・端にもボードを配置する
- 正面だけでなく、角度・距離を変えて撮る（近距離/遠距離を混ぜる）
- 露出過多・反射・モーションブラーを避ける

### ボードが見切れるフレームについて

ボード全体が必ずしも写っている必要はありません。
一部が見切れていてもコーナーが十分検出できれば有効です。

ただし、見切れたフレームだけに偏ると推定が不安定になることがあります。
「全体が見えるフレーム」と「端で一部見切れるフレーム」を混ぜると、歪み推定の安定性が上がります。

`per_view_errors` に極端な値が出る場合は次を再確認してください。

- 印刷スケールが正確に 100% か
- `--square-length-mm` に実測値を正しく渡しているか
- 画像中のコーナー検出品質が十分か

## 実運用手順書（内部較正）

以下は、印刷ボード作成から較正 JSON 出力までの推奨手順です。

0. **Pi 側で実行する場合の準備**

   ライブ撮影モード（Pi Camera を直接使うモード）は Raspberry Pi 上で実行します。
   スクリプトだけでなく、依存とボードも必要です。

   - Pi に配置: `src/camera-calibration/calibrate.py`（必要なら `charuco_board.py` も）
   - 依存導入: `numpy`、ArUco 対応 OpenCV、（ライブ時）`picamera2`
   - ボード準備: 印刷済み Charuco ボード

   例（Pi 上で依存を入れる）:

   ```bash
   pip install -r requirements.txt
   ```

   実行後の JSON は Pi ローカルに保存されるため、ホストで使う場合は回収します。
   例:

   ```bash
   scp pi@<PI_IP>:/home/<PI_USER>/Loutrack2/calibration/calibration_intrinsics_v1_<camera_id>.json ./calibration/
   ```

1. **ボードを生成して印刷する**

   ```bash
   python src/camera-calibration/charuco_board.py \
     --output "./calibration/boards/charuco_6x8_30mm_a4.pdf" \
     --write-metadata
   ```

   - 印刷は 100% スケール（fit-to-page 無効）
   - 印刷後に 1 マスの辺長を実測し、`--square-length-mm` に使う

2. **撮影モードを選ぶ**

   - Raspberry Pi カメラでその場で撮る: ライブ撮影モード
   - 既存画像から較正する: オフラインモード

3. **ライブ撮影でフレームを収集する（Pi Camera）**

   ```bash
   python src/camera-calibration/calibrate.py \
     --camera pi-cam-01 \
     --square-length-mm <MEASURED_MM> \
     --min-frames 25 \
     --output "./calibration/calibration_intrinsics_v1_pi-cam-01.json"
   ```

   - `SPACE`: 有効に見えるフレームを取り込む
   - `C`: 較正実行（`--min-frames` 以上で有効）
   - `Q`: 終了
   - 中央/四隅、近距離/遠距離、角度違いを混ぜて収集する

4. **オフライン画像から較正する**

   ```bash
   python src/camera-calibration/calibrate.py \
     --camera pi-cam-01 \
     --square-length-mm <MEASURED_MM> \
     --input-dir "./calibration/images/pi-cam-01" \
     --min-frames 25 \
     --output "./calibration/calibration_intrinsics_v1_pi-cam-01.json"
   ```

   - 画像枚数ではなく「有効フレーム数」が `--min-frames` 以上必要
   - 見切れ画像は、コーナーが十分検出されるなら使用可

5. **結果を確認する**

   - 出力 JSON: `calibration/calibration_intrinsics_v1_<camera_id>.json`
   - 目安: `rms_error < 1.0 px`（理想は `< 0.5 px`）
   - `per_view_errors` に極端な値がある場合は、ブレ・反射・印刷スケールを再確認する

6. **必要なら再撮影・再較正する**

   - 有効フレーム数を増やす（例: 25 -> 35）
   - 画面周辺でのフレーム比率を増やす
   - ピントや露出を調整してから再実行する

## 補足

- メインの追跡パイプラインはヘッドレス実行できますが、ライブ較正は OpenCV の表示ウィンドウが必要です。
- `--marker-length-mm` 未指定時は `square_length_mm * 20/30` が使われます。
- `calibrate.py` では OpenCV ArUco API のバージョン差分を吸収する互換処理を入れています。

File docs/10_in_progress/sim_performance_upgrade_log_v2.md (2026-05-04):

# Sim Performance Upgrade Log V2

この文書は、`tools/sim/` で body-mounted scenario の精度・性能最適化 PDCA をやり直すための実験前提と判断基準を定義する。過去の探索履歴は `docs/10_in_progress/sim_performance_upgrade_log.md` に残す。

## V2 の目的

V2 の大ゴールは2つだけにする。

- sim 上の rigid body 推定 pose が GT の実位置・実姿勢に近いこと
- その精度を保ったまま、118fps の処理予算に収まること

`wrong_ownership_count`、`marker_source_confusion_count`、valid ratio、pose jump は主目的ではなく guardrail として扱う。速度だけ良い変更は採用候補にしない。sim fidelity が怪しい場合は tracker を最適化せず、まず観測モデルを実運用へ寄せる。

## 実験前提

主 scenario は `five_rigid_body_occlusion_v1`。random false blob で gate を最適化するのではなく、体による片側遮蔽、座り気味 waist、足交差、camera ごとの true blob size 差を見る。

固定する前提:

- `--scenario five_rigid_body_occlusion_v1`
- `--frames 240` 以上
- `--fps 118`
- `--camera-rig-source auto`
- `--rigid-stabilization-profile gui_live`
- `--false-blobs-per-camera 0`
- `--noise-px 0.05` / `0.10` を green candidate
- `--noise-px 0.15` を seed repeat caution
- `--noise-px 0.20` / `0.25` を robustness red boundary

`camera_rig_source=auto` は body-mounted 系 scenario では `cube_top_2_4m_aim_center` に解決される。camera は 2.4m cube 上面4隅に配置し、cube center を aim する。これは平行4cameraより実装着の囲い込みに近いが、full body mesh や実カメラ姿勢の完全再現ではない。

`five_rigid_body_occlusion_v1` は実ログ寄りの camera-specific true blob area を出す。

- `pi-cam-01` / `pi-cam-03` 相当は大きい blob
- `pi-cam-02` / `pi-cam-04` 相当は等価 diameter 約 4px 前後の小さい blob
- body-mounted scenario では camera ごとの初期 body depth 中央値を基準に、近い marker ほど等価 diameter を緩やかに増やす
- random false blob は追加しない

このため、`object_gating_pixel_max_px` の sweep は「false blob を消す最適化」ではない。予測投影と true blob centroid の距離 tail をどこまで許容するかを見る robustness 実験として扱う。

V2 baseline は GUI 正式経路と同じ意味を持つ `gui_live` profile にする。

- `pipeline_variant`: `fast_ABCDHRF`
- `subset_diagnostics_mode`: `off`
- `object_conditioned_gating`: enabled
- `object_gating_enforced`: true
- `object_gating_pixel_max_px`: `4.5`
- `pose_continuity_guard`: enabled / enforced
- `position_continuity_guard`: enabled / enforced
- `reacquire_guard_enforced`: true
- `reacquire_guard_shadow_enabled`: false
- `reacquire_guard_event_logging`: false

読み方:

- `fast_ABCDHRF` は object-gated fast path、rigid hint geometry、rigid candidate separation、subset budget、geometry hotpath を束ねた GUI live variant。
- `subset_diagnostics_mode=off` は subset 仮説探索を回さず、object gating / rigid hint / continuity guard を主経路にする設定。
- `object_conditioned_gating` は予測 pose から marker を 2D 投影し、近い blob だけを候補にする。
- `object_gating_enforced` は gating 結果を診断ではなく pose 選択に使う。
- `pixel max 4.5px` は gate 上限であり、blob size filter ではない。
- `pose_continuity_guard` は遮蔽時の回転ジャンプや identity flip を抑える。
- `position_continuity_guard` は遮蔽時の位置ジャンプを速度・加速度制約で抑える。
- `reacquire_guard` は LOST / REACQUIRE 復帰候補の 2D score と prediction innovation を検査する。

## 判断ルール

PDCA は既定順路を持たない。各 cycle の結果を読んで、次に解く blocker を選ぶ。

- pose error / identity safety が red なら、性能最適化へ進まない。
- sim の blob size、merge、reject、centroid shift が実運用とズレているなら、tracker tuning より sim fidelity を優先する。
- 同一 rigid 内 marker confusion は、pose error が小さい場合は即 fail ではなく fragility diagnostic として読む。ただし別 rigid wrong owner は強い red flag とする。
- performance は startup spike ではなく sustained 118fps budget で見る。
- continuity guard off は上限性能の ablation に限り、GUI default 採用候補にはしない。

主に見る指標:

- pose accuracy: `position_error_m`、`rotation_error_deg`、`position_delta_error_m`、`rotation_delta_error_deg`
- identity safety: `wrong_ownership_count`、`marker_source_confusion_count`、`valid_frame_ratio`
- sim fidelity: `blob_area_summary.by_camera`、近接 blob の merge / reject / centroid shift
- performance: `pipeline_pair_ms`、`rigid_ms`、`geometry_ms`、118fps over-budget run length

## 実験候補

候補は順番ではなく棚として扱う。

- seed repeat と noise boundary で、green candidate と red boundary を測る。
- close marker が実機で merge / circularity reject / centroid shift する条件を sim に入れる。
- object gating assigned distance と reprojection error の分布を summary に集約する。
- correctness が green になってから、warmup-trimmed performance と stage breakdown を見る。
- gate sweep は boundary の読み取り後に限定し、false blob 排除の自己最適化として扱わない。

## Baseline command

```bash
PYTHONPATH=src .venv/bin/python -m tools.sim \
  --scenario five_rigid_body_occlusion_v1 \
  --frames 240 \
  --fps 118 \
  --rigid-stabilization-profile gui_live \
  --noise-px 0.25 \
  --false-blobs-per-camera 0 \
  --seed 45 \
  --out logs/sim/five_rigid_body_occlusion_v1/v2_baseline_gui_live
```

`summary.json` で最低限見る項目:

- `camera_rig_source` が `cube_top_2_4m_aim_center`
- `wrong_ownership_count`
- `marker_source_confusion_count`
- `valid_frame_ratio`
- `position_delta_error_m`
- `rotation_delta_error_deg`
- `pipeline_pair_ms`
- `rigid_ms`
- `geometry_ms`
- `blob_area_summary.by_camera`
- `variant_metrics`
- `tracking.*.object_gating`
- `tracking.*.pose_continuity_guard`
- `tracking.*.position_continuity_guard`
- `tracking.*.reacquire_guard`

## PDCA 記録フォーマット

PDCA は完全に逐次で回す。次の cycle は前 cycle の結果を読んでから決める。

各 cycle に必ず残す:

- baseline または前 cycle との差分
- hypothesis
- command
- result
- decision
- next action

表の列:

| cycle | change | hypothesis | correctness | performance | read | decision | next |
|---|---|---|---|---|---|---|---|

`correctness` には最低限 `wrong/confusion/jump/min valid` を入れる。
`performance` には warmup-trimmed 指標が入るまでは `pair p95 / rigid p95 / geometry p95` と startup spike 有無を併記する。

## 補助実装

測定の信用度を上げるために入れる価値が高い実装:

- sim summary に warmup-trimmed performance を追加する
- object gating assigned distance の summary を scenario summary に集約する
- PDCA row を自動で `json` / `md` に追記する薄い helper を用意する

この3つが揃うと、最適化対象を触る前に「改善に見えるノイズ」をかなり減らせる。

## V2 Restart PDCA 1-10

距離追従blob径を入れた状態で、PDCA を cycle 1 からやり直した。過去の V2 PDCA 表はこの節に置き換えた。

共通条件:

- scenario: `five_rigid_body_occlusion_v1`
- frames / fps: `240` / `118`
- camera rig: `auto` resolved to `cube_top_2_4m_aim_center`
- camera ids: `pi-cam-01` / `pi-cam-02` / `pi-cam-03` / `pi-cam-04`
- rigid set: `head` / `waist` / `chest` / `left_foot` / `right_foot`
- runtime profile: `gui_live`
- random false blobs: `0`
- logs: `logs/sim/five_rigid_body_occlusion_v1/20260501_v2_restart_pdca10/`

共通 command:

```bash
PYTHONPATH=src .venv/bin/python -c 'from tools.sim.multi_rigid import DEFAULT_BODY_RIGIDS, DEFAULT_GENERATED_CAMERA_IDS, MultiRigidScenarioConfig, run_multi_rigid_scenario; ...'
```

Baseline: seed `45` / noise `0.25px` は clean ではなかった。wrong/confusion は `1/8`、min valid は `0.825`、left_foot valid は `0.825`。pair/rigid/geometry p95 は `4.75/1.94/1.74ms`。blob diameter p95 は `pi-cam-01 11.43px`、`pi-cam-02 4.91px`、`pi-cam-03 12.10px`、`pi-cam-04 4.55px`。failure は frame `72` left_foot 0/2、frame `114-115` waist 0/1、frame `199` left_foot/waist wrong owner、frame `215` right_foot 0/3。

| cycle | change | hypothesis | correctness | performance | read | decision | next |
|---|---|---|---|---|---|---|---|
| 1 | seed `45`, noise `0.15px` | `0.25px` red が centroid jitter由来なら、低noiseでは clean に戻る。 | wrong/confusion `0/0`、min valid `0.996`。 | pair/rigid/geometry p95 `4.49/1.70/1.69ms`、fallback `0`。 | `0.15px` は seed 45 では clean。 | `0.25px` はgreen baselineから外す。 | `0.20px` で red 境界を確認する。 |
| 2 | seed `45`, noise `0.20px` | `0.15` と `0.25` の間に marker confusion 境界がある。 | wrong/confusion `0/6`、min valid `1.000`。 | `4.51/1.72/1.69ms`、fallback `0`。 | valid は保つが frame `72`, `114`, `115` で marker入れ替わり。 | `0.20px` は red。 | 中点 `0.175px` を測る。 |
| 3 | seed `45`, noise `0.175px` | `0.20px` と同じ箇所が出るなら境界は `0.15` 近傍。 | wrong/confusion `0/6`、min valid `0.996`。 | `4.50/1.66/1.79ms`、fallback `0`。 | `0.20px` と同じ left_foot / waist confusion。 | `0.175px` も red。 | `0.1625px` を測る。 |
| 4 | seed `45`, noise `0.1625px` | `0.175px` から下げると waist側は消え、最小近接だけ残る可能性がある。 | wrong/confusion `0/2`、min valid `0.996`。 | `4.48/1.77/1.67ms`、fallback `0`。 | frame `72`、`pi-cam-04`、left_foot 0/2 だけ残る。 | 残る failure は単純なnoise量ではなく近接投影。 | `0.15625px` を測る。 |
| 5 | seed `45`, noise `0.15625px` | clean 上限が `0.15` より少し上にあるか確認する。 | wrong/confusion `0/2`、min valid `0.996`。 | `4.39/1.75/1.69ms`、fallback `0`。 | left_foot 0/2 がまだ残る。 | seed45のclean上限は `0.15` と `0.15625` の間。 | `0.153125px` を測る。 |
| 6 | seed `45`, noise `0.153125px` | 前回境界と同様に `0.153125px` は red か確認する。 | wrong/confusion `0/2`、min valid `0.996`。 | `4.40/1.77/1.67ms`、fallback `0`。 | `0.153125px` でも left_foot 0/2 confusion。 | seed45の暫定greenは `0.15px` まで。 | seed repeat で `0.15px` が信頼できるか確認する。 |
| 7 | seed `46`, noise `0.15px` | seed45だけの偶然cleanでなければ seed46 も clean になる。 | wrong/confusion `1/1`、min valid `0.829`。 | `4.49/1.82/1.66ms`、fallback `60`。 | frame `59` chest confusion と frame `199` left_foot/waist wrong owner。 | `0.15px` は seed repeat green ではない。 | seed46で noise を下げる。 |
| 8 | seed `46`, noise `0.10px` | `0.15px` が少し強すぎるだけなら `0.10px` で clean になる。 | wrong/confusion `1/0`、min valid `0.829`。 | `11.80/5.33/3.61ms`、fallback `59`。 | frame `199` の left_foot/waist wrong owner が残る。性能値はこのrunだけ外乱大。 | `0.10px` も seed46 ではまだ red。 | noiseなしでscenario幾何自体を確認する。 |
| 9 | seed `46`, noise `0.0px` | noiseなしでも壊れるなら scenario visibility が不成立。 | wrong/confusion `0/0`、min valid `1.000`。 | `4.40/1.70/1.77ms`、fallback `0`。 | geometry単体は clean。wrong owner はjitterで近接姿勢を踏むため。 | 観測ノイズと近接投影の相互作用が主因。 | seed46の green 下限として `0.05px` を測る。 |
| 10 | seed `46`, noise `0.05px` | `0.05px` なら seed46でも clean に戻る。 | wrong/confusion `0/0`、min valid `1.000`。 | `4.41/1.86/1.63ms`、fallback `0`。 | seed46では `0.05px` が clean。 | 現時点のseed repeat green candidate は `0.05px`。 | 次は seed `47` / `0.05px`、その後に close-marker observation model を設計する。 |

結論: 距離追従blob径を入れた後も、`0.25px` は red boundary のまま。seed `45` では `0.15px` が clean だが、seed `46` では `0.15px` も `0.10px` も frame `199` の left_foot/waist wrong owner で崩れる。noise `0.0px` と `0.05px` は seed `46` で clean なので、scenario geometry 単体ではなく、近接投影姿勢と centroid jitter の組み合わせが問題。次の blocker は gate tuning ではなく、近接 marker が別々のclean blobとして残る現在の observation model を、実機の contour merge / circularity reject に寄せること。

## V2 Follow-up PDCA 11-20

cycle 10 の next action から完全逐次で続けた。採否判断に使ったログは `logs/sim/five_rigid_body_occlusion_v1/20260501_v2_pdca11_20/` に残す。

追加した測定補助:

- `summary.json` の `performance_budget.warmup_trimmed` に、先頭30 processed pairsを上限にした warmup-trimmed `pipeline_pair_ms` / `rigid_ms` / `geometry_ms` を追加した。
- `five_rigid_body_occlusion_v1` に optional な `--body-mount-blob-merge-factor` を追加した。既定は `0.0` で既存 scenario は変えない。

| cycle | change | hypothesis | correctness | performance | read | decision | next |
|---|---|---|---|---|---|---|---|
| 11 | seed `47`, noise `0.05px` | seed repeat でも `0.05px` が clean なら green candidate に近い。 | wrong/confusion `0/0`、min valid `1.000`。 | pair/rigid/geometry p95 `4.22/1.58/1.57ms`、over max run `2`。 | correctness は clean だが production は rigid p95 と over run で落ちる。 | performance の読みが startup / 外乱混じり。 | warmup-trimmed summary を入れる。 |
| 12 | warmup-trimmed summary追加、seed `47`, noise `0.05px` repeat | sustained 指標なら startup spike と通常負荷を分けられる。 | wrong/confusion `0/0`、min valid `1.000`。 | trimmed pair/rigid/geometry p95 `12.91/3.43/4.16ms`、trimmed over max run `9`。 | この run は warmup 後も外乱が大きく、採否判断に不適。 | 同条件 repeat で再現性を見る。 | seed `47` / `0.05px` を再測。 |
| 13 | seed `47`, noise `0.05px` repeat | cycle 12 が外乱なら通常値へ戻る。 | wrong/confusion `0/0`、min valid `1.000`。 | trimmed p95 `3.98/1.51/1.38ms`、trimmed over max run `0`。 | cycle 12 の大跳ねは再現せず。rigid p95 は僅かに閾値超え。 | correctness green、性能は境界上。 | gateを狭めて workload が減るか確認。 |
| 14 | seed `47`, noise `0.05px`, gate `4.0px` | 狭い gate で候補が減り rigid p95 が改善する。 | wrong/confusion `0/0`、min valid `1.000`。 | trimmed p95 `24.02/9.56/8.92ms`、trimmed over max run `106`。 | gate `4.0px` はこの run で sustained に悪化。 | 採用しない。gate定数最適化へ進まない。 | 近接 blob model を直接測る。 |
| 15 | merge factor `0.45`, seed `47`, noise `0.05px` | 近接 true blobs を merged contour にすると spurious marker confusion を減らせる。 | wrong/confusion `0/0`、min valid `0.825`、merge `150`。 | trimmed p95 `5.06/1.97/1.63ms`、trimmed over max run `1`。 | merge が強すぎ、left_foot と waist の valid を落とす。 | factor `0.45` は不採用。 | factor を下げる。 |
| 16 | merge factor `0.35`, seed `47`, noise `0.05px` | 明確な重なりだけに絞れば valid を戻せる。 | wrong/confusion `0/0`、min valid `0.825`、merge `77`。 | trimmed p95 `4.05/1.55/1.34ms`、trimmed over max run `0`。 | merge 件数は半減したが left_foot valid は戻らない。 | factor `0.35` も不採用。 | さらに factor を下げる。 |
| 17 | merge factor `0.25`, seed `47`, noise `0.05px` | ごく近い contour merge だけなら clean valid を維持できる。 | wrong/confusion `0/0`、min valid `0.829`、merge `30`。 | trimmed p95 `3.95/1.54/1.37ms`、trimmed over max run `1`。 | 少数 merge でも left_foot valid が落ちる。 | default merge 採用はしない。 | 以前 red だった seed46/noise0.10 で効用を見る。 |
| 18 | merge factor `0.25`, seed `46`, noise `0.10px` | merge が frame `199` の wrong owner を消せるなら診断価値はある。 | wrong/confusion `0/0`、min valid `0.829`、merge `27`。 | trimmed p95 `3.93/1.47/1.36ms`、trimmed over max run `1`。 | wrong owner は消えるが min valid は red のまま。 | merge は optional 診断 knob に留める。 | 既定を no-merge に戻して regression 確認。 |
| 19 | default no merge、seed `47`, noise `0.05px` | optional化後も既定 scenario は clean のまま。 | wrong/confusion `0/0`、min valid `1.000`、merge `0`。 | trimmed p95 `4.14/1.52/1.41ms`、trimmed over max run `0`。 | 既定 correctness は維持。rigid p95 はまだ境界上。 | merge既定採用なし。 | upper-bound ablation として position guard off。 |
| 20 | seed `47`, noise `0.05px`, position continuity guard off | guard cost が閾値超えの主因なら p95 が下がる。 | wrong/confusion `0/0`、min valid `1.000`。 | trimmed p95 `4.05/1.48/1.38ms`、trimmed over max run `0`。 | trimmed rigid p95 は閾値内に入るが、raw rigid p95 は `1.51ms`。guard off は GUI default 採用候補ではない。 | 本体採用なし。測定補助と optional merge knob だけ残す。 | 次は merged/low-marker 区間の valid hold か、rigid stage breakdown をさらに分ける。 |

結論: 追加10周では、GUI default として採用できる精度・性能改善は見つからなかった。`0.05px` は seed `47` でも clean だが、rigid p95 は境界上。近接 blob merge は seed `46` / `0.10px` の wrong owner を消せる一方で、seed `47` / `0.05px` の left_foot valid を `0.83` 前後まで落とすため既定採用しない。残す改善は、warmup-trimmed performance summary と optional merge knob による診断性向上。次の blocker は tracker tuning ではなく、merged / low-marker 区間での valid hold と rigid stage breakdown の切り分け。

## Relaxed Body-Mounted PDCA 1-10

`five_rigid_body_occlusion_v1` は hard fixture として残し、少し緩い兄弟 scenario `five_rigid_body_occlusion_relaxed_v1` を追加した。camera rig、body motion、camera-specific blob area は同じ系統のまま、feet の遮蔽 camera 数と waist/head の遮蔽時間を少し減らす。採否判断に使ったログは `logs/sim/five_rigid_body_occlusion_relaxed_v1/20260502_relaxed_pdca10/` に残す。

Baseline: seed `47` / noise `0.05px` は correctness clean。wrong/confusion `0/0`、min valid `1.000`、trimmed pair/rigid/geometry p95 `4.44/1.69/1.61ms`。scenario は production rigid p95 で fail。

| cycle | change | hypothesis | correctness | performance | read | decision | next |
|---|---|---|---|---|---|---|---|
| 1 | seed `47`, noise `0.10px` | 少し緩めれば `0.10px` まで green に近づく。 | wrong/confusion `1/2`、min valid `0.829`、frames `68,199`。 | trimmed p95 `3.96/1.44/1.37ms`、over max run `2`。 | frame `199` wrong owner と frame `68` confusion が残る。 | `0.10px` はまだ red。 | 中間 `0.075px` を測る。 |
| 2 | seed `47`, noise `0.075px` | red 境界は `0.075` 付近に下がる。 | wrong/confusion `0/2`、min valid `1.000`、frame `68`。 | trimmed p95 `3.89/1.44/1.36ms`、over `0`。 | wrong と valid は戻るが marker confusion が残る。 | correctness green とは言わない。 | `0.0625px` を測る。 |
| 3 | seed `47`, noise `0.0625px` | `0.0625px` なら clean になる。 | wrong/confusion `0/0`、min valid `1.000`。 | trimmed p95 `5.45/2.05/1.95ms`、over `1`。 | correctness は clean、性能は重い外乱の可能性。 | 同条件 repeat。 | `0.0625px` repeat。 |
| 4 | seed `47`, noise `0.0625px` repeat | cycle 3 の性能値が外乱なら戻る。 | wrong/confusion `0/0`、min valid `1.000`。 | trimmed p95 `4.46/1.74/1.53ms`、over `0`。 | correctness は再現。rigid p95 はまだ境界外。 | seed repeat へ進む。 | seed `46` / `0.0625px`。 |
| 5 | seed `46`, noise `0.0625px` | seed repeat でも `0.0625px` が clean なら relaxed green候補。 | wrong/confusion `0/2`、min valid `0.996`、frame `73`。 | trimmed p95 `4.19/1.61/1.47ms`、over `0`。 | seed46では marker confusion が出る。 | seed-repeat green は `0.0625px` では成立しない。 | seed46を `0.05px` へ戻す。 |
| 6 | seed `46`, noise `0.05px` | `0.05px` なら seed46も clean に戻る。 | wrong/confusion `0/0`、min valid `1.000`。 | trimmed p95 `4.35/1.68/1.64ms`、over `0`。 | correctness clean。 | `0.05px` を seed repeat候補に戻す。 | seed45 / `0.05px`。 |
| 7 | seed `45`, noise `0.05px` | 3 seed repeat で `0.05px` が clean になる。 | wrong/confusion `0/0`、min valid `1.000`。 | trimmed p95 `4.42/1.59/1.57ms`、over `0`。 | seed45/46/47 は correctness clean。 | relaxed green correctness は `0.05px`。 | 性能 ablation を見る。 |
| 8 | seed `47`, noise `0.05px`, position guard off | position guard cost が rigid p95 超えの主因なら改善する。 | wrong/confusion `0/0`、min valid `1.000`。 | trimmed p95 `4.46/1.59/1.65ms`、over `0`。 | guard off でも大きく改善しない。 | safety guard off は採用しない。 | gate `5.0px` を確認。 |
| 9 | seed `47`, noise `0.05px`, gate `5.0px` | 少し広い gate で candidate churn が減る可能性がある。 | wrong/confusion `0/0`、min valid `1.000`。 | trimmed p95 `4.29/1.67/1.56ms`、over `0`。 | correctness は維持するが rigid p95 は改善しない。 | gate変更は採用しない。 | 長め repeat で sustained を確認。 |
| 10 | seed `47`, noise `0.05px`, `480` frames | green候補が長め run でも clean か確認する。 | wrong/confusion `0/0`、min valid `1.000`。 | raw p95 `4.17/1.47/1.45ms`、trimmed p95 `4.21/1.53/1.47ms`、over `0`。 | correctness は長めでも clean。performance は raw rigid p95 はpass、trimmed rigid p95は僅かに境界外。 | relaxed scenario は green-regression 入口として採用候補。 | 次は production判定を raw/trimmed/repeat で再定義するか、rigid stage breakdown を切る。 |

結論: scenario を若干緩めた効果はあった。`noise 0.05px` は seed `45/46/47` で wrong/confusion `0/0`、min valid `1.000` になり、hard scenario より green regression として扱いやすい。一方で `noise 0.0625px` は seed46で marker confusion、`0.075px` は seed47で marker confusion、`0.10px` は wrong owner と valid drop が出るため、green 条件にはしない。性能は relaxed scenario でも rigid p95 が境界上で、guard off / gate `5.0px` は採用できる改善ではなかった。

## Relaxed Algorithm PDCA 1-10

`five_rigid_body_occlusion_relaxed_v1` の boundary failure を使い、rigid / object-gating 側の最初の最適化に入った。採否判断に使ったログは `logs/sim/five_rigid_body_occlusion_relaxed_v1/20260502_algo_pdca10/` に残す。

狙った failure:

- frame `68`: seed `47`, noise `0.075px`, `right_foot` marker `0/1` が `pi-cam-04` で swap。
- frame `73`: seed `46`, noise `0.0625px`, `head` marker `3/4` が `pi-cam-01` で swap。
- frame `199`: seed `47`, noise `0.10px`, `waist:1` が `pi-cam-04` で `left_foot:0` を拾う。

変更の方向:

- object-gating の assignment 後、割当 blob が同一 camera 内の別 blob と sub-pixel 近接している場合、その assignment を曖昧として triangulation 入力から外す。
- 近接判定は default `0.60px`。`0.50px` は frame `199` を取り逃がし、`0.75px` は correctness は良いが余分に重く出やすかった。
- 最後に距離判定を vectorized にして、pair p95 の悪化を戻した。

| cycle | change | hypothesis | correctness | performance | read | decision | next |
|---|---|---|---|---|---|---|---|
| 1 | assigned-assigned 近接 drop `0.75px`, seed `47`, noise `0.075px` | 同一rigid marker swap は近接 assignment を落とせば消える。 | wrong/confusion `0/0`、min valid `1.000`。 | trimmed p95 `5.08/1.80/1.65ms`、over `1`。 | frame `68` の right_foot swap は消えた。 | 方向性は有効。 | seed46の head swap を測る。 |
| 2 | same change, seed `46`, noise `0.0625px` | head `3/4` swap も同じ近接条件で消える。 | wrong/confusion `0/0`、min valid `0.996`。 | trimmed p95 `4.64/1.67/1.56ms`、over `0`。 | marker confusion は消え、valid は既存と同等。 | 同一rigid swap対策は有効。 | red wrong owner に進む。 |
| 3 | same change, seed `47`, noise `0.10px` | assigned-assigned drop だけで cross-rigid wrong owner も減る可能性。 | wrong/confusion `1/0`、min valid `0.829`、frame `199`。 | trimmed p95 `5.56/2.00/1.68ms`、over `2`。 | marker confusion は消えるが waist/left_foot wrong owner は残る。 | cross-rigid 近接には不十分。 | assigned blob の近傍に unassigned blob がある場合も落とす。 |
| 4 | assigned-near-any drop `0.75px`, seed `47`, noise `0.10px` | assigned blob の隣に別 blob があるなら contour-level ambiguity として捨てる。 | wrong/confusion `0/0`、min valid `1.000`。 | trimmed p95 `6.80/1.41/1.37ms`、over `0`。 | frame `199` wrong owner と valid drop が消えた。 | correctness は大幅改善。 | 同条件 repeat で性能を見る。 |
| 5 | same change repeat | cycle 4 の性能が安定するか確認。 | wrong/confusion `0/0`、min valid `1.000`。 | trimmed p95 `8.79/2.11/1.98ms`、over `6`。 | correctness は再現するが、`0.75px` は重く出やすい。 | threshold を絞る。 | `0.60px` を測る。 |
| 6 | assigned-near-any drop `0.60px`, seed `47`, noise `0.10px` | `0.60px` でも frame `199` を防ぎつつ余分なdropを減らせる。 | wrong/confusion `0/0`、min valid `1.000`。 | trimmed p95 `6.91/1.50/1.37ms`、over `0`。 | correctness は維持、rigid p95 は改善。 | `0.60px` が候補。 | 下限 `0.50px` を確認。 |
| 7 | assigned-near-any drop `0.50px`, seed `47`, noise `0.10px` | さらに狭くしても同じ failure を防げるか確認。 | wrong/confusion `1/0`、min valid `0.829`、frame `199`。 | trimmed p95 `6.79/1.51/1.37ms`、over `2`。 | `0.50px` では cross-rigid近接を取り逃がす。 | 不採用。 | default を `0.60px` にする。 |
| 8 | default `0.60px`, seed `46`, noise `0.0625px` | default化後も seed46 boundary を守れる。 | wrong/confusion `0/0`、min valid `0.996`。 | trimmed p95 `7.14/1.65/1.63ms`、over `0`。 | correctness は維持。 | default `0.60px` は成立。 | seed47 red boundaryを測る。 |
| 9 | default `0.60px`, seed `47`, noise `0.10px` | overrideなしで red boundary が clean になる。 | wrong/confusion `0/0`、min valid `1.000`。 | trimmed p95 `7.82/1.71/1.58ms`、over `0`。 | correctness は改善したが pair p95 が重い。 | hotpath を軽くする。 | near-any距離判定をvectorize。 |
| 10 | vectorized near-any, default `0.60px`, seed `47`, noise `0.10px` | 同じ correctness のまま pair p95 を戻す。 | wrong/confusion `0/0`、min valid `1.000`。 | raw p95 `4.99/1.71/1.63ms`、trimmed p95 `4.91/1.71/1.62ms`、over `0`。 | correctness 改善は維持し、pair p95 は通常域に戻った。 | 採用候補。 | hard scenario と実ログ replay で過剰dropがないか確認する。 |

結論: rigid algorithm 側の最初の改善として、object-gating の sub-pixel ambiguous blob assignment drop は有効。relaxed boundary の seed `47` / noise `0.10px` は wrong/confusion `1/2`、min valid `0.829` から `0/0`、`1.000` まで改善した。seed `46` / noise `0.0625px` の head marker confusion も消えた。default threshold は `0.60px` がよく、`0.50px` は wrong owner を取り逃がし、`0.75px` は余分に重い。次の確認は hard scenario と実ログ replay で、近接 true blobs を落としすぎて valid を削らないかを見る。

## Ambiguous Blob Guard Adoption Check

PDCA 10 の採用候補を、hard scenario と実ログで追加確認した。sim logs は `logs/sim/five_rigid_body_occlusion_v1/20260502_ambiguous_guard_hard_check/`、実ログ replay は `logs/archive/ambiguous_guard_replay_20260502/` に残す。

Hard scenario matrix:

| noise | seed 45 | seed 46 | seed 47 | read |
|---|---|---|---|---|
| `0.05px` | wrong/confusion `0/0`, min valid `1.000`, pair/rigid/geometry p95 `4.61/1.49/1.40ms` | `0/0`, `1.000`, `4.56/1.50/1.38ms` | `0/0`, `1.000`, `4.43/1.49/1.34ms` | clean。 |
| `0.10px` | `0/2`, `1.000`, `4.44/1.49/1.36ms` | `0/0`, `0.996`, `4.58/1.55/1.36ms` | `0/0`, `1.000`, `4.44/1.48/1.35ms` | wrong owner は出ないが、seed45 head marker `3/4` confusion が1 frame残る。 |
| `0.15px` | `0/0`, `0.996`, `4.45/1.51/1.35ms` | `0/1`, `0.996`, `4.61/1.51/1.36ms` | `0/0`, `1.000`, `4.45/1.50/1.36ms` | high-noise boundaryでは chest marker confusion が1件残る。 |

Hard scenario の結論: guard は hard side でも wrong owner を増やさず、`0.05px` の green repeat は維持した。一方で `0.10-0.15px` の high-noise marker confusion を完全には消さない。これは「採用してよいが、hard noise boundary を完全解決したとは言わない」という扱いにする。

実ログ確認:

- `logs/tracking_gui.jsonl` は camera が `pi-cam-01` / `pi-cam-02` の waist中心ログで、埋め込み diagnostics は `108` events / `108.26s`。
- diagnostics summary では waist valid ratio `0.574`、failure は主に accepted points不足、pose jump/flip。これは今回の close-blob guard とは別軸の低観測数問題。
- 5 rigid 全部で replay すると、ログ内容にない head/chest/feet が常時 invalid になり、判断材料として不適だった。
- waist-only replay で guard OFF (`0.0px`) と default (`0.60px`) を比較した。

| replay | frames processed | poses estimated | reacquire | max jump / flip | object gating | pair/rigid p95 | read |
|---|---:|---:|---:|---|---|---|---|
| OFF `0.0px` | `12594` | `7794` | `145` | `0.618m` / `174.44deg` | assigned views `7/8`, evaluated `1` | `18.86/18.09ms` | baseline。 |
| default `0.60px` | `12594` | `7794` | `145` | `0.618m` / `174.44deg` | assigned views `7/8`, evaluated `1` | `17.99/17.26ms` | behavior悪化なし。 |

実ログの結論: この waist実ログでは close-blob ambiguity がほぼ発火せず、default `0.60px` は valid / reacquire / jump / flip を悪化させなかった。性能は同等から僅かに軽いが、実ログ replay の p95 自体は高く、今回の guard とは別に低観測数・reacquire 多発ログとして扱う。

採用判断: `ObjectGatingConfig.ambiguous_blob_min_separation_px = 0.60` を GUI/live default 候補として維持する。次はアルゴリズムをさらに触る前に、hard high-noise marker confusion の残件を「pose側で吸収するべきか、観測品質として棄却するべきか」に分ける。
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

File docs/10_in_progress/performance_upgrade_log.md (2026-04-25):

# トラッキング性能改善ログ

## 2026-04-26 GUI正式経路を`fast_ABCDHRF`に変更

### 判断

- archive baseline の `max_pose_flip_deg` 差は 177.8056 -> 177.8137 の 0.008度で、実運用上は無視可能と判断。
- GUI経由のlive trackingでは、32 blobs/cam 118fps安定運用を優先し、`fast_ABCDHRF` を正式経路に採用する。
- live表示では committed pose に使っていない subset diagnostics を hot path から外し、`subset_diagnostics_mode=off` を既定にする。

### 実装

- `src/host/tracking_runtime.py`
  - GUI runtime の `TrackingPipeline` 起動時に `pipeline_variant="fast_ABCDHRF"` を明示。
  - `subset_diagnostics_mode="off"` を明示。
- replay CLI と直接 `TrackingPipeline()` の既定は比較・rollback 用に維持する。

### 期待値

- current実ログ:
  - `pipeline_pair_ms.p95`: 5.092 ms -> 2.768 ms。
  - `pipeline_pair_ms.max`: 8.660 ms -> 2.977 ms。
- archive baseline:
  - `pipeline_pair_ms.p95`: 5.490 ms -> 2.814 ms。
  - `pipeline_pair_ms.max`: 35.099 ms -> 3.160 ms。
- archive new:
  - `pipeline_pair_ms.p95`: 5.472 ms -> 3.382 ms。
  - `pipeline_pair_ms.max`: 32.141 ms -> 3.928 ms。

## 2026-04-26 `fast_ABCDHRF` 実ログ replay AB

### 目的

- 32 blobs/cam synthetic stress で採択候補になった `fast_ABCDHRF` を、実ログ3本で `fast_ABCD` と比較する。
- 比較対象:
  - `fast_ABCD`: 現正式経路。
  - `fast_ABCDHRF`: hint-only geometry + marker-index direct Kabsch + geo hot-path optimization、subset sampled。
  - `fast_ABCDHRF` + `subset_diagnostics_mode=off`: live表示想定。
- strict gate:
  - valid frames 非悪化。
  - reacquire / pose jumps / mode transitions / max flip 非悪化。
  - reprojection p95 5%以内。
  - `pipeline_pair_ms.p95` と `rigid_ms.p95` 改善。

### current log: `logs/tracking_gui.jsonl`

- `fast_ABCD`
  - valid poses: 19,770。
  - `pipeline_pair_ms.p95`: 5.092 ms。
  - `pipeline_pair_ms.max`: 8.660 ms。
  - `rigid_ms.p95`: 1.780 ms。
  - `triangulation_ms.p95`: 2.739 ms。
  - fast path used: 3,650。
  - fallback: 20,750。
- `fast_ABCDHRF` sampled
  - valid poses: 19,773。
  - `pipeline_pair_ms.p95`: 3.005 ms、約 41.0%改善。
  - `pipeline_pair_ms.max`: 8.557 ms。
  - `rigid_ms.p95`: 1.216 ms。
  - `triangulation_ms.p95`: 1.350 ms。
  - fast path used: 19,316。
  - fallback: 5,084。
  - strict gate: pass。
- `fast_ABCDHRF` subset off
  - valid poses: 19,773。
  - `pipeline_pair_ms.p95`: 2.768 ms、約 45.6%改善。
  - `pipeline_pair_ms.max`: 2.977 ms。
  - `rigid_ms.p95`: 0.852 ms。
  - `triangulation_ms.p95`: 1.260 ms。
  - strict gate: pass。

### archive baseline log: `logs/archive/rigid_stabilization_pdca_20260425_042805/tracking_gui_baseline.jsonl`

- `fast_ABCD`
  - valid poses: 13,644。
  - `pipeline_pair_ms.p95`: 5.490 ms。
  - `pipeline_pair_ms.max`: 35.099 ms。
  - `rigid_ms.p95`: 1.081 ms。
  - `triangulation_ms.p95`: 3.843 ms。
  - fast path used: 13,230。
  - fallback: 1,996。
- `fast_ABCDHRF` sampled
  - valid poses: 13,649。
  - `pipeline_pair_ms.p95`: 3.128 ms、約 43.0%改善。
  - `pipeline_pair_ms.max`: 9.059 ms。
  - `rigid_ms.p95`: 1.106 ms。
  - fast path used: 13,487。
  - fallback: 1,739。
  - strict gate: fail。
    - `rigid_ms.p95` がわずかに悪化。
    - `max_pose_flip_deg` が 177.8056 -> 177.8137 と 0.008度だけ増加。
- `fast_ABCDHRF` subset off
  - valid poses: 13,649。
  - `pipeline_pair_ms.p95`: 2.814 ms、約 48.7%改善。
  - `pipeline_pair_ms.max`: 3.160 ms。
  - `rigid_ms.p95`: 0.826 ms。
  - strict gate: fail。
    - speed gate は pass。
    - `max_pose_flip_deg` の微小増加により strict quality gate は fail。

### archive new log: `logs/archive/rigid_stabilization_new_tracking_20260425_043548/tracking_gui_new.jsonl`

- `fast_ABCD`
  - valid poses: 1,469。
  - `pipeline_pair_ms.p95`: 5.472 ms。
  - `pipeline_pair_ms.max`: 32.141 ms。
  - `rigid_ms.p95`: 1.518 ms。
  - `triangulation_ms.p95`: 3.735 ms。
  - fast path used: 1,315。
  - fallback: 321。
- `fast_ABCDHRF` sampled
  - valid poses: 1,469。
  - `pipeline_pair_ms.p95`: 3.421 ms、約 37.5%改善。
  - `pipeline_pair_ms.max`: 10.028 ms。
  - `rigid_ms.p95`: 1.250 ms。
  - fast path used: 1,374。
  - fallback: 262。
  - strict gate: pass。
- `fast_ABCDHRF` subset off
  - valid poses: 1,469。
  - `pipeline_pair_ms.p95`: 3.382 ms、約 38.2%改善。
  - `pipeline_pair_ms.max`: 3.928 ms。
  - `rigid_ms.p95`: 0.972 ms。
  - strict gate: pass。

### 判断

- `fast_ABCDHRF` は実ログでも速度面の効果が大きい。
  - current: p95 約 41-46%改善。
  - archive baseline: p95 約 43-49%改善。
  - archive new: p95 約 37-38%改善。
- `subset_diagnostics_mode=off` は live表示向けに最大遅延を強く抑える。
  - current max: 8.660 -> 2.977 ms。
  - archive baseline max: 35.099 -> 3.160 ms。
  - archive new max: 32.141 -> 3.928 ms。
- ただし正式置換はまだ保留。
  - archive baseline で `max_pose_flip_deg` が 0.008度だけ増え、厳格な「非悪化」判定では fail。
  - 実用上は微小差だが、現在の採択基準では quality gate を全ログ通過していない。
- 次の推奨:
  - `fast_ABCDHRF + subset_diagnostics_mode=off` を live experimental flag として試す。
  - 置換判断では `max_pose_flip_deg` に数値誤差許容、たとえば 0.01度、を入れるかを明示的に決める。
  - fallback発生frameだけを抽出し、archive baseline の 0.008度差が実害のあるpose flipか、浮動小数点/候補順の微差かを確認する。

### 生成物

- `logs/archive/performance_upgrade_ab_20260426_real_current/fast_ABCD.json`
- `logs/archive/performance_upgrade_ab_20260426_real_current/fast_ABCDHRF_sampled.json`
- `logs/archive/performance_upgrade_ab_20260426_real_current/fast_ABCDHRF_off.json`
- `logs/archive/performance_upgrade_ab_20260426_real_archive_baseline/fast_ABCD.json`
- `logs/archive/performance_upgrade_ab_20260426_real_archive_baseline/fast_ABCDHRF_sampled.json`
- `logs/archive/performance_upgrade_ab_20260426_real_archive_baseline/fast_ABCDHRF_off.json`
- `logs/archive/performance_upgrade_ab_20260426_real_archive_new/fast_ABCD.json`
- `logs/archive/performance_upgrade_ab_20260426_real_archive_new/fast_ABCDHRF_sampled.json`
- `logs/archive/performance_upgrade_ab_20260426_real_archive_new/fast_ABCDHRF_off.json`

## 2026-04-26 32 blobs/cam 118fps目標 PDCA 3周

### 目標

- 32 blobs/cam、4 cameras、1 rigid body の synthetic stress で 118fps 安定運用を狙う。
- 118fps は 1 pair あたり約 8.47 ms 以下。
- 実ログは p95 4 blobs/cam 程度なので、32 blobs/cam は synthetic stress で評価する。
- 採択候補は、品質を落とさず `pipeline_pair_ms.p95` と最大遅延を下げられる経路。

### subagentsからの知見

- geometry探索では、32 blobs/cam で既存 `fast_ABCDP` pruning は候補削減率が高くても、full matrix 計算後の Python set/dict/component 分割が重く、32では不利と判断。
- 低リスク候補として次が挙がった。
  - 32では pruning を避け、64/128で再評価する。
  - `_refine_candidate_observation()` の no-drop 経路で triangulation / reprojection を二重計算しない。
  - forward epipolar gate を通った候補だけ backward distance を計算する。
  - 2-view triangulation に `cv.triangulatePoints()` fast path を入れる。
- benchmark helper として `tests/perf/synthetic_32_blob_benchmark.py` を追加し、32 blobs/cam の同一入力ABを再実行しやすくした。

### PDCA 1: rigid hint-only geometry

- 仮説:
  - object gating が成立している frame では、generic epipolar triangulation と rigid-hint triangulation の二重計算が無駄。
  - rigid-hint triangulated points をそのまま本線 `points_3d` として使えば、generic epipolar matching を飛ばせる。
- 実装:
  - `fast_ABCDH`: object-gated filtered path で `use_rigid_hint_as_generic=True` を使う。
  - `src/host/geo.py` に observations だけを準備する `prepare_observations_for_paired_frames()` を追加。
  - hint-only時は `rigid_hint_triangulated_points` を `triangulated_points` / `points_3d` に流用する。
- 結果:
  - `fast_ABCD`: `pipeline_pair_ms.p95` 6.017 ms、max 35.241 ms。
  - `fast_ABCDH`: `pipeline_pair_ms.p95` 4.035 ms、max 9.782 ms。
  - p95 は約 33% 改善し、118fps p95目標を通過。
- 判断:
  - 採択候補。安定追跡中は generic epipolar を二重に回さない方針が有効。

### PDCA 2: geometry hot-path micro optimizations

- 仮説:
  - hint-only以外の fallback や generic path でも、triangulation/refinementの重複計算を削れば安定性が上がる。
- 実装:
  - `fast_ABCDF`: generic path 用 hot-path optimization。
  - `fast_ABCDHF`: hint-only + hot-path optimization。
  - `fast_ABCDHRF`: hint-only + rigid candidate separation + hot-path optimization。
  - `src/host/geo.py`
    - no-drop refine で計算済み `point_3d` と residuals を再利用。
    - 2-view triangulation で `cv.triangulatePoints()` を使う fast path を追加。
    - forward epipolar gate 後に必要候補だけ backward distance を計算する。
- 結果:
  - `fast_ABCDF`: `pipeline_pair_ms.p95` 4.919 ms、baseline比 約 17.8%改善。
  - `fast_ABCDHRF`: `pipeline_pair_ms.p95` 3.792 ms 前後、hint-onlyよりさらに改善。
- 判断:
  - hot-path optimization は fallback保険として有効。
  - 本命は `fast_ABCDHRF`。

### PDCA 3: marker-index direct rigid solve + live diagnostics off

- 仮説:
  - rigid hint points は marker index を持っているため、汎用 correspondence 探索をせず、marker index 直結Kabschで解ける。
  - subset diagnostics は committed pose に使っていないため、live表示では off にする方が最大遅延を安定して下げられる。
- 実装:
  - `src/host/rigid.py`
    - rigid candidate separation で `marker_idx` と点を保持。
    - marker index に対応する reference points と observed points で直接 Kabsch solve。
  - `fast_ABCDHRF` を combined experimental candidate として追加。
  - synthetic benchmark helper は `--subset-diagnostics-mode off` を受けられるようにした。
- 結果:
  - `fast_ABCDHRF` default sampled:
    - `pipeline_pair_ms.p95` 3.562 ms。
    - `pipeline_pair_ms.max` 9.641 ms。
    - p95は十分だが、sampled subset diagnostics により max は8.47msを少し超える。
  - `fast_ABCDHRF` + `subset_diagnostics_mode=off`:
    - `pipeline_pair_ms.mean` 3.118 ms。
    - `pipeline_pair_ms.p95` 3.356 ms。
    - `pipeline_pair_ms.max` 3.726 ms。
    - `rigid_ms.p95` 0.807 ms。
    - `triangulation_ms.p95` 1.329 ms。
    - `poses_estimated` は baseline と同じ。
    - `accepted_points` は baseline と同じ。
    - 118fpsの p95 / max 目標を両方通過。
- 判断:
  - 32 blobs/cam 118fps の採択候補は `fast_ABCDHRF` + live表示時 `subset_diagnostics_mode=off`。
  - diagnostics は replay / sampled / background に逃がし、committed tracking の hot path から外す方針がよい。

### 採択候補

- 第一候補:
  - `fast_ABCDHRF` + `subset_diagnostics_mode=off`。
  - object gating 成立中は rigid hint-only geometry。
  - marker index direct Kabsch。
  - geo hot-path optimizations。
  - full generic fallback は維持。
- 採択条件:
  - 実機liveで object gating 成立率が十分に高いこと。
  - fallback時の品質非悪化を replay で確認すること。
  - subset diagnostics は live表示経路では off、検証/replayでは sampled/full に分けること。

### 実行コマンド

- `PYTHONPATH=src .venv/bin/python -m pytest tests/test_geo_blob_assignment.py tests/test_rigid_reprojection_scoring.py tests/test_tracking_pipeline_diagnostics.py tests/test_tracking_runtime.py tests/test_tracking_replay_harness.py -q`
  - Result: 74 passed。
- `PYTHONPATH=src .venv/bin/python tests/perf/synthetic_32_blob_benchmark.py --pairs 300 --warmup-pairs 80 --variants fast_ABCD,fast_ABCDF,fast_ABCDH,fast_ABCDHR,fast_ABCDHRF --subset-diagnostics-mode off`

## 2026-04-26 blob数確認と32 blobs/cam stress調査

### 目的

- 実ログABで `fast_ABCDR` が object-gated fast path 使用率を大きく増やした一方、p95速度ゲートに届かなかった理由を確認する。
- 現在の実ログが高blob負荷ではない可能性があるため、実ログのblob数を集計し、32 blobs/cam の synthetic stress で挙動を見る。

### 実ログのblob数

- `logs/tracking_gui.jsonl`
  - `pi-cam-01`: 平均 2.85、p50 3、p95 4、max 5。
  - `pi-cam-02`: 平均 3.67、p50 4、p95 4、max 5。
  - ペア合計はおおむね 6-8 blobs/pair。
  - slow-pair上位例も 3 + 4 = 7 blobs。
- `logs/archive/rigid_stabilization_pdca_20260425_042805/tracking_gui_baseline.jsonl`
  - 両カメラとも平均約 3.7、p95 4、max 5。
- `logs/archive/rigid_stabilization_new_tracking_20260425_043548/tracking_gui_new.jsonl`
  - 両カメラとも平均約 3.8、p95 4、max 4。

### 解釈

- 今回の実ログABは、32/64/128 blobs/cam のような高blob負荷ではない。
- `fast_ABCDR` が実ログp95で勝てなかった理由は、blob数が少なく、削減メリットより candidate separation の追加コストが見えやすかったためと考えられる。
- 多blob、多カメラ、多剛体では、`fast_ABCDR` のように object-conditioned / rigid-specific に候補を分ける設計が効きやすくなる可能性が高い。
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

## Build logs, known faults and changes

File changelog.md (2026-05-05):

- Rigid tracking now ranks partial marker correspondences by pair-distance before Kabsch, caches subset geometry checks, and vectorizes reprojection scoring to reduce `src/host/rigid.py` hot-path candidate overhead.
- GUI/sim tracking now keeps per-frame runtime diagnostics off by default and enables them only through `runtime_diagnostics_enabled` / `--runtime-diagnostics`.
- Rigid tracking now removes the unused anchor-guided body N-best option from the formal GUI/sim configuration surface and deletes its dead estimator method.
- `tools/sim` now records a hot-path estimate under `logs/sim/passive_stabilization_v2/hotpath_estimate_20260505`, sizing raw-scene CPU load, candidate-scoring cost, and per-body parallelization risk before further optimization.
- GUI tracking now formally adopts controlled generic fallback skipping and compact object-gating diagnostics while leaving the rare body-aware hint fallback out of the production route.
- `tools/sim` now records a body-aware fallback deep dive under `logs/sim/passive_stabilization_v2/bodyaware_deepdive_20260505`, separating adopted generic-skip and diagnostics gains from the non-adopted body-aware fallback path.
- GUI `all_fast` tracking now keeps generic-search skipping enabled but only fires it when all five markers have unambiguous two-camera body-level evidence.
- `tools/sim` now records strict `all_fast` validation under `logs/sim/passive_stabilization_v2/all_fast_strict_20260505`, supporting the controlled generic-search skip as the formal GUI route.
- GUI tracking now skips generic cluster search during strong object-gated CONTINUE frames, thins body-level 2D diagnostics, and throttles raw-scene visualization updates.
- GUI tracking now reuses body-level 2D candidate bins during reacquire and can early-exit once cached 4-of-5 evidence is available.
- `tools/sim` now exposes generic 3D cluster radius and rigid estimator cluster/Kabsch-call counters for comparing layered clustering performance.
- GUI tracking now uses `candidate_00534` custom rigids with body-level 2D N-best enabled and pose-continuity guarding disabled after the 20-cycle performance PDCA in `logs/sim/passive_stabilization_v2/perf_pdca_20260505`.
- Object-gating can now use tunable whole-body 2D N-best assignment for translated marker constellations, and sim phase checks no longer score hidden-only prediction holds as recovery.
- `tools/cad` can now generate printable fixtures directly from sim `custom_rigids` meter-coordinate files, skipping only local fillets that fail on candidate geometry.
- `tools/sim` now treats foot-top rigids as local `+Z` upward and places mesh-lite foot occluders on the local `-Z` side of the marker surface.
- `src/host` now keeps 3D marker point history for temporal 2D ownership experiments, with motion prediction isolated behind an explicit disabled flag.
- `src/host` now has an experimental temporal 2D ownership recovery path that feeds confirmed 3D marker ownership back into the next frame's passive 2D assignment.
- `src/host` now includes a disabled experimental body-level 2D recovery path for testing translated rigid-shape blob assignments before triangulation.
- Passive multi-rigid recovery now holds previously tracked bodies out of anonymous global boot when their own hints disappear, reducing cross-body blob theft during reacquire.
- Multi-rigid boot now ranks candidate point subsets by 2D reprojection evidence when camera context is available, improving passive boot without adding guards.
- GUI tracking now removes the active-anchor tracking route and uses passive temporal body N-best plus rotation-jump cost for body ownership ranking.
- `tools/sim` now routes `five_rigid_body_mesh_lite_v1` through the body-motion trajectory instead of leaving it static.
- `tools/sim` now adds `five_rigid_body_mesh_lite_v1` for CAD surface-mounted capsule occlusion without deterministic marker-drop stacking.
- `tools/sim` mesh-lite capsule occlusion now allows far-side self-occlusion while keeping only endpoint clearance for surface-mounted markers.
- `tools/sim` body-mount scenarios now use the CAD surface-mounted rigid pose consistently whether mesh-lite occlusion is on or off.
- `tools/sim` now rejects mesh-lite body capsules outside body-mount scenarios and preserves CAD fixture height metadata for custom rigid candidates.
- `tools/sim` mesh-lite mounting now uses the CAD fixture base-to-centroid height instead of centroid-local marker Z as the physical surface reference.
- `tools/sim` mesh-lite surface mounting now offsets rigid origins so marker blobs stay outside their own body occluder volume.
- `tools/sim` mesh-lite body-mount reference pose now matches a 1.7m HMD/chest/waist/feet marker layout.
- `tools/sim` body-mount scenarios now use a floor-to-head human-scale pose for mesh-lite capsule occlusion.
- `tools/sim` mesh-lite now mounts rigid layouts on body primitive surfaces with local `+Z` as the outward surface normal.
- `tools/sim` now adds mesh-lite body capsule occlusion and shape observability summaries for comparing current and candidate rigid-body layouts before 3D printing.
- Rigid tracking now reduces GUI hot-path latency by caching blob reprojection uncertainty, reusing geometry observation lookups, using small-sample rigid-hint summaries, and updating angular velocity directly from quaternion deltas.
- `tools/sim` now supports a `pi_snr` marker detection model so body-mounted tests can stress projected blob size/SNR instead of only iid random marker dropout.
- Rigid tracking now short-circuits anchor-only 5-marker recovery to invalid instead of running expensive generic 3D recovery when full 6DoF is unobservable.
- Rigid tracking now uses decoded active-anchor camera rays for PnP-free translation relock while keeping single-anchor recovery classified as prediction hold.
- Rigid tracking now keeps the partial-evidence recovery path PnP-free, relying on active-anchor side-channel hints and temporal body subsets instead.
- Rigid tracking now exposes active-anchor observations as a side-channel for lightweight 2D-constrained prediction holds, keeping full body assignment separate from physical-ID hints.
- `tools/sim` now reports visibility/evidence phase evaluation so prediction-hold compensation is separated from 3D-hint recovery and hard realignment.
- `tools/sim` can now emit one decoded active-anchor marker per rigid outside random detection dropout, and object-gating uses that physical ID while temporal hold only extends existing body hypotheses from anchor evidence.
- Object-gating now keeps body-level marker assignments while marking local ambiguity, preserving no-false-blob Pi observations for rigid-level scoring.
- Geometry matching and rigid reprojection scoring now use blob-diameter-derived uncertainty so small real-log blobs can be accepted as lower-confidence observations instead of being rejected by fixed pixel residuals.
- `tools/sim` now supports diameter-scaled centroid noise and marker-diameter scaling so passive 4-camera PDCA can test physical Blob/SNR changes instead of only fixed pixel-noise stress.
- `docs/10_in_progress/rigid_body_stabilization_plan_v2.md` now records the continued passive PDCA showing `1.25x` marker diameter with diameter-aware centroid noise clears the hard `0.15px` no-dropout stress across seeds `44-46`.
- `docs/10_in_progress/rigid_body_stabilization_plan_v2.md` now records a 10-cycle passive stabilization PDCA showing the current chest blocker is sustained evidence starvation rather than margin or continuity-guard tuning.
- `tools/sim` and rigid tracking now expose passive-stabilization V2 entry diagnostics for mode counts, candidate rejection reasons, body conflicts, and blob-quality summaries.
- `docs/10_in_progress/rigid_body_stabilization_plan_v2.md` now defines a passive 4-camera, 5-blob PDCA entry plan for replacing local threshold tuning with mode separation, body-level assignment, and blob-quality diagnostics.
- `docs/10_in_progress/rigid_body_design_v2.md` now records 10 more sequential sustained-run PDCA cycles, narrowing the current blocker to pi-cam-04 waist/left_foot projection conflict and chest re-entry jumps.
- `tools/sim` summaries now report top position and rotation delta events so rigid-body V2 sustained-run failures can be traced to exact frames and bodies.
- Rigid tracking now holds prediction instead of committing or invalidating poses that lose a frame-local blob ownership contest, and rigid-body V2 PDCA promotes `candidate_00534` with expanded waist subset metadata for sim validation.
- `tools/rigid_body_design_search.py` and `tools/rigid_body_projection_screen.py` now find a Gate 2/3 passing rigid-body V2 candidate and export sim-readable custom rigid definitions for validation.
- `src/host/pattern_evaluator.py` and `tools/rigid_body_design_search.py` now emit Gate 2 subset-whitelist JSON and candidate search records for rigid-body V2 design PDCA.
- `docs/10_in_progress/rigid_body_design_v2.md` now defines an end-to-end rigid design plan from candidate generation through geometry, projection, sim validation, and CAD freeze criteria.
- Object-gating now keeps marker-blob assignment candidates compact until final rigid-hint payload emission, trimming allocation overhead in the live gating path.
- Object-gating now reuses per-camera blob diameters and assigned-blob distance matrices, lowering close-blob ambiguity overhead while preserving marker-swap guards.
- `.gitignore` now groups OS, Python, local runtime, and agent artifacts while ignoring GUI/deploy logs without hiding tracked hardware STL assets.
- Object-gated rigid tracking now drops low-margin marker-vs-marker assignments, reducing temporal marker identity swaps without broadening the close-blob distance gate.
- Object-gated rigid tracking now treats blob-center overlap relative to blob diameter as ambiguous, catching close-marker swaps that are wider than the fixed sub-pixel guard.
- `src/host/tracking_replay_harness.py` now exposes the object-gating ambiguous blob threshold so replay checks can compare the new close-blob guard against disabled baselines.
- Object-gated rigid tracking now drops sub-pixel ambiguous blob assignments before triangulation, reducing marker swaps and cross-rigid ownership at close projections.
- `tools/sim` now adds `five_rigid_body_occlusion_relaxed_v1`, a slightly softer body-mounted scenario for green-regression PDCA without replacing the hard fixture.
- `tools/sim` can now optionally merge near-overlapping true blobs in `five_rigid_body_occlusion_v1` for body-mounted observation-model PDCA.
- `tools/sim` summaries now include warmup-trimmed pair, rigid, and geometry timing for body-mounted PDCA performance reads.
- `docs/10_in_progress/sim_performance_upgrade_log_v2.md` now removes the superseded real-log distance/merge check section after adopting the depth-scaled blob-size premise.
- `docs/10_in_progress/sim_performance_upgrade_log_v2.md` now simplifies V2 goals and methods around GT pose accuracy, 118fps budget, and observation-led PDCA decisions.
- `docs/10_in_progress/sim_performance_upgrade_log_v2.md` now replaces old V2 PDCA tables with a restarted 10-cycle body-mounted PDCA using depth-scaled true blob sizes.
- `tools/sim` now keeps body-mounted true blob areas camera-specific while gently scaling equivalent diameter by camera depth for closer marker views.
- `docs/10_in_progress/sim_performance_upgrade_log_v2.md` now records a real-log blob area generation check and rejects the oversized first-pass distance/merge observation model.
- `tools/sim` summaries now include `ownership_confusion_summary` for camera- and marker-level failure diagnosis.
- `docs/10_in_progress/sim_performance_upgrade_log_v2.md` now defines the real-operation-like body-mounted sim premises and PDCA entry points before further optimization.
- `tools/sim` now defaults body-mounted scenarios to the `cube_top_2_4m_aim_center` camera rig through `camera_rig_source=auto`.
- `tools/sim` now adds a `cube_top_2_4m_aim_center` camera rig source for four cameras on a 2.4m cube top face aiming at the cube center.
- `docs/10_in_progress/sim_performance_upgrade_log.md` now records a 5-cycle real-log-like body-mounted PDCA showing pose-guard speed tradeoffs and centroid-jitter failure boundaries.
- `tools/sim` now makes `five_rigid_body_occlusion_v1` use real-log-like camera-specific true blob sizes, keeps random false blobs out of that scenario, and reports blob area summaries.
- `docs/10_in_progress/sim_performance_upgrade_log.md` now records the current body-mounted PDCA 20 rerun against the GUI baseline, with aggregate sim results under `logs/sim/five_rigid_body_occlusion_v1/20260501_pdca20_body_mount_current/`.
- `AGENTS.md` now defines PDCA as a fully sequential measure-read-decide loop instead of a preplanned AB batch.
- `tools/sim` now accepts sim-only rigid-stabilization overrides and reports variant settings during PDCA runs.
- `tools/cad/README.md` now documents the CadQuery fixture generator behavior, hole auto-placement, presets, custom JSON input, and key geometry options.
- `tools/cad` base-hole auto-rotation now accounts for stem radius and hex-hole outer radius to avoid hole/stem overlap.
- `tools/cad` now lifts generated marker centers by 7 mm so marker spheres stay above the base bottom for FDM printing.
- `tools/sim` now adds `five_rigid_body_occlusion_v1` for body-mounted 5-rigid stress and documents body-mounted PDCA results without changing the guarded GUI live path.
- `tools/cad` now includes all five exploratory rigid-body presets and can export them as STL files in one command.
- `tools/cad` now auto-rotates the paired base holes toward the clearest direction away from generated stems.
- `tools/cad` now cuts a hexagonal base hole and an opposite round through-hole into the rigid fixture base.
- `tools/cad` now adds a 1 mm top chamfer to the central base disk during rigid fixture generation.
- `tools/cad` now extends hub-side stems by 1 mm and removes the extra hub blend collars while keeping stem endpoint balls.
- `tools/cad` now applies 1 mm fillets to rigid fixture joint edges for smoother stem connections.
- `tools/cad` now blends stem-to-hub joints with 5 mm spheres on the hub-side stem endpoints.
- `tools/cad` rigid fixture generation now uses a cylindrical hub, marker spheres, and radial stems matching the current print prototype design.
- `tools/cad` now provides a CadQuery setup note and first-pass rigid-body marker fixture generator for STL/STEP output from marker coordinates.
- `docs/10_in_progress/sim_performance_upgrade_log.md` now documents sim performance scoring, PDCA log format, and moved cycle 1-50 performance history out of the rigid body design notes.
- Removed unused rigid tracking dead code from `src/host/rigid.py`, including the stale PnP fallback and unused helper wrappers.
- `static/index.html` now uses the V2 GUI as the standard interface without the temporary V2 title pill, with `static/index_v2.html` and `/v2` kept as matching compatibility entry points.
- `tools/sim` now includes `five_rigid_dance_swap_red_v1`, a 4-camera 5-rigid red stress scenario with cross-rigid alias blobs for ownership/confusion PDCA.
- GUI/live rigid prediction holds now use the cycle45 5-marker route with a 24-frame unseen hold and damped velocity during sustained occlusion, improving `five_rigid_dance_hard_occlusion_v1` head validity and rotation stability while keeping ownership and jump checks clean.
- `tools/sim` now includes `five_rigid_dance_hard_occlusion_v1`, a deterministic 4-camera 5-rigid stress scenario with repeated same-marker two-camera blackouts, foot-cross false blob bursts, and weak reacquire phases.
- `tools/sim` and GUI tracking now adopt the 5-marker `design_5marker_seed` subset-policy route for the 5-rigid dance/occlusion stress scenario, with object-gating coverage reuse, lightweight per-frame event diagnostics, and per-frame blob lookup reuse.
- `docs/10_in_progress/rigid_body_design.md` now includes current 5-rigid design status, best-known metrics, subset-whitelist policy, and handoff notes for the next implementer.
- `tools/sim` now includes a 4-camera 5-rigid dance/occlusion stress scenario, and multi-rigid boot rejects 3D-only candidates that fail 2D reprojection checks.
- GUI tracking runtime now defaults to the adopted `fast_ABCDHRF` live stabilization path, including object-gated low-marker prediction hold for short occlusions.
- `tools/sim` now covers 4-camera and 2-camera moving rotating waist partial-occlusion scenarios, while GUI tracking holds short low-marker occlusions with angular prediction and keeps partial object-gating on the fast path.
- `src/host/rigid.py` now holds established but unseen multi-rigid bodies on prediction instead of scanning other visible rigid clusters during occlusion.
- `tools/sim` summaries now include sustained 118fps budget checks and rigid variant metrics for waist+wand occlusion PDCA.
- `AGENTS.md` now points simulator work to `tools/sim/` and `docs/40_tools/multi_rigid_simulator.md`.
- `tools/sim` now hosts the waist+wand 4-marker simulator with sidecar blob ownership metadata, scenario summaries, and generated 4-camera intrinsics-copy support.
- `tests/sim` and `tests/test_sim_closed_loop.py` now cover waist+wand projection, sidecar ownership metadata, scenario CLI output, and legacy closed-loop metrics.
- `static/index.html` and host GUI services now block calibration controls and API mutations while tracking is running.
- Added `docs/10_in_progress/multi_rigid_simulator_plan.md` with a staged waist+wand simulator PDCA plan before generated 4-camera and 5-marker expansion.
- `src/host/rigid.py` now applies strict 2D recovery checks to previously tracked LOST/BOOT rigid candidates so unscored generic recovery cannot move tracker state toward another rigid.
- `static/index.html` now starts GUI tracking with reacquire guard enforcement enabled alongside object gating and continuity guards.
- `src/host/rigid.py` now resolves multi-rigid pose candidates frame-locally before tracker commit, keeps large-innovation reacquire candidates pending, and skips unowned BOOT generic fallback to avoid cross-rigid attraction.
- `docs/30_procedure/pi_gui_start_stop.md` now documents the Codex desktop `launchctl submit` GUI restart path when `nohup` children do not survive shell exit.
- Tracking viewer raw blobs now use a coalesced full-scene triangulation path so `static/index.html` can show all raw points while pose tracking stays on the fast object-gated path.
- Object-gated rigid-hint pose enforcement now refuses blob views already owned by another rigid body, keeping overlapping multi-rigid occlusion recovery from adopting the wrong target.
- Object-gated tracking now rejects continuation poses that reuse another rigid body's gated blobs, preventing fully occluded `waist` markers from snapping onto `wand`.
- Tracking now falls back to full-blob geometry when any rigid body loses its object gate, so a moving `waist` can reacquire instead of disappearing from the fast filtered scene.
- Object-gated tracking now rejects bad generic continuation poses when rigid-hint confirmation is missing, preventing one rigid body from snapping onto another body's blobs.
- Tracking diagnostics now reset per Start/Stop and GUI JSON responses ignore client disconnects so real tracking logs are not buried by stale browser metrics or BrokenPipe traces.
- Host UDP receive now drains bursts and drops stale datagrams before processing so live tracking follows the newest camera frames instead of replaying backlog.
- Tracking now resets browser scene sequence state on every Start/Stop so a new run's low sequence numbers are not discarded before Three updates.
- Multi-rigid bootstrapping now accepts 3-of-4 marker candidates so a rigid body can appear when one triangulated blob is missing.
- Camera Health now keeps the raw clock delta visible as `Clock Δ` while separating it from live GUI latency.
- Camera Health in `static/index.html` now reports live pair age, timestamp FPS, receive FPS, and Pi send time instead of surfacing cross-clock latency as GUI delay.
- Host UDP receive buffering now favors fresh live frames over preserving multi-second camera backlogs, reducing GUI pose latency when cameras outpace host drain rate.
- Tracking scene streaming now uses shorter live trails and a lower Python thread switch interval so the GUI stream and UDP receive loop stay responsive during 2-rigid tracking.
- Host tracking now keeps the UDP receive thread parse-free so live camera datagrams drain before JSON parsing and tracking work can add latency.
- Tracking Rigid Bodies in `static/index.html` now reuse row DOM nodes during status refreshes so browser-side ping markers do not stack on the list.
- Tracking Start in `static/index.html` now keeps object-conditioned gating enabled so the GUI uses the low-latency `fast_ABCDHRF` route.
- Tracking now bootstraps multiple rigid bodies from mixed blob clouds so `waist` and custom `wand` can both acquire and enter the fast object-gated path even with 32 blobs/camera.
- Tracking in `static/index.html` now initializes the Three.js viewer before restoring the active view so the first scene is not consumed by the loading placeholder.
- Intrinsics, Camera Pose Capture, and Floor / Metric in `static/index.html` now have title-level instruction buttons and skippable instruction modals.
- Floor / Metric result card in `static/index.html` no longer inherits vertical panel spacing while sitting beside capture controls.
- Floor / Metric capture and result cards in `static/index.html` now share the same grid width and alignment.
- Floor / Metric result card in `static/index.html` now matches the capture card height and typography.
- Extrinsics and Floor / Metric cards in `static/index.html` now use the same compact panel rhythm as the rest of the GUI.
- Extrinsics in `static/index.html` now hides developer solver parameters and uses fixed synced-camera defaults behind the Generate action.
- Sidebar navigation in `static/index.html` now keeps page/view state synchronized when leaving Tracking for calibration pages.
- Camera Status in `static/index.html` now labels Pi Admin release, CPU, and last-action details explicitly and hides missing values.
- Pi Admin Start Service now repairs `loutrack.service` with MJPEG `8555` and re-enables the active GUI preview after restart.
- Floor / Metric in `static/index.html` now shows a result card beside capture controls with saved/capturing/not-captured status.
- Camera Status in `static/index.html` no longer shows the redundant four-card summary row above Pi Admin.
- Pi Admin in `static/index.html` is more compact and aligns service/release action groups with muted status chips.
- Floor metric capture in `static/index.html` now uses a compact control card and hides the unnecessary Stop button.
- Intrinsics, camera pose, and floor metric pages in `static/index.html` now open image-backed instruction modals with step-specific calibration guidance.
- Intrinsics calibration output in `static/index.html` now sits directly below Live Feed instead of being pushed to the bottom of the right column.
- Intrinsics setup in `static/index.html` now hides fixed board defaults and uses prominent camera selection buttons above the remaining square-length setting.
- Sidebar calibration steps in `static/index.html` now turn green only when their pose, floor, or extrinsics output files exist.
- Restyled `static/index.html` with the v2 dark-blue color scheme while keeping the v1 workflow.
- Removed the discarded `static/index_v2.html` variant after carrying its dark-blue scheme into v1.
- Camera workflow navigation now uses orange for unfinished setup steps and green for completed steps.
- Camera Status now shows PTP role warnings, host/Pi network preflight, clearer offline reasons, release/version signals, and Pi update progress.
- Added a first-install Pi node script and README covering Raspberry Pi Imager naming, PTP roles, service setup, and GUI discovery.
- Camera Status now has a grouped Pi Admin panel for selected-camera service status, update/rollback, reboot, and shutdown controls.
- tracking now has a switchable low-marker position acceleration guard that clamps occlusion jumps while keeping replay AB controls
- pose-continuity guard now holds only rotation during low-marker jumps so position stays on the normal tracking path
- GUI tracking start now enables the tested object-gating plus low-marker pose-continuity guard in the standard start payload
- tracking replay now has an experimental low-marker pose-continuity guard that can hold predicted poses during blob occlusion while preserving the default live path
- GUI tracking now starts the official live path with `fast_ABCDHRF` and `subset_diagnostics_mode=off` for lower-latency 32-blob operation
- docs/10_in_progress/performance_upgrade_log.md is now fully localized in Japanese while preserving benchmark paths and commands
- rigid body design notes now record 5-marker, mode-policy, and subset-whitelist PDCA results in `docs/10_in_progress/rigid_body_design.md`
- added `tests/perf/synthetic_32_blob_benchmark.py` for deterministic 4-camera 32-blobs/camera pipeline AB JSON metrics
- tracking now has experimental `fast_ABCDH/HRF` 32-blob stress paths that reuse rigid-hint triangulation, direct marker-index rigid solves, and optional live diagnostics-off benchmarking
- tracking replay now compares staged performance-upgrade variants with subset time budgets, object-gating fallback breakdowns, rigid candidate separation, slow-pair traces, and capped GUI raw-point payloads
- added experimental `fast_ABCDP` replay path for generic epipolar candidate pruning AB tests while keeping `fast_ABCD` as the official default
- tracking now uses the fast_ABCD pipeline as the default path while keeping baseline selectable for replay comparisons
- tracking replay now supports baseline/fast_A-fast_ABCDE AB reports with fast geometry, sampled subset diagnostics, object-gated fallback, and backpressure metrics
- object-gating replay can now limit activation to recovery modes and records mode on rigid-hint pose events
- rigid body stabilization notes now summarize failure-log PDCA findings, replay status, and live performance hold points
- rigid stabilization replay now compares object-gating enforcement with flip-tolerant go/no-go criteria and scopes extra reacquire guarding to post-reacquire windows
- tracking replay harness now extracts live diagnostics failure segments and resolves `extrinsics_pose_v2.json` inputs to the calibration directory for replay
- GUI tracking start no longer blocks ready cameras whose generated mask has zero masked pixels
- GUI tracking start now disables live rigid-stabilization diagnostics in the start payload so logs can be replayed offline
- object-gating enforcement now explicitly adopts qualified rigid-hint poses and exposes runtime/replay flags with enforcement diagnostics
- rigid stabilization now requires consistent reacquire candidates and one-to-one 2D scoring to reduce flip-prone pose recovery
- rigid stabilization replay now reports subset adoption shadow outcomes before enabling subset pose commits
- Phase 6.5 rigid stabilization now prunes subset candidates and ranks them with combined 2D, coverage, source, and temporal scores in replay diagnostics
- Phase 6 rigid stabilization now emits diagnostics-only subset RANSAC and weighted-solve replay summaries before changing pose adoption
- Phase 5 rigid stabilization now compares diagnostics-only `rigid_hint` poses against generic poses in replay summaries so Phase 6 subset RANSAC inputs are ready
- Phase 5 rigid stabilization now reports object-conditioned 2D gates plus diagnostics-only `rigid_hint` triangulated points beside generic triangulation
- Phase 4.5 reacquire guard tuning now uses a 136 degree rotation-innovation threshold that keeps replay valid-frame loss under the go/no-go budget
- Phase 4.5 rigid stabilization replay now records per-frame reacquire guard events and compares shadow versus enforced guard outcomes before Phase 5
- rigid body stabilization planning now folds Phase 5 prerequisites into Phase 4.5 sub-steps instead of adding a separate Phase 4.6
- Phase 4.5 rigid stabilization now adds shadow-first reacquire candidate guard diagnostics with optional enforcement hooks
- rigid body stabilization planning now includes Phase 4.5 shadow-first reacquire candidate guard before object-conditioned gating
- Phase 4 rigid stabilization now adds 2D reprojection scoring diagnostics from observation provenance while preserving existing pose acceptance
- Phase 3 rigid stabilization now reports boot/continue/reacquire/lost mode transitions and pose innovation diagnostics without changing pose acceptance
- Phase 2 rigid stabilization now exposes side-effect-free pose prediction and rolling confidence diagnostics for tracked rigid bodies
- Phase 1 rigid stabilization pattern evaluator now reports self-symmetry, subset ambiguity, and cross-pattern match risks for built-in and custom rigid bodies
- Phase 0.5 rigid stabilization provenance now carries per-camera 2D observations and per-point triangulation sources through `src/host/geo.py` and `src/host/pipeline.py`
- rigid body stabilization progress notes now record Phase 0 replay results and Phase 0.5 expectations in `docs/10_in_progress/rigid_body_stabilization_log.md`
- Phase 0 rigid stabilization diagnostics now track valid/lost runs and add a same-path tracking replay harness for `logs/tracking_gui.jsonl`
- rigid body stabilization planning now includes same-path log replay, observation provenance, pattern ambiguity evaluation, and safer 2D-gated tracking phases in `docs/10_in_progress/rigid_body_stabilization_plan.md`
- the tracking viewer now hides the green origin dot while keeping the standard world-axis lines in `static/index.html`
- the Tracking Control card no longer shows the raw extrinsics file path banner in `static/index.html`
- sidebar logo in `static/index.html` now uses the `static/loutrack-logo.png` wordmark image instead of the compact `LT2` badge
- top-level `README.md` and `README_ja.md` now match the current GUI/tracking workflow and include the `readme_imgs/tracking.png` tracking view preview
- the tracking viewer can now use Ctrl/Cmd-drag rectangle selection to register or delete custom rigid bodies from triangulated blobs, persisting them in `calibration/tracking_rigids.json` and applying them live via `static/index.html` and `src/host/gui_tracking_service.py`
- Raspberry Pi capture nodes can detect reflective blobs and stream observations to the host
- the host GUI can drive blob tuning, mask building, pose capture, floor or metric capture, and extrinsics generation
- the host GUI now keeps selected-camera targeting strict for camera commands and settings application
- runtime-generated capture paths are surfaced as latest observed values and can be adopted explicitly without silently overwriting draft form inputs
- stopped intrinsics captures can now be synced back from the Pi for host-side calibration without relying on stale in-memory frame state
- the tracking GUI queues SSE scene updates for the next browser animation frame, drawing raw points without interpolation while surfacing geometry and WebGL timing diagnostics
- the intrinsics result panel now refreshes immediately when entering the view or launching host-side calibration, reducing stale "Calibrating on host..." displays
- the Matplotlib extrinsics viewer can now overlay triangulated wand metric samples in similarity, metric, or world space
- wand-based world alignment now chooses the floor-normal sign so ceiling cameras appear at positive height above the floor plane
- wand-based world alignment now constrains floor-normal direction from the wand face: +X is elbow to long branch, +Y is elbow to short branch, and the selected front/back side defines +Z
- the GUI 3D Tracking viewer now uses the floor/metric capture wand as the world origin when metric/world extrinsics are available, with a black Z-up viewport, Z-axis orbit controls, camera-name labels, and visible triangulated-blob points separate from rigid bodies
- tracking start now configures selected Pis for low-overhead preview and explicitly starts their `pose_capture` UDP streams before expecting 3D blob points
- Pi `start` commands can now carry a PTP/epoch `start_at_us` countdown; GUI tracking plus extrinsics pose/wand capture schedule starts about 1 second in the future and send them in parallel so synced Pis begin streaming at the same target time
- host-side intrinsics calibration now filters sparse or homography-degenerate ChArUco frames before calling OpenCV, preventing single bad captures from tripping `initIntrinsicParams2D`
- tracking now applies extrinsics v2 `focal_scale` to effective `fx/fy`, so live epipolar matching and triangulation use the same intrinsics that bundle adjustment validated
- tracking start tolerates Pis that are already streaming so the host receiver can recover cleanly after a GUI restart or partial start failure
- live tracking pairing now consumes each buffered Pi frame only once, emits pairs in chronological order, and calculates FPS/latency from UDP receive timestamps, preventing inflated 300+ FPS and missing-frame counts from stale or out-of-order buffer reprocessing
- live tracking now assumes Raspberry Pi Camera Module 3 Wide NoIR in fixed `1536x864 @ 118fps` mode and uses a fixed `4237 us` timestamp-only pairing window, matching the nearest capture-time frames within a half-frame bound without re-enabling `frame_index` fallback
- live tracking scene updates now use a push stream for the GUI viewer, emit newly completed frame pairs without a fixed 16 ms batching delay, and draw world-space trails and marker positions without double-applying rigid-body transforms
- tracking UDP diagnostics now keep Pi-side capture timestamps separate from raw host receive time; `pose_capture` payloads omit `frame_index`, and tracking pairing uses timestamp-only matching while surfacing timestamp source and capture-to-send timing
- tracking performance diagnostics now separate Pi queue/detection/send timing, Host pair/3D/rigid/logger timing, SSE write health, and browser receive/apply/render timing with bounded rolling summaries and low-frequency JSONL diagnostic events
- raw 3D blob reconstruction now uses one-to-one epipolar assignment before triangulation, preventing the same 2D blob from generating multiple 3D points while keeping rigid-body geometry out of the raw matcher
- host-side raw 3D blob reconstruction now matches on undistorted observations, uses robust multi-view inlier refinement with reprojection/parallax gating, and exposes triangulation-quality diagnostics separately from the existing `raw_points` payload while keeping tracking pairing fixed at the configured half-frame bound
- rigid-body candidate clustering now uses an 80 mm radius instead of marker-diameter spacing, with a single-pattern fallback that tests the full point set only when clustering produces no large-enough candidate
- GUI detection defaults now start at exposure `5000 us`, gain `8`, focus `0.325`, threshold `200`, circularity `0.2`, and no blob diameter limits. Exposure controls are capped at `8000 us`, fps is fixed at `120`, and focus/circularity remain fixed in the GUI/control flow.
- Pi control commands are now defined from a shared runtime manifest so the Pi server, host CLI, ping diagnostics, and `schema/control.json` stay aligned as intrinsics commands evolve
- the host GUI backend now routes settings, tracking, intrinsics, capture-log, and extrinsics orchestration through dedicated internal services while keeping the existing `/api/*` surface unchanged
- the next GUI backend split now also has extracted camera-status, workflow-summary, and `/api/state` presentation helpers staged as compatibility-preserving host modules
- the Pi blob-detection to host tracking-viewer path now skips preview packet work when no preview consumer is active, throttles idle diagnostics, reuses paired-frame buffers incrementally, and updates the Three.js viewer without recreating hot-path geometry attributes on every scene event
- Pi-side tracking now avoids static-mask frame copies in blob detection, skips diameter/circularity math unless those filters are active, and only builds MJPEG preview packets while a viewer is actually connected
- Raspberry Pi deployment now preserves the local `src/pi` and `src/camera-calibration` layout inside each Pi release, uses stdin-safe rsync/SSH arguments, and installs/updates a per-camera `loutrack.service` before restarting capture
- the Extrinsics quality panel now shows API running/success/failure state plus input log, output path, metric scale, and world-frame/Z-up alignment details
- Extrinsics generation now hides path-edit fields in the GUI and uses the standard calibration/output paths plus latest capture logs automatically
- Floor / Metric capture now uses a fixed 1 second default capture and the standard wand metric log path without GUI path/duration settings
- tracking GUI scene updates now coalesce SSE payload parsing to the latest frame, avoid hidden debug JSON churn, and display freshness from host scene update time; Pi capture also flags and falls back from stale sensor timestamps
- tracking start is now surfaced through explicit readiness blockers (`extrinsics_missing`, `no_cameras_selected`, `camera_unhealthy`, `mask_missing`), Stop remains idempotent from the GUI, and failed starts keep a visible tracking-panel error state
- browser MJPEG preview now uses same-origin host proxy routes (`/api/cameras/<camera_id>/mjpeg`) instead of direct Pi IP URLs, camera diagnostics expose preview intent plus upstream proxy errors, and normal browser-side stream disconnects are no longer reported as upstream failures
- tracking runtime status for the GUI is now sampled/cached separately from fast scene updates, and camera scene geometry is reused instead of being rebuilt on every pose callback
- the calibration flow can produce intrinsics and extrinsics JSON outputs
- synchronized multi-camera observations can be reconstructed into 3D marker positions
- the host can inspect tracking state, scene snapshots, and calibration-related metrics
- host tracking now uses a fixed `4237 us` half-frame pair window at `118fps`, removes the host-side sync-quality dashboard and adaptive pair-window logic, and drops `sync` status payloads from tracking UI/API paths

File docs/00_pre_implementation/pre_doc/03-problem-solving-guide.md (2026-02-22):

# 課題解決の指針 (デバッグ/検証の進め方)

`context/request.md` の課題(同期・較正・遮蔽耐性・運用)は、実装してから一気に解けるタイプではなく、**観測→仮説→改善**を回す設計が必要です。

## 1. まず「観測できる」ようにする

- **ログ**: Pi→Hostの受信パケット(時刻/内容)を丸ごと保存
- **リプレイ**: 同じログを再生して、アルゴリズム変更の効果を比較
- **メトリクス**:
  - fps(受信/処理/出力)
  - エンドツーエンド遅延(可能なら)
  - 観測数(点が何台のカメラに見えているか)
  - 再投影誤差(対応付け/三角測量の健全性)

先駆者の例(メトリクスの出し方):
- fps emit: `references/jyjblrd/Low-Cost-Mocap/computer_code/api/index.py`
- 画面側の操作/イベント: `references/jyjblrd/Low-Cost-Mocap/computer_code/src/App.tsx`

## 2. 座標系を最初に固定する

SteamVR連携まで見据えると、座標系が曖昧だと必ず破綻します。

- 各カメラ座標系
- World座標系(床/原点)
- SteamVR座標系

先駆者の例(床合わせ/原点):
- `acquire-floor`, `set-origin`: `references/jyjblrd/Low-Cost-Mocap/computer_code/api/index.py`
- UIからのトリガ: `references/jyjblrd/Low-Cost-Mocap/computer_code/src/App.tsx`

## 3. 同期は「完全同期」を狙わない

現実的には、以下の3層で誤差を吸収します。

1. **クロック同期**: PTP/NTPで誤差を縮める
2. **ホスト側ペアリング**: timestamp窓で左右/複数カメラを束ねる
3. **フィルタ**: 欠損やジッタをKalmanで吸収

重要: 「同期の実装が進んでいないから三角測量は後回し」ではなく、
まずソフト側で動かして **許容窓がどれくらい必要か** を測り、PTP導入の価値を定量化する。

## 4. 遮蔽耐性は “トラック管理” の問題

`context/request.md` は点ごとのKalmanを想定していますが、実運用は以下がセットです。

- 予測: 次フレームに現れそうな位置(ゲーティング)
- 関連付け: 観測点をどのトラックに割り当てるか
- 再同定: 一時消失後の復帰
- 外れ値除去: 反射/ノイズ

先駆者の例(エピポーラ + 再投影誤差で外れを抑える):
- `find_point_correspondance_and_object_points`: `references/jyjblrd/Low-Cost-Mocap/computer_code/api/helpers.py`

## 5. 失敗を切り分ける優先順位

デバッグの優先は以下です(上ほど先)。

1. データ契約の破綻(型/単位/座標)
2. 時刻の破綻(ペアリングが崩れている)
3. 較正の破綻(歪み/外部姿勢が狂っている)
4. 対応付けの破綻(点の組み合わせが間違う)
5. フィルタ/クラスタリング/剛体推定

この順にしないと「フィルタでごまかして悪化」が起きます。

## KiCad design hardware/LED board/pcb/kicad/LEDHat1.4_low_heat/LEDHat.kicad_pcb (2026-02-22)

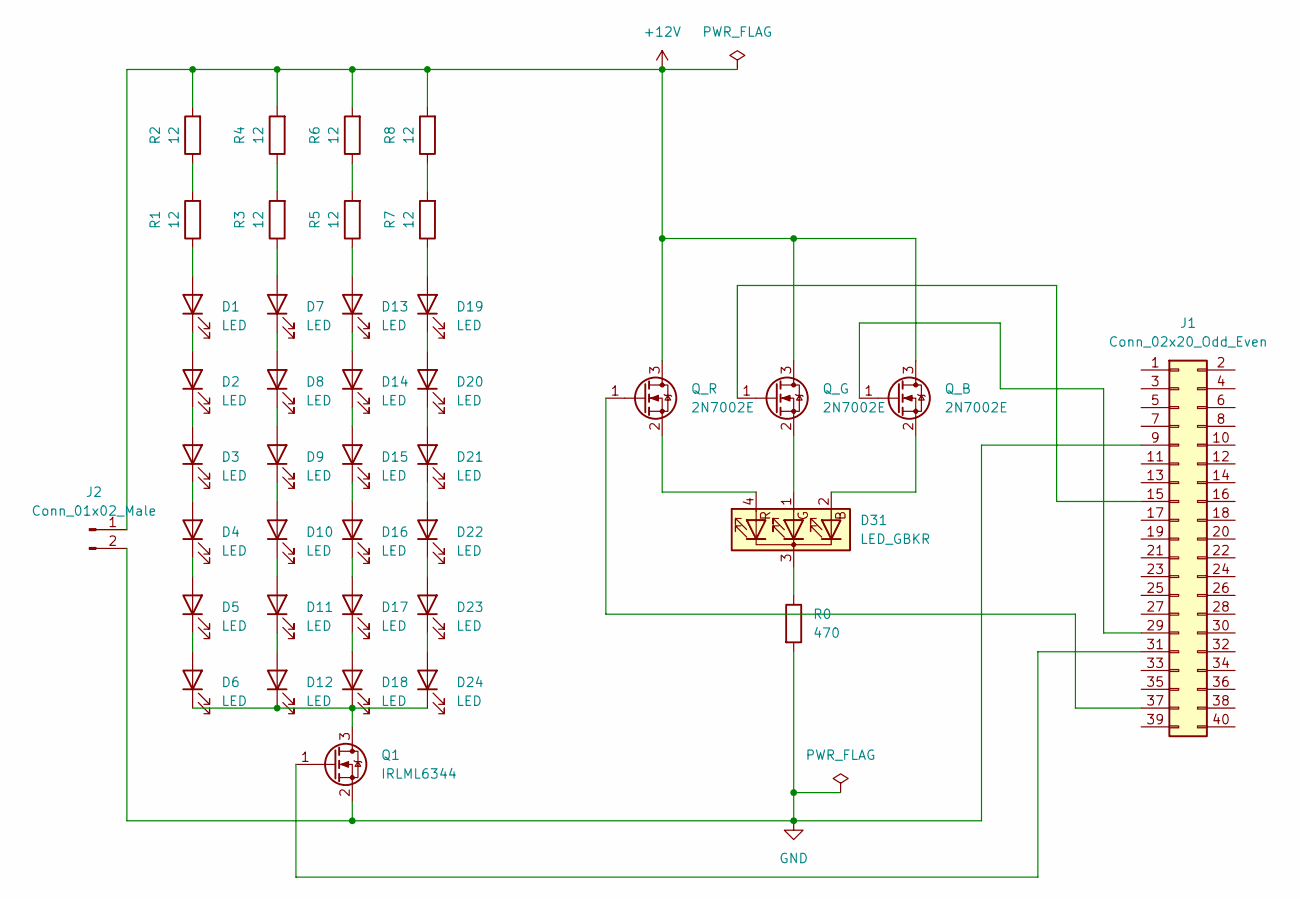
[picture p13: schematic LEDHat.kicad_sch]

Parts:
D1, D2, D3, D4, D5, D6, D7, D8, D9, D10, D11, D12, D13, D14, D15, D16, D17, D18, D19, D20, D21, D22, D23, D24: LED; LED_PLCC_2835_Handsoldering
D31: LED_GBKR; LED_D5.0mm-4_RGB_Staggered_Pins
J1: Conn_02x20_Odd_Even; PinSocket_2x20_P2.54mm_Vertical
J2: Conn_01x02_Male; PinHeader_1x02_P2.54mm_Horizontal
Q1: IRLML6344; SOT-23
Q_B: 2N7002E; SOT-23
Q_G: 2N7002E; SOT-23
Q_R: 2N7002E; SOT-23
R0: 470; R_Axial_DIN0207_L6.3mm_D2.5mm_P7.62mm_Horizontal
R1, R2, R3, R4, R5, R6, R7, R8: 12; R_Axial_DIN0207_L6.3mm_D2.5mm_P7.62mm_Horizontal

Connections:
+12V: J2.1, Q_B.3 (D), Q_G.3 (D), Q_R.3 (D), R2.2, R4.2, R6.2, R8.2
GND: J1.9, J2.2, Q1.2 (S), R0.2
unnamed: D1.1 (K), D2.2 (A)
unnamed: D1.2 (A), R1.1
unnamed: D2.1 (K), D3.2 (A)
unnamed: D3.1 (K), D4.2 (A)
unnamed: D4.1 (K), D5.2 (A)
unnamed: D5.1 (K), D6.2 (A)
unnamed: D7.1 (K), D8.2 (A)
unnamed: D7.2 (A), R3.1
unnamed: D8.1 (K), D9.2 (A)
unnamed: D10.1 (K), D11.2 (A)
unnamed: D9.1 (K), D10.2 (A)
unnamed: D11.1 (K), D12.2 (A)
unnamed: D6.1 (K), D12.1 (K), D18.1 (K), D24.1 (K), Q1.3 (D)
unnamed: D13.1 (K), D14.2 (A)
unnamed: D13.2 (A), R5.1
unnamed: D14.1 (K), D15.2 (A)
unnamed: D15.1 (K), D16.2 (A)
unnamed: D16.1 (K), D17.2 (A)
unnamed: D17.1 (K), D18.2 (A)
unnamed: D19.1 (K), D20.2 (A)
unnamed: D19.2 (A), R7.1
unnamed: D20.1 (K), D21.2 (A)
unnamed: D21.1 (K), D22.2 (A)
unnamed: D22.1 (K), D23.2 (A)
unnamed: D23.1 (K), D24.2 (A)
unnamed: D31.1 (GA), Q_G.2 (S)
unnamed: D31.2 (BA), Q_B.2 (S)
unnamed: D31.3 (K), R0.1
unnamed: D31.4 (RA), Q_R.2 (S)
unnamed: J1.15, Q_G.1 (G)
unnamed: J1.29, Q_B.1 (G)
unnamed: J1.31, Q1.1 (G)
unnamed: J1.37, Q_R.1 (G)
unnamed: R1.2, R2.1
unnamed: R3.2, R4.1
unnamed: R5.2, R6.1
unnamed: R7.2, R8.1

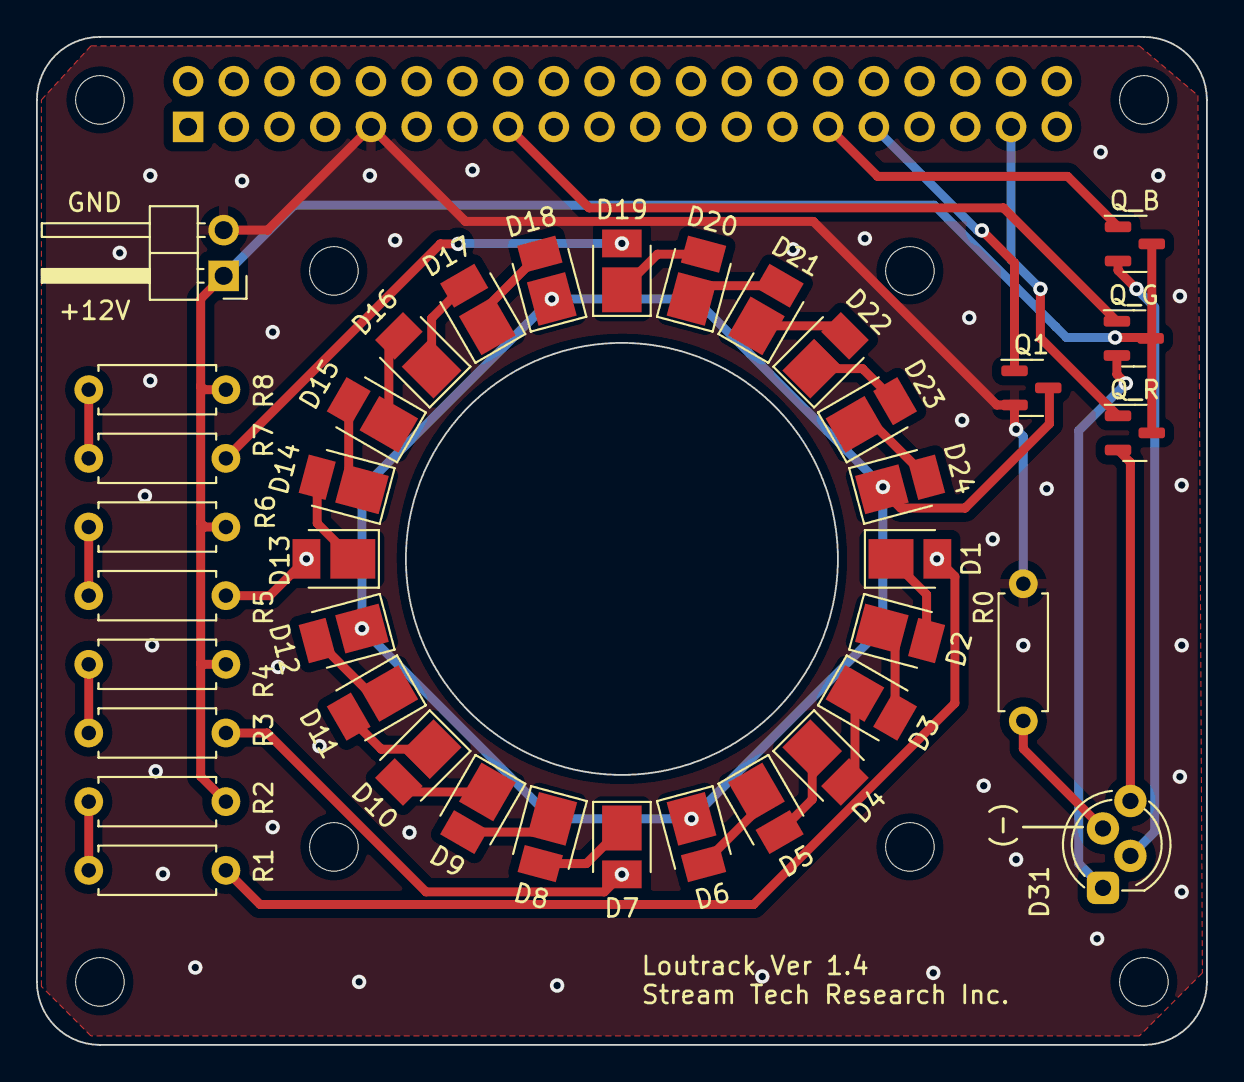
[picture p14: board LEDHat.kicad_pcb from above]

Board: 2 copper layers, 65.0 x 56.0 mm, 40 parts (1 on the bottom side), 39 nets.

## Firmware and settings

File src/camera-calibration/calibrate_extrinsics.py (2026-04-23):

#!/usr/bin/env python3
from __future__ import annotations

import argparse
import json
import sys
from dataclasses import dataclass
from datetime import datetime, timezone
from itertools import combinations
from pathlib import Path
from typing import Any, Dict, List, Optional, Sequence, Tuple

import cv2
import numpy as np
from scipy.optimize import least_squares
from scipy.spatial.transform import Rotation

SRC_ROOT = Path(__file__).resolve().parents[1]
MODULE_ROOT = Path(__file__).resolve().parent
for path in (SRC_ROOT, MODULE_ROOT):
    if str(path) not in sys.path:
        sys.path.insert(0, str(path))

from host.geo import CalibrationLoader, CameraParams
from extrinsics_capture import load_wand_metric_observations
from extrinsics_scale import VALID_WAND_FACE_CONSTRAINTS, WAND_FACE_FRONT_UP, apply_wand_metric_alignment
from extrinsics_validate import validate_wand_metric_extrinsics
from calibration.targets.wand import WAND_POINTS_MM


DEFAULT_OUTPUT = "calibration/extrinsics_pose_v2.json"
DEFAULT_PAIR_WINDOW_US = 4237
DEFAULT_WAND_PAIR_WINDOW_US = 4237
DEFAULT_MIN_PAIRS = 8
_LARGE_RESIDUAL_PX = 50.0


@dataclass(frozen=True)
class PoseObservation:
    camera_id: str
    timestamp: int
    frame_index: int
    image_point: np.ndarray


@dataclass(frozen=True)
class CameraRow:
    anchor_timestamp: int
    anchor_frame_index: int
    image_points: List[np.ndarray | None]
    matched_delta_us: List[int | None]


def _sanitize_path_for_payload(path_value: str | Path) -> str:
    path = Path(path_value)
    if not path.is_absolute():
        return path.as_posix()
    cwd = Path.cwd().resolve()
    try:
        return path.resolve().relative_to(cwd).as_posix()
    except ValueError:
        # Keep payload portable and avoid leaking machine-local absolute directories.
        return path.name


def _extract_frame_payload(entry: Dict[str, Any]) -> Dict[str, Any] | None:
    if entry.get("_type") == "frame" and isinstance(entry.get("data"), dict):
        return entry["data"]
    if "camera_id" in entry and "timestamp" in entry and "blobs" in entry:
        return entry
    return None


def load_pose_capture_rows(path: str | Path) -> Dict[str, List[PoseObservation]]:
    rows: Dict[str, List[PoseObservation]] = {}
    with open(path, "r", encoding="utf-8") as handle:
        for raw_line in handle:
            line = raw_line.strip()
            if not line:
                continue
            entry = json.loads(line)
            payload = _extract_frame_payload(entry)
            if payload is None:
                continue
            camera_id = str(payload.get("camera_id", "")).strip()
            blobs = payload.get("blobs", [])
            if not camera_id or not isinstance(blobs, list):
                continue
            payload_blob_count = payload.get("blob_count")
            blob_count = int(payload_blob_count) if isinstance(payload_blob_count, (int, float)) else len(blobs)
            if blob_count != 1 or len(blobs) != 1:
                continue
            blob = blobs[0]
            rows.setdefault(camera_id, []).append(
                PoseObservation(
                    camera_id=camera_id,
                    timestamp=int(payload.get("timestamp", 0)),
                    frame_index=int(payload.get("frame_index", 0)),
                    image_point=np.array([float(blob.get("x", 0.0)), float(blob.get("y", 0.0))], dtype=np.float64),
                )
            )
    for camera_id in rows:
        rows[camera_id].sort(key=lambda item: item.timestamp)
    return rows


def _nearest_within_window(
    observations: Sequence[PoseObservation],
    timestamp: int,
    pair_window_us: int,
) -> PoseObservation | None:
    if not observations:
        return None
    lo = 0
    hi = len(observations)
    while lo < hi:
        mid = (lo + hi) // 2
        if observations[mid].timestamp < timestamp:
            lo = mid + 1
        else:
            hi = mid
    candidates: List[PoseObservation] = []
    if lo < len(observations):
        candidates.append(observations[lo])
    if lo > 0:
        candidates.append(observations[lo - 1])
    if not candidates:
        return None
    best = min(candidates, key=lambda item: abs(item.timestamp - timestamp))
    if abs(best.timestamp - timestamp) > pair_window_us:
        return None
    return best


def _pair_overlap_count(
    observations_a: Sequence[PoseObservation],
    observations_b: Sequence[PoseObservation],
    pair_window_us: int,
) -> int:
    count = 0
    for obs in observations_a:
        if _nearest_within_window(observations_b, obs.timestamp, pair_window_us) is not None:
            count += 1
    return count


def _pair_overlap_key(camera_a: str, camera_b: str) -> Tuple[str, str]:
    return tuple(sorted((camera_a, camera_b)))


def _build_camera_order(
    observations_by_camera: Dict[str, List[PoseObservation]],
    pair_window_us: int,
) -> tuple[List[str], Dict[Tuple[str, str], int]]:
    camera_ids = sorted(camera_id for camera_id, rows in observations_by_camera.items() if rows)
    if len(camera_ids) < 2:
        raise ValueError("At least two cameras with single-blob pose capture observations are required")

    overlaps: Dict[Tuple[str, str], int] = {}
    for camera_a, camera_b in combinations(camera_ids, 2):
        overlaps[_pair_overlap_key(camera_a, camera_b)] = _pair_overlap_count(
            observations_by_camera[camera_a],
            observations_by_camera[camera_b],
            pair_window_us,
        )

    strongest_pair = max(
        overlaps.items(),
        key=lambda item: (item[1], item[0][0], item[0][1]),
    )[0]
    ordered: List[str] = [strongest_pair[0], strongest_pair[1]]
    remaining = set(camera_ids) - set(ordered)

    while remaining:
        left = ordered[0]
        right = ordered[-1]
        best_camera = None
        best_side = "right"
        best_score = -1
        for camera_id in sorted(remaining):
            score_left = overlaps.get(_pair_overlap_key(camera_id, left), 0)
            score_right = overlaps.get(_pair_overlap_key(camera_id, right), 0)
            side = "left" if score_left >= score_right else "right"
            score = max(score_left, score_right)
            candidate = (score, camera_id, side)
            incumbent = (best_score, best_camera or "", best_side)
            if candidate > incumbent:
                best_score = score
                best_camera = camera_id
                best_side = side
        assert best_camera is not None
        if best_side == "left":
            ordered.insert(0, best_camera)
        else:
            ordered.append(best_camera)
        remaining.remove(best_camera)

    return ordered, overlaps


def build_camera_order_and_rows(
    observations_by_camera: Dict[str, List[PoseObservation]],
    pair_window_us: int,
) -> tuple[List[str], List[CameraRow], Dict[str, int]]:
    camera_order, overlaps = _build_camera_order(observations_by_camera, pair_window_us)
    anchor_camera = camera_order[0]
    rows: List[CameraRow] = []
    complete_rows = 0
    for obs in observations_by_camera[anchor_camera]:
        image_points: List[np.ndarray | None] = [obs.image_point.astype(np.float64)]
        matched_delta_us: List[int | None] = [None]
        for camera_id in camera_order[1:]:
            match = _nearest_within_window(observations_by_camera[camera_id], obs.timestamp, pair_window_us)
            image_points.append(None if match is None else match.image_point.astype(np.float64))
            matched_delta_us.append(None if match is None else int(abs(match.timestamp - obs.timestamp)))
        if sum(point is not None for point in image_points) == len(camera_order):
            complete_rows += 1
        rows.append(
            CameraRow(
                anchor_timestamp=obs.timestamp,
                anchor_frame_index=obs.frame_index,
                image_points=image_points,
                matched_delta_us=matched_delta_us,
            )
        )

    pair_overlaps = {f"{a}|{b}": int(count) for (a, b), count in overlaps.items()}
    return camera_order, rows, {
        "captured_rows": len(rows),
        "complete_rows": complete_rows,
        "pair_overlaps": pair_overlaps,
    }


def _scaled_intrinsic_matrix(camera: CameraParams, focal_scale: float) -> np.ndarray:
    intrinsic = np.array(camera.intrinsic_matrix, dtype=np.float64, copy=True)
    intrinsic[0, 0] *= focal_scale
    intrinsic[1, 1] *= focal_scale
    return intrinsic


def _triangulate_multiview_point(
    observations: Sequence[tuple[np.ndarray, np.ndarray, np.ndarray, np.ndarray]],
) -> np.ndarray | None:
    if len(observations) < 2:
        return None
    rows: List[np.ndarray] = []
    for intrinsic, distortion, projection, image_point in observations:
        normalized = cv2.undistortPoints(
            np.asarray(image_point, dtype=np.float64).reshape(1, 1, 2),
            intrinsic.astype(np.float64),
            distortion.astype(np.float64),
        ).reshape(2)
        rows.append(normalized[0] * projection[2] - projection[0])
        rows.append(normalized[1] * projection[2] - projection[1])
    system = np.stack(rows, axis=0)
    _, _, vt = np.linalg.svd(system, full_matrices=False)
    point_h = vt[-1]
    if abs(float(point_h[3])) < 1e-12:
        return None
    return (point_h[:3] / point_h[3]).astype(np.float64)


def _project_point(
    point_world: np.ndarray,
    rotation: np.ndarray,
    translation: np.ndarray,
    intrinsic: np.ndarray,
    distortion: np.ndarray,
) -> np.ndarray:
    rvec, _ = cv2.Rodrigues(rotation.astype(np.float64))
    projected, _ = cv2.projectPoints(
        point_world.reshape(1, 3).astype(np.float64),
        rvec,
        translation.reshape(3, 1).astype(np.float64),
        intrinsic.astype(np.float64),
        distortion.astype(np.float64),
    )
    return projected.reshape(2).astype(np.float64)


def _select_relative_motion(
    points_a: np.ndarray,
    points_b: np.ndarray,
    intrinsic_a: np.ndarray,
    intrinsic_b: np.ndarray,
    distortion_a: np.ndarray,
    distortion_b: np.ndarray,
) -> tuple[np.ndarray, np.ndarray]:
    pts_a_undist = cv2.undistortPoints(
        points_a.reshape(-1, 1, 2).astype(np.float64),
        intrinsic_a.astype(np.float64),
        distortion_a.astype(np.float64),
        P=intrinsic_a.astype(np.float64),
    ).reshape(-1, 2)
    pts_b_undist = cv2.undistortPoints(
        points_b.reshape(-1, 1, 2).astype(np.float64),
        intrinsic_b.astype(np.float64),
        distortion_b.astype(np.float64),
        P=intrinsic_b.astype(np.float64),
    ).reshape(-1, 2)
    fundamental, mask = cv2.findFundamentalMat(pts_a_undist, pts_b_undist, cv2.FM_RANSAC, 1.0, 0.99999)
    if fundamental is None:
        raise ValueError("findFundamentalMat failed for an adjacent camera pair")
    fundamental = np.asarray(fundamental, dtype=np.float64).reshape(-1, 3, 3)[0]
    essential = intrinsic_b.T @ fundamental @ intrinsic_a
    r1, r2, t = cv2.decomposeEssentialMat(essential)
    candidates = ((r1, t.reshape(3)), (r1, -t.reshape(3)), (r2, t.reshape(3)), (r2, -t.reshape(3)))

    if mask is not None:
        inliers = mask.reshape(-1) > 0
        pts_a_undist = pts_a_undist[inliers]
        pts_b_undist = pts_b_undist[inliers]
    if len(pts_a_undist) < 2:
        raise ValueError("not enough inliers after RANSAC for adjacent camera initialization")

    best_rotation = None
    best_translation = None
    best_score = -1
    projection_a = intrinsic_a @ np.hstack([np.eye(3, dtype=np.float64), np.zeros((3, 1), dtype=np.float64)])
    for rotation_rel, translation_rel in candidates:
        projection_b = intrinsic_b @ np.hstack([rotation_rel, translation_rel.reshape(3, 1)])
        points4d = cv2.triangulatePoints(
            projection_a,
            projection_b,
            pts_a_undist.T.astype(np.float64),
            pts_b_undist.T.astype(np.float64),
        )
        points3d = (points4d[:3] / points4d[3]).T
        depth_a = points3d[:, 2]
        depth_b = (rotation_rel @ points3d.T + translation_rel.reshape(3, 1))[2]
        score = int(np.sum((depth_a > 0.0) & (depth_b > 0.0)))
        if score > best_score:
            best_rotation = rotation_rel
            best_translation = translation_rel
            best_score = score
    if best_rotation is None or best_translation is None:
        raise ValueError("failed to recover a cheirality-valid relative pose")
    return best_rotation.astype(np.float64), best_translation.astype(np.float64)


def initialize_camera_poses_chain(
    camera_order: Sequence[str],
    rows: Sequence[CameraRow],
    camera_params: Dict[str, CameraParams],
    min_pairs: int,
) -> Dict[str, Tuple[np.ndarray, np.ndarray]]:
    """Initialize camera poses by anchoring each new camera to its best parent.

    Rather than chaining strictly in sequence (which compounds errors), each
    camera beyond the first is initialised relative to whichever already-placed
    camera shares the most simultaneous observations with it.  The pair with
    the highest overlap is inherently the most reliable basis for the Essential
    Matrix decomposition, so this strategy keeps initialisation errors local
    and reduces drift for later cameras in the ordering.
    """
    poses: Dict[str, Tuple[np.ndarray, np.ndarray]] = {
        camera_order[0]: (np.eye(3, dtype=np.float64), np.zeros(3, dtype=np.float64))
    }
    initialized: List[str] = [camera_order[0]]

    for current_camera in camera_order[1:]:
        idx_curr = camera_order.index(current_camera)

        # Find the already-initialised camera with the most shared rows.
        best_parent = initialized[0]
        best_count = 0
        for parent in initialized:
            idx_parent = camera_order.index(parent)
            count = sum(
                1 for row in rows
                if row.image_points[idx_parent] is not None
                and row.image_points[idx_curr] is not None
            )
            if count > best_count:
                best_count = count
                best_parent = parent

        idx_parent = camera_order.index(best_parent)
        pair_points_parent: List[np.ndarray] = []
        pair_points_curr: List[np.ndarray] = []
        for row in rows:
            point_parent = row.image_points[idx_parent]
            point_curr = row.image_points[idx_curr]
            if point_parent is None or point_curr is None:
                continue
            pair_points_parent.append(point_parent.astype(np.float64))
            pair_points_curr.append(point_curr.astype(np.float64))

        if len(pair_points_parent) < min_pairs:
            raise ValueError(
                f"best parent pair {best_parent} <-> {current_camera} has only "
                f"{len(pair_points_parent)} usable rows (need {min_pairs})"
            )

        rotation_rel, translation_rel = _select_relative_motion(
            np.asarray(pair_points_parent, dtype=np.float64),
            np.asarray(pair_points_curr, dtype=np.float64),
            camera_params[best_parent].intrinsic_matrix,
            camera_params[current_camera].intrinsic_matrix,
            camera_params[best_parent].distortion_coeffs,
            camera_params[current_camera].distortion_coeffs,
        )
        rotation_parent, translation_parent = poses[best_parent]
        rotation_curr = rotation_rel @ rotation_parent
        translation_curr = (rotation_rel @ translation_parent.reshape(3, 1)).reshape(3) + translation_rel.reshape(3)
        poses[current_camera] = (rotation_curr.astype(np.float64), translation_curr.astype(np.float64))
        initialized.append(current_camera)

    return poses


def _pack_parameters(
    camera_order: Sequence[str],
    camera_poses: Dict[str, Tuple[np.ndarray, np.ndarray]],
    focal_scales: Dict[str, float],
) -> np.ndarray:
    values: List[float] = []
    for camera_id in camera_order:
        values.append(float(focal_scales[camera_id]))
    for camera_id in camera_order[1:]:
        rotation, translation = camera_poses[camera_id]
        values.extend(Rotation.from_matrix(rotation).as_rotvec().tolist())
        values.extend(np.asarray(translation, dtype=np.float64).reshape(3).tolist())
    return np.asarray(values, dtype=np.float64)


def _unpack_parameters(
    params: np.ndarray,
    camera_order: Sequence[str],
) -> tuple[Dict[str, float], Dict[str, Tuple[np.ndarray, np.ndarray]]]:
    n_cameras = len(camera_order)
    focal_scales = {
        camera_order[idx]: float(params[idx])
        for idx in range(n_cameras)
    }
    poses: Dict[str, Tuple[np.ndarray, np.ndarray]] = {
        camera_order[0]: (np.eye(3, dtype=np.float64), np.zeros(3, dtype=np.float64))
    }
    base = n_cameras
    for idx, camera_id in enumerate(camera_order[1:]):
        offset = base + idx * 6
        rotation = Rotation.from_rotvec(params[offset : offset + 3]).as_matrix().astype(np.float64)
        translation = np.asarray(params[offset + 3 : offset + 6], dtype=np.float64)
        poses[camera_id] = (rotation, translation)
    return focal_scales, poses


def _prepare_rows_for_optimization(
    camera_order: Sequence[str],
    rows: Sequence[CameraRow],
) -> List[List[tuple[str, np.ndarray]]]:
    prepared: List[List[tuple[str, np.ndarray]]] = []
    for row in rows:
        observations = [
            (camera_order[idx], point.astype(np.float64))
            for idx, point in enumerate(row.image_points)
            if point is not None
        ]
        if len(observations) >= 2:
            prepared.append(observations)
    return prepared


def bundle_adjust_camera_poses(
    camera_order: Sequence[str],
    rows: Sequence[CameraRow],
    camera_params: Dict[str, CameraParams],
    camera_poses_init: Dict[str, Tuple[np.ndarray, np.ndarray]],
) -> tuple[Dict[str, Tuple[np.ndarray, np.ndarray]], Dict[str, float], Dict[str, Any]]:
    prepared_rows = _prepare_rows_for_optimization(camera_order, rows)
    if not prepared_rows:
        raise ValueError("no multiview rows with at least two observations are available for optimization")
    focal_scales_init = {camera_id: 1.0 for camera_id in camera_order}
    x0 = _pack_parameters(camera_order, camera_poses_init, focal_scales_init)
    lower = np.full_like(x0, -np.inf, dtype=np.float64)
    upper = np.full_like(x0, np.inf, dtype=np.float64)
    lower[: len(camera_order)] = 0.8
    upper[: len(camera_order)] = 1.2

    def residuals(params: np.ndarray) -> np.ndarray:
        focal_scales, camera_poses = _unpack_parameters(params, camera_order)
        residual_values: List[float] = []
        scaled_intrinsics = {
            camera_id: _scaled_intrinsic_matrix(camera_params[camera_id], focal_scales[camera_id])
            for camera_id in camera_order
        }
        for observations in prepared_rows:
            triangulation_rows = []
            for camera_id, image_point in observations:
                rotation, translation = camera_poses[camera_id]
                projection = np.hstack([rotation, translation.reshape(3, 1)])
                triangulation_rows.append((scaled_intrinsics[camera_id], camera_params[camera_id].distortion_coeffs, projection, image_point))
            point_world = _triangulate_multiview_point(triangulation_rows)
            if point_world is None or not np.all(np.isfinite(point_world)):
                residual_values.extend([_LARGE_RESIDUAL_PX, _LARGE_RESIDUAL_PX] * len(observations))
                continue
            for camera_id, image_point in observations:
                rotation, translation = camera_poses[camera_id]
                projected = _project_point(
                    point_world,
                    rotation,
                    translation,
                    scaled_intrinsics[camera_id],
                    camera_params[camera_id].distortion_coeffs,
                )
                residual = image_point - projected
                residual_values.extend(residual.tolist())
        return np.asarray(residual_values, dtype=np.float64)

    result = least_squares(
        residuals,
        x0,
        bounds=(lower, upper),
        loss="cauchy",
        f_scale=2.0,
        ftol=1e-2,
        xtol=1e-4,
        gtol=1e-4,
    )
    focal_scales, camera_poses = _unpack_parameters(result.x, camera_order)
    return camera_poses, focal_scales, {
        "iterations": int(result.nfev),
        "ba_cost": float(result.cost),
        "status": int(result.status),
        "success": bool(result.success),
        "message": str(result.message),
    }
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

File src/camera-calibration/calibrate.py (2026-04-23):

#!/usr/bin/env python3
"""
Camera intrinsic calibration using Charuco boards.

Supports:
- Live capture from Pi Camera (requires picamera2)
- Offline calibration from images (--input-dir)
- Hardware-free self-test mode (--self-test)
"""
from __future__ import annotations


import argparse
import json
from dataclasses import dataclass
from datetime import datetime, timezone
from pathlib import Path
from typing import Any, Dict, List, Optional, Tuple, cast

import cv2
import numpy as np


DEFAULT_SQUARES_X = 6
DEFAULT_SQUARES_Y = 8
DEFAULT_DICTIONARY = "DICT_6X6_250"
DEFAULT_CAMERA = "pi-cam-01"
DEFAULT_SELF_TEST_VIEWS = 30
DEFAULT_MIN_FRAMES = 25
DEFAULT_SEED = 0
SYNTHETIC_IMAGE_SIZE = (1536, 864)  # width, height


@dataclass
class CalibrateConfig:
    """Configuration for calibration."""
    camera: str
    output: Optional[str]
    square_length_mm: float
    marker_length_mm: float
    squares_x: int
    squares_y: int
    dictionary: str
    input_dir: Optional[str]
    self_test: bool
    self_test_views: int
    seed: int
    min_frames: int


def parse_args() -> CalibrateConfig:
    """Parse command-line arguments."""
    parser = argparse.ArgumentParser(
        description="Camera intrinsic calibration using Charuco boards"
    )
    _ = parser.add_argument(
        "--camera",
        "--camera-id",
        dest="camera",
        default=DEFAULT_CAMERA,
        help=f"Camera identifier (default: {DEFAULT_CAMERA})",
    )
    _ = parser.add_argument(
        "--output",
        default=None,
        help="Output JSON path (default: calibration/calibration_intrinsics_v1_{camera}.json)",
    )
    _ = parser.add_argument(
        "--square-length-mm",
        type=float,
        required=True,
        help="Square side length in millimeters (required)",
    )
    _ = parser.add_argument(
        "--marker-length-mm",
        type=float,
        default=None,
        help="Marker side length in millimeters (default: square_length_mm * 20/30)",
    )
    _ = parser.add_argument(
        "--squares-x",
        type=int,
        default=DEFAULT_SQUARES_X,
        help=f"Number of squares in X direction (default: {DEFAULT_SQUARES_X})",
    )
    _ = parser.add_argument(
        "--squares-y",
        type=int,
        default=DEFAULT_SQUARES_Y,
        help=f"Number of squares in Y direction (default: {DEFAULT_SQUARES_Y})",
    )
    _ = parser.add_argument(
        "--dictionary",
        default=DEFAULT_DICTIONARY,
        help=f"OpenCV ArUco dictionary name (default: {DEFAULT_DICTIONARY})",
    )
    _ = parser.add_argument(
        "--input-dir",
        default=None,
        help="Directory containing calibration images (offline mode)",
    )
    _ = parser.add_argument(
        "--self-test",
        action="store_true",
        help="Run hardware-free self-test with synthetic data",
    )
    _ = parser.add_argument(
        "--self-test-views",
        type=int,
        default=DEFAULT_SELF_TEST_VIEWS,
        help=f"Number of synthetic views for self-test (default: {DEFAULT_SELF_TEST_VIEWS})",
    )
    _ = parser.add_argument(
        "--seed",
        type=int,
        default=DEFAULT_SEED,
        help=f"Random seed for self-test (default: {DEFAULT_SEED})",
    )
    _ = parser.add_argument(
        "--min-frames",
        type=int,
        default=DEFAULT_MIN_FRAMES,
        help=f"Minimum valid frames required (default: {DEFAULT_MIN_FRAMES})",
    )
    
    namespace = parser.parse_args()
    
    # Extract values with getattr for safety
    camera = getattr(namespace, "camera", DEFAULT_CAMERA)
    output = getattr(namespace, "output", None)
    square_length_mm = getattr(namespace, "square_length_mm", None)
    marker_length_mm = getattr(namespace, "marker_length_mm", None)
    squares_x = getattr(namespace, "squares_x", DEFAULT_SQUARES_X)
    squares_y = getattr(namespace, "squares_y", DEFAULT_SQUARES_Y)
    dictionary = getattr(namespace, "dictionary", DEFAULT_DICTIONARY)
    input_dir = getattr(namespace, "input_dir", None)
    self_test = getattr(namespace, "self_test", False)
    self_test_views = getattr(namespace, "self_test_views", DEFAULT_SELF_TEST_VIEWS)
    seed = getattr(namespace, "seed", DEFAULT_SEED)
    min_frames = getattr(namespace, "min_frames", DEFAULT_MIN_FRAMES)
    
    # Post-parse validation
    if not isinstance(camera, str) or not camera:
        raise SystemExit("--camera must be a non-empty string")
    if square_length_mm is None:
        raise SystemExit("--square-length-mm is required")
    if not isinstance(square_length_mm, (int, float)) or square_length_mm <= 0:
        raise SystemExit("--square-length-mm must be a positive number")
    if marker_length_mm is not None:
        if not isinstance(marker_length_mm, (int, float)) or marker_length_mm <= 0:
            raise SystemExit("--marker-length-mm must be a positive number")
        if marker_length_mm >= square_length_mm:
            raise SystemExit("--marker-length-mm must be smaller than --square-length-mm")
    if not isinstance(squares_x, int) or squares_x < 2:
        raise SystemExit("--squares-x must be an integer >= 2")
    if not isinstance(squares_y, int) or squares_y < 2:
        raise SystemExit("--squares-y must be an integer >= 2")
    if not isinstance(dictionary, str):
        raise SystemExit("--dictionary must be a string")
    if input_dir is not None:
        if not isinstance(input_dir, str):
            raise SystemExit("--input-dir must be a string")
        if not Path(input_dir).is_dir():
            raise SystemExit(f"--input-dir '{input_dir}' is not a valid directory")
    if not isinstance(self_test, bool):
        raise SystemExit("--self-test must be a boolean flag")
    if not isinstance(self_test_views, int) or self_test_views < 1:
        raise SystemExit("--self-test-views must be a positive integer")
    if not isinstance(seed, int):
        raise SystemExit("--seed must be an integer")
    if not isinstance(min_frames, int) or min_frames < 1:
        raise SystemExit("--min-frames must be a positive integer")
    
    # Compute default marker length if not provided
    if marker_length_mm is None:
        marker_length_mm = square_length_mm * (20.0 / 30.0)
    
    return CalibrateConfig(
        camera=camera,
        output=output,
        square_length_mm=float(square_length_mm),
        marker_length_mm=float(marker_length_mm),
        squares_x=squares_x,
        squares_y=squares_y,
        dictionary=dictionary,
        input_dir=input_dir,
        self_test=self_test,
        self_test_views=self_test_views,
        seed=seed,
        min_frames=min_frames,
    )
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

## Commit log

2026-02-22 refactor: restructure deployment scripts and integrate Pi control protocol
    - Moved deployment scripts from `deploy/` to `src/deploy/` for better organization.
    - Added new Pi capture service in `src/pi/capture.py` with TCP control and UDP frame transmission.
    - Introduced control commands (ping, start, stop, set_exposure, set_gain, set_fps) in `src/host/control.py`.
    - Updated README files to reflect new structure and added details on Pi service integration.
    - Removed old deployment scripts and inventory files from the repository.
    - Added documentation for the Pi control transport protocol in `docs/pi_control_transport.md`.
2026-02-22 refactor: enhance Pi capture service and update control commands
    - Improved the Pi capture service in `src/pi/capture.py` for better performance.
    - Added new control commands (reset, get_status) in `src/host/control.py`.
    - Updated documentation to include new commands and usage examples.
    [LEDHat.kicad_pcb, LEDHat.kicad_sch]
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2026-03-08 docs: update next steps runbook for virtual environment setup and Pi configuration
    - Revised `docs/next_steps_wand_runbook.md` to standardize Python execution under a virtual environment.
    - Added detailed steps for setting up the virtual environment on the Pi, including `camera_id` configuration and capture service initiation.
    - Updated README.md to reflect changes in the runbook and new synchronization features for the GUI.
2026-03-08 feat: update default camera ID handling in capture service
    - Changed the default value of `camera_id` in `src/pi/capture.py` to derive from the device name using `hostnamectl` or fallback to `socket.gethostname()`.
    - Updated argument parsing in `parse_args()` to allow `--camera-id` to be optional, using the new default behavior if not specified.
    - Enhanced documentation in `README.md` to reflect these changes.
2026-03-08 feat: enhance deployment and configuration documentation for Pi and host setup
    - Updated `README.md` and `docs/next_steps_wand_runbook.md` to replace hardcoded IP addresses with placeholders for better clarity.
    - Added instructions for enabling a debug preview in the Pi capture script, allowing real-time visualization of blob detection and parameters.
    - Revised `src/deploy/hosts.ini` to reflect new IP addresses for Pi cameras.
    - Enhanced `src/pi/capture.py` to support a debug preview feature, improving the debugging process during development.
2026-03-08 Update documentation structure and enhance next steps for Charuco and wand calibration processes; remove outdated files and clarify implementation plans.
2026-03-08 Revise README.md to reflect updated project status, implementation phases, and next steps for calibration and tracking GUI development; streamline content for clarity and usability.
2026-03-09 Add new 3D print models and LED board files for the project, including Ball.stl, base.stl, clamp1.stl, plate.stl, and various KiCad files for the LEDHat design. Remove outdated KiCad files to streaml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
    [Ball.stl, LEDHat.kicad_pcb, LEDHat.kicad_sch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]
2026-03-09 Update README.md to include LED board BOM details and remove outdated 3D print models and KiCad files for the LEDHat design, streamlining project resources.
    [Ball.stl, LEDHat.kicad_pcb, LEDHat.kicad_sch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]
2026-03-09 Refactor README.md to enhance clarity and update project details, including the addition of new calibration steps and removal of obsolete information.
2026-03-09 Revise README.md to provide a comprehensive overview of the Loutrack2 project, detailing the workflow, repository structure, and prerequisites for motion capture setup; enhance clarity for new users 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
2026-03-10 Enhance README.md and documentation to clarify tracking GUI features, update calibration instructions, and improve user guidance; add new sections for tracking confirmation and troubleshooting, and r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
    [astro.csv, charts.csv, colors.csv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]
2026-03-10 Enhance README.md and documentation to reflect updates for 4-point wand calibration, including new instructions and troubleshooting steps; update GUI settings for pair window and minimum pairs; refac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
    [calibrate_extrinsics.py, wand_bundle_adjustment.py, wand_label.py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]
2026-03-10 Update README.md and calibration scripts to reflect new wand geometry and confidence scoring system; enhance labeling process with temporal consistency checks and confidence thresholds; update schema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
2026-03-10 Update README.md to reflect changes in calibration workflow, including the introduction of pose capture and wand metric capture; enhance GUI runbook with updated instructions for new capture processe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
2026-03-10 Enhance README.md with details on default downsampling for similarity solve in extrinsics calibration; update calibration JSON schema to include max BA samples; remove obsolete debug GIFs and JSONL l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
2026-03-11 Refactor extrinsics calibration process by updating README.md with new wand geometry and calibration workflow details; enhance calibration JSON schema to include max wand metric samples and expected 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
2026-03-12 Refactor camera calibration scripts to improve wand metric handling and confidence scoring; update README.md with new calibration workflow details and GUI enhancements; modify calibration JSON schema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
2026-03-12 Refactor extrinsics calibration scripts to enhance pose capture and wand metric validation; update README.md with new validation metrics and GUI instructions; modify calibration JSON schema to includ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
2026-03-13 Refactor extrinsics calibration process to focus solely on pose capture, removing wand metric capture from the workflow; update README.md with new instructions and JSON schema changes for extrinsics 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
2026-03-14 Enhance README.md and documentation to include detailed PTP setup instructions for Raspberry Pi, emphasizing the need for `linuxptp` installation and configuration; update capture scripts to improve 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
2026-03-14 Enhance extrinsics calibration workflow by introducing floor and wand metric capture steps; update README.md and GUI runbook to reflect new capture processes and log paths; modify calibration scripts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
    [analyze_pose_segments.py, calibrate_extrinsics.py, filter_pose_log_segments.py]
2026-03-15 Add CLAUDE.md for project guidance and update .gitignore; modify extrinsics calibration scripts to include distortion coefficients in observations and improve triangulation process. Update README.md 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
2026-03-16 Update documentation and JSON schema paths for consistency; add a warning against local directory writing in AGENTS.md. Adjust README.md to clarify current capabilities and repository structure, ensu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
2026-03-16 Update camera calibration and control modules. Modify `calibrate_extrinsics.py` to improve camera pose initialization by selecting the best parent camera based on shared observations, reducing initia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
    [calibrate_extrinsics.py]
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2026-03-24 Enhance intrinsics capture functionality and GUI responsiveness. Update README.md to reflect improvements in phase badge visibility and status synchronization. Modify JSON settings for calibration pa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
2026-03-24 Refactor intrinsics capture process to improve synchronization and error handling. Update README.md with recent changes, including adjustments to `intrinsics_get_corners` for batch fetching and remov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
2026-03-24 Fix Pi runtime activity gating to maintain camera diagnostics when preview rendering is off. Update README.md with recent improvements and add regression test for pipeline runtime continuity. Adjust 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
2026-03-25 Enhance camera management and settings persistence in the GUI. Update `selected_camera_ids` handling to ensure all discovered cameras are considered during status updates, while maintaining user-sele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
2026-04-18 Enhance README.md with detailed updates on host GUI features, including strict camera targeting, runtime-generated capture paths, and improved intrinsics calibration synchronization. Update extrinsic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
    [calibrate_extrinsics.py, extrinsics_scale.py]
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2026-04-20 Enhance performance and diagnostics in tracking and capture systems
    - Updated README.md to reflect improvements in Pi blob-detection and host tracking-viewer integration, including optimizations for idle diagnostics and frame buffer management.
    - Modified `loutrack_gui.py` to improve JSON payload formatting for scene updates.
    - Enhanced `pipeline.py` to streamline pose processing and status tracking.
    - Improved `receiver.py` to ensure correct frame ordering and added methods for frame management.
    - Updated `tracking_runtime.py` to implement a short-lived status cache for efficient scene updates.
    - Enhanced `capture_runtime.py` to manage preview packet generation and diagnostics more effectiv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
2026-04-20 Optimize blob detection and MJPEG streaming performance
    - Updated README.md to highlight improvements in Pi-side tracking, including avoidance of unnecessary static-mask frame copies and conditional processing for diameter and circularity filters.
    - Enhanced `blob_detection.py` to skip filter calculations when filters are inactive, improving efficiency.
    - Modified `capture_runtime.py` and `control_server.py` to integrate a check for active MJPEG clients, ensuring preview packets are only built when necessary.
    - Improved `mjpeg_streamer.py` to manage active client counts, preventing unnecessary encoding when no clients are connected.
    - Added tests to validate the new behaviors in blob detecti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
2026-04-21 Enhance tracking performance and diagnostics
    - Updated README.md to include new features in the tracking GUI, such as SSE scene updates and improved geometry diagnostics.
    - Modified `tracking_pipeline.py` to implement a 10 ms timestamp-only pairing window for frame matching, enhancing synchronization accuracy.
    - Improved `triangulator.py` to utilize one-to-one epipolar assignment for blob matching, preventing duplicate 3D point generation.
    - Adjusted `rigid.py` to refine clustering parameters for better rigid-body candidate selection.
    - Enhanced logging in `tracking_gui.jsonl` to capture detailed diagnostics and performance metrics.
    - Updated HTML and JavaScript in `index.html` to reflect ne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
2026-04-22 Refactor GUI settings and calibration parameters for improved consistency
    - Updated default focus and circularity settings in `gui_settings_store.py`, `loutrack_gui.py`, and `README.md` to fixed values of `0.325` and `0.2`, respectively.
    - Removed focus and circularity settings from the GUI and control commands, streamlining the calibration process.
    - Adjusted HTML and JavaScript in `index.html` to reflect the removal of focus and circularity sliders, ensuring a cleaner user interface.
    - Enhanced tests to validate the new fixed settings and ensure consistent behavior across the application.
2026-04-22 Update camera settings and remove FPS configuration for improved calibration consistency
    - Set fixed capture mode to `1536x864 @ 120fps` for Raspberry Pi Camera Module 3 Wide NoIR across relevant files, including `README.md` and `README_ja.md`.
    - Removed FPS settings from control commands and GUI, streamlining the calibration process and ensuring a consistent user experience.
    - Adjusted HTML and JavaScript in `index.html` to reflect the removal of FPS controls and updated pair window settings.
    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
    [calibrate.py, calibrate_extrinsics.py, extrinsics_scale.py]
2026-04-22 Enhance Raspberry Pi deployment and tracking features
    - Updated README.md to reflect new deployment structure, preserving local `src/pi` and `src/camera-calibration` layouts in each release.
    - Improved `deploy.sh` to install/update a per-camera `loutrack.service` and streamline service management.
    - Enhanced tracking start commands to support PTP/epoch countdowns for synchronized streaming across cameras.
    - Refined extrinsics calibration process to filter out bad captures and improve pose capture logging.
    - Updated GUI components to display enhanced diagnostics and readiness states for tracking, ensuring better user feedback and error handling.
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2026-04-23 STABLE: Update documentation and logging for Pi/GUI procedures and settings
    - Added a new section in `AGENTS.md` detailing the Pi/GUI startup and shutdown procedures.
    - Updated `README.md` to include the new documentation path for Pi/GUI procedures.
    - Revised `docs/README.md` to categorize documentation into operational procedures.
    - Enhanced logging in `loutrack_gui_server.log` to improve tracking diagnostics and error handling.
    - Adjusted `loutrack_gui_settings.json` to update calibration thresholds for improved consistency.
    - Refactored `tracking_gui.jsonl` to capture additional metrics and diagnostics for frame processing and synchronization.
2026-04-23 Update calibration thresholds and enhance logging for improved tracking diagnostics
    - Revised `AGENTS.md` to correct the documentation path for changelog updates.
    - Updated `README.md` to reflect changes in calibration thresholds for exposure, gain, and mask settings.
    - Enhanced logging in `loutrack_gui_server.log` to capture additional tracking commands and server status.
    - Adjusted `loutrack_gui_settings.json` to standardize calibration parameters, including threshold and mask threshold values.
    - Improved error handling in `loutrack_gui.py` to manage connection issues gracefully during MJPEG streaming.
2026-04-23 STABLE: Enhance tracking control with epipolar gate adjustments and update capture settings
    - Introduced a live epipolar gate slider in the Tracking Control, allowing users to set values between `1.0` and `6.0px`, with a default of `3.5px`.
    - Updated the fixed capture mode for Raspberry Pi Camera Module 3 Wide NoIR to `1536x864 @ 118fps`, providing a margin for timing corrections.
    - Revised documentation in `README.md` and `README_ja.md` to reflect the new epipolar gate functionality and updated capture settings.
    - Enhanced logging in `loutrack_gui_server.log` to capture additional tracking commands and diagnostics.
    - Adjusted calibration settings in `loutrack_gui_settings.json` to standardi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
    [calibrate.py]
2026-04-23 Enhance tracking viewer and rigid body management features
    - Introduced rectangle selection for registering and deleting custom rigid bodies in the tracking viewer, with persistence in `calibration/tracking_rigids.json`.
    - Updated host GUI to reflect new rigid body fitting constraints, enforcing a maximum RMS error of `0.055` for valid tracking poses.
    - Enhanced documentation in `README.md` and `README_ja.md` to include details on the new rigid body features and constraints.
    - Improved logging in `loutrack_gui_server.log` to capture additional tracking commands and diagnostics related to custom rigid bodies.
    - Adjusted settings in `loutrack_gui_settings.json` to accommodate the new rigid bod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
2026-04-23 Update tracking viewer features and calibration settings
    - The tracking viewer now hides the green origin dot while retaining the standard world-axis lines.
    - The Tracking Control card no longer displays the raw extrinsics file path banner.
    - Updated sidebar logo to use the new wordmark image instead of the compact badge.
    - Adjusted host tracking to use a fixed `4237 us` half-frame pair window at `118fps`, removing the sync-quality dashboard and adaptive pair-window logic.
    - Updated calibration settings and documentation to reflect these changes in `README.md` and `README_ja.md`.
    [calibrate_extrinsics.py, extrinsics_scale.py, extrinsics_validate.py]
2026-04-24 Phase0: Update tracking viewer features and calibration settings
    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
2026-04-24 Enhance Tracking Replay Harness and GUI Tracking Status
    - Updated the tracking replay harness to extract live diagnostics failure segments and resolve `extrinsics_pose_v2.json` inputs to the calibration directory for replay.
    - Modified the GUI tracking start process to allow ready cameras with zero masked pixels, improving usability.
    - Adjusted the tracking status checks to simplify the conditions for camera readiness.
    - Added tests to validate the new behavior of allowing zero area masks when cameras are ready.
    - Documented changes in `changelog.md` to reflect these enhancements and their implications for tracking diagnostics.
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2026-04-28 Add skippable calibration instructions to Loutrack GUI
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2026-04-30 Refine cad fixtures and red stress simulation
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
